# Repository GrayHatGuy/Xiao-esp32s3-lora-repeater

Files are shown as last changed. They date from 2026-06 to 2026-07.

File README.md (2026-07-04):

# Xiao-esp32s3-lora-repeater

Xiao ESP32S3 LoRa cross-band repeater — **two SX1262 radios on one Xiao**, or **four** by linking a second Xiao over a UART crossover.

Two SX1262 radios stacked on a single Xiao ESP32S3 (2-radio bridge)

*2-radio bridge — two SX1262 shields on one Xiao.*

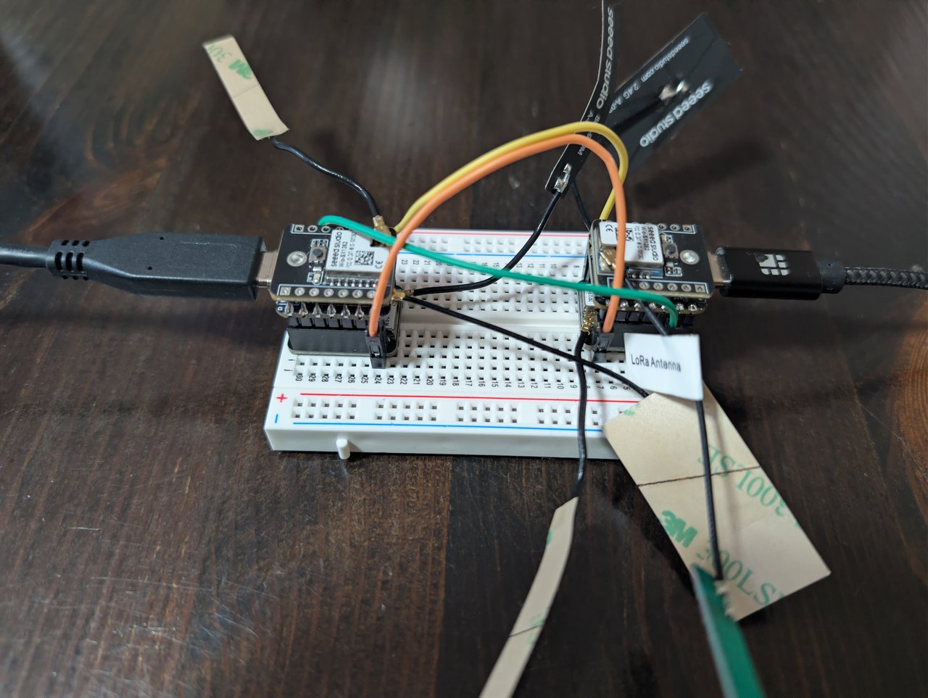
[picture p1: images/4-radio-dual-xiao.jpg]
Four-radio bridge — two Xiao ESP32S3 boards, each with stacked SX1262 shields, joined by a UART crossover on a breadboard


*4-radio bridge — two Xiao linked by a UART crossover (optional).*

## Introduction / Background

A bidirectional LoRa mesh bridge running on a single Seeed Xiao ESP32S3 Sense with two Seeed Wio SX1262 shields stacked back-to-back — one mated to the Xiao's edge pins, the other to the 40-pin B2B header. The two radios share one SPI bus through a FreeRTOS mutex and each run in their own task pinned to a separate ESP32-S3 core, so they can transmit and receive in parallel on completely different RF profiles. **Optionally, two of these boards can be linked over a short UART crossover to expand the bridge to four radios** — one Xiao acts as the *master* (its captive portal owns the config for all four radios) and the second as a *radio co-processor* — for a four-radio omnidirectional repeater. A single Xiao still runs as the original two-radio bridge with no changes; see **Parts**, **Wiring**, and the [config user manual](CONFIG-USER-MANUAL.md) for the four-radio option. The same firmware also builds a **LoRa-commanded camera** — a XIAO ESP32S3 Sense (OV2640 + microSD) plus one edge SX1262, with an always-on WPA2 web portal, signed LoRa command-and-control, and photo/video capture to the SD; see **[LoRaCam](#loracam--lora-commanded-camera)**.

Each radio carries its own protocol **and** its own channel. The bridge relays packets received on one radio out the other — *cross-protocol* (e.g. Meshtastic↔MeshCore) or *same-protocol between two channels* (e.g. a private channel bridged to the public one). Each radio runs one of six protocols: **Meshtastic**, **MeshCore**, **Reticulum**, **LoRaWAN** (keyless tap + keyed ABP uplink encoder), **Custom** (any user-defined RF plan / sync word), or **None** (radio disabled). Everything — region, per-radio protocol, RF plan (frequency, bandwidth, spreading factor, coding rate, sync word, TX power), channels and identity — is configured through the WiFi captive portal; see the **[config user manual](CONFIG-USER-MANUAL.md)** for a field-by-field walkthrough and compile-time preloading. A single `.bin` flashed with no build flags first-boots straight into the portal, so no PlatformIO build is needed to deploy.

Supported today:

- **Meshtastic** (sync `0x2B`) — AES-CTR + a hand-written protobuf walker that lifts `TEXT_MESSAGE_APP` payloads out of the on-air `Data` submessage. `POSITION_APP` and `TELEMETRY_APP` are also decoded and bridged as compact text lines (`pos 40.7234,-74.0123 alt 12m`, `bat 87% 4.05V`, `env 22.5C RH 45% 1013hPa`). Defaults to the public LongFast channel; override `BRIDGE_MT_CHANNEL_NAME` / `BRIDGE_MT_PSK_B64` (or use the captive portal) to bridge a private channel — the PSK can be a short key, a 16-byte AES-128 key, or a 32-byte AES-256 key, and the channel hash is auto-derived. The bridge decodes incoming `NODEINFO_APP` packets into a 64-entry NVS-persistent NodeDB and emits its own periodic NodeInfo so phones surface the bridge as a known sender (`!b16b00b5`, "LoRa Bridge"). It also learns wall-clock time opportunistically from a `POSITION_APP` time field, so bridged MeshCore packets carry a real timestamp.
- **MeshCore channel** (sync `0x12`) — AES-128-ECB decrypt of `GRP_TXT`, with the 2-byte truncated HMAC-SHA256 verified against the channel key. Defaults to the MeshCore public channel (hash `0x11`); override `BRIDGE_MC_KEY_HEX` / `BRIDGE_MC_CHANNEL_NAME` in `platformio.ini` to bridge a private or custom channel instead — the on-air channel-hash byte is auto-derived from `SHA-256(key)[0]` at boot.
- **Reticulum / RNode** (sync `0x42`) — incoming frames are base64-encoded and bridged into the other mesh as text packets of the form `[rns <seq> <x>/<y>] <base64>`. The bridge auto-fragments across multiple MT/MC packets when a single one wouldn't hold the encoded frame, using a CRC-16 low-byte sequence ID so concurrent fragmented frames don't get mixed up on the receiving side. Fragments are paced by the per-radio **airtime throttle** (max 8 fragments per frame, tunable via `BRIDGE_RNS_*`). With both radios set to Reticulum, the bridge **transparently raw-repeats** RNS frames byte-for-byte — a range-extending RNS↔RNS repeater (`BRIDGE_RNS_INPROTO_REPEAT`, on by default). A proper `MT/MC → RNS` packet encoder is still TODO; until then that direction is a log-and-drop path on serial.
- **LoRaWAN** (sync `0x34`, **keyless**) — a localized capture/relay tap, *not* a gateway. The bridge reads only the **cleartext LoRaWAN MAC header** (MType, DevAddr, FCtrl, FCnt, FPort, FRMPayload length; JoinEUI/DevEUI on join-requests) — no keys, no payload decryption, no `FCnt`/MIC synthesis. It can log the header (`evt=RX proto=LW …`), emit a one-line metadata **summary** into your Meshtastic/MeshCore mesh (`BRIDGE_LW_SUMMARY_TO_MESH`), and **transparently raw-repeat** `0x34` frames between two LoRaWAN radios/bridges as a dedup-bounded flood (`BRIDGE_LW_RELAY`) — modeled on the [Tasmota LoRaWAN bridge](https://tasmota.github.io/docs/LoRa-and-LoRaWan-Bridge/). By default `MT/MC → LoRaWAN` is a deliberate log-and-drop (`no-lw-encoder`) — keyless firmware can't inject content. **New in v8.4:** an opt-in **keyed ABP uplink encoder** (`BRIDGE_LW_ENCODE` + ABP session keys) turns that path into a real LoRaWAN encode — it wraps decoded mesh (MT/MC) traffic into a valid LoRaWAN 1.0.x **ABP uplink** (DevAddr + `NwkSKey` + `AppSKey`, AES-CTR FRMPayload, AES-CMAC MIC, monotonic FCnt) and re-emits it over RF for an existing gateway to forward to a ChirpStack LNS. The encoder is **hardware-verified on air** (2026-06-16) — Meshtastic *and* MeshCore frames encode to valid ABP uplinks that decrypt back to the original text with a valid MIC; per-source ABP devices are **captive-portal–configured** with a reboot-safe FCnt, and a raw-LoRa / **Custom** source (the weather-station case) wraps its raw bytes into an uplink too. **The only remaining bench item is ingestion by a live ChirpStack LNS** (Tier C) — see [`BENCH-RESULTS.md`](BENCH-RESULTS.md). Single-channel per radio (no channel hopping, no Class-A RX windows).

### Routing & behavior

Every received packet is decoded once, run through a content-hash loop/dup guard, re-encoded for the *other* radio's protocol, and queued for a non-blocking transmit. The behavior worth calling out:

- **Clean far-side bodies.** The old `[MT !id name]` / `[MC]` / `[rns]` text markers are gone. Loop prevention is now a **TTL content-hash dedup** (FNV-1a over the decoded body + sender id + Meshtastic packet_id, recorded on receive *and* on every emission), which also drops the same packet heard on both radios and never false-drops a user message that happens to start with `[MT`. Folding the packet_id lets a node's genuinely-distinct messages with identical text through each time (new id → new hash) while echoes/replays (same id) still drop.
- **A repeat looks like it came from the original sender, not the bridge.** Cross-protocol **MC→MT** reconstructs the MeshCore sender as a *deterministic virtual Meshtastic node* (id = `FNV-1a("MC|"+name)`) and advertises a synthetic NodeInfo, so a phone shows the message from `Alice @MC`. Cross-protocol **MT→MC** prefixes the body with the Meshtastic sender's name (`Alice@MT: …`, NodeDB short-name or `!hexid`) — the only identity channel MeshCore group text offers. A **same-protocol, same-channel** pair on different frequencies is a *transparent raw repeat*: the original bytes go out unchanged (Meshtastic: hop_limit decremented, `relay_node` set), so the far side sees the original sender natively. The `@MT`/`@MC` origin tags are on by default (`BRIDGE_TAG_ORIGIN_PROTO=0` for bare native-looking names). The whole layer can be disabled with `-DBRIDGE_IDENTITY_PRESERVE=0` (clean-body / bridge-identity behaviour).
- **TX never clobbers RX.** Each radio defaults to receive; an outbound packet goes onto a per-destination, age-bounded, PSRAM-backed queue and is sent by a CAD-gated (listen-before-talk) non-blocking transmit with CSMA backoff and a duty-cycle airtime throttle. So a long SF11 transmit no longer makes the bridge deaf.
- **Structured serial logs.** The runtime log is now one greppable `ts=… evt=… radio=… key=val` line per pipeline event (`RX`/`DEDUP_PASS`/`DROP`/`QUEUE`/`CAD`/`TX_START`/`TX_DONE`/`THROTTLE`/`NODEDB`/`NODEINFO`/`CLOCK`), emitted atomically across both cores.
- **Real timestamps without an RTC (clock-learn).** The bridge has no RTC/NTP, so it *learns* wall-clock time — from inbound MeshCore packet timestamps (**v8.2.1**) and from Meshtastic `POSITION_APP` time (**v8.3**) — and stamps that real Unix time onto bridged MeshCore `GRP_TXT` (surfaced as `mcts=` and a one-time `evt=CLOCK`). Before this, `MT→MC` / `RNS→MC` hardcoded the timestamp to 0 and clients showed *1969*. A cold boot still stamps `0` only until the first timestamped packet calibrates it (inherent without an RTC).
- **Same-protocol transparent repeat spans every protocol.** Two radios on the *same* protocol + channel at *different* frequencies raw-repeat byte-for-byte — a range extender — for Meshtastic, MeshCore, **Reticulum (`RNS↔RNS`, v8.3)** and **LoRaWAN (`LW↔LW`, v8.3)**. The RNS / LoRaWAN repeats are byte-exact (no header mutation — a LoRaWAN MIC would break otherwise), loop-bounded by the shared content-hash dedup + the airtime throttle.
- **LoRaWAN: keyless tap, plus a keyed encoder (v8.4).** A `0x34` radio runs a keyless capture / metadata-summary / `LW↔LW` relay tap (**v8.3**). **v8.4** adds an opt-in **keyed ABP uplink encoder**: with ABP credentials set, `MT/MC → LoRaWAN` becomes a real ABP-uplink encode that RF-re-emits to a gateway → ChirpStack LNS (**hardware-verified on air** — MT *and* MC frames decrypt back, MIC valid; only the live-ChirpStack ingestion bench is open — [`BENCH-RESULTS.md`](BENCH-RESULTS.md)); with no keys it stays the keyless `no-lw-encoder` drop. The two modes are mutually exclusive per radio, selected by ABP config — and as of v8.4 the encoder ships in the standard V1.0/V1.1 build (dormant until configured), so a stock MT/MC bridge is **behaviourally** unaffected.
- **Per-radio routing matrix (4-radio).** With a second Xiao linked over the UART crossover you get four radios, and each one picks which of the others it bridges its received traffic to — a **"bridge received traffic to"** grid in the portal: `R1 → R2/R3/R4`, `R2 → R1/R3/R4`, `R3 → R1/R2/R4`, `R4 → R1/R2/R3`, each destination selectable independently. So you choose the topology — full four-way mesh, two independent pairs, or a one-way feed — rather than a fixed all-to-all. The default two-radio bridge is just `R1 ↔ R2` with R3/R4 disabled; cross-protocol translation and the loop/dup guard apply on every hop exactly as above.

**Everything above is tunable at compile time.** All flags are optional, each documented with its compiled-in default in [`platformio.ini`](platformio.ini); see the **[config user manual](CONFIG-USER-MANUAL.md)** for the full build-flag catalog.

All crypto runs on the ESP-IDF's built-in mbedTLS — no extra library dependencies beyond `jgromes/RadioLib` (pinned `7.7.0`).

**What's new in each release:** see [`CHANGELOG.md`](CHANGELOG.md) for the full per-version changelog. The latest is **v10.0 — LoRaCam**: the same firmware now builds a **LoRa-commanded camera** — a XIAO ESP32S3 Sense (OV2640 + microSD) plus one hand-wired edge SX1262, with encrypted / sender-whitelisted / replay-protected LoRa command-and-control, signed photo & video capture to microSD, and an always-on WPA2 web portal (live MJPEG, snap/record, SD browser, config, pairing) — plus an optional multi-hop C2 relay. All camera code is build-flag-gated (`-DBRIDGE_ROLE_CAMERA`), so the stock bridge binaries stay **byte-identical**; see **[LoRaCam](#loracam--lora-commanded-camera)**, [`LORACAM-SPEC.md`](LORACAM-SPEC.md) and [`BENCH-PHASE3.md`](BENCH-PHASE3.md). Prior release **v9.0 — the optional four-radio bridge**: link a second Xiao over a UART crossover for **four sub-GHz SX1262 radios** driven by a per-radio routing matrix, while a single Xiao stays **fully backwards-compatible** as the original two-radio bridge (R3/R4 default to disabled — see **[Wiring](#wiring)** and the [config user manual](CONFIG-USER-MANUAL.md)). It builds on the **v8.4 LoRaWAN ABP uplink encoder** ([v8.4 release](https://github.com/GrayHatGuy/Xiao-esp32s3-lora-repeater/releases/tag/v8.4-ABP-lorawan)) — **hardware-verified on air** (Meshtastic *and* MeshCore → valid ABP uplinks, decrypt-verified, MIC-valid; only live-ChirpStack ingestion remaining — [`BENCH-RESULTS.md`](BENCH-RESULTS.md)) — and the **[v8.3.1 release](https://github.com/GrayHatGuy/Xiao-esp32s3-lora-repeater/releases/tag/v8.3.1)** (Radio-2 V1.0/V1.1 fix). Design + bench docs: [`CONFIG-USER-MANUAL.md`](CONFIG-USER-MANUAL.md), [`BENCH-v9.0.md`](BENCH-v9.0.md) (four-radio bench), [`ABP-LORAWAN-SPEC.md`](ABP-LORAWAN-SPEC.md).

**Per-protocol summary** — the bridge dispatches by **LoRa sync word**; each radio is assigned a protocol in the portal, and a received packet is decoded once, run through the content-hash loop/dup guard, re-encoded for the *other* radio's protocol, and queued for a CAD-gated non-blocking transmit. Source identity is preserved/reconstructed across the bridge (see [`V8.2-SPEC.md`](V8.2-SPEC.md)).

| Protocol | Sync | RX (decode) | Bridge / TX | Identity across the bridge |
|---|---|---|---|---|
| **Meshtastic (MT)** | `0x2B` | AES-CTR + protobuf walk: `TEXT_MESSAGE_APP`, `POSITION_APP`, `TELEMETRY_APP` → text line; `NODEINFO_APP` → NodeDB (not bridged) | Re-encodes for the destination. **Same channel, different frequency → transparent raw repeat** (original bytes, `hop_limit` decremented) | **MT→MC:** body prefixed `Name@MT:` (NodeDB short-name, else `!hexid`). **MT→MT raw repeat:** original sender preserved natively |
| **MeshCore (MC)** | `0x12` | AES-128-ECB `GRP_TXT` + 2-byte HMAC verify | Re-encodes `GRP_TXT` for the destination channel; same-channel/diff-freq → raw repeat | **MC→MT:** the `"Name: …"` sender becomes a deterministic virtual MT node `FNV-1a("MC|name")` with a synthetic NodeInfo (`Name @MC`); the name is moved into the MT header and stripped from the body |
| **Reticulum (RNS)** | `0x42` | **Not decrypted** — frame treated as opaque bytes (the bridge holds no RNS keys) | **RNS↔RNS:** transparent byte-for-byte raw repeat (range extender, `BRIDGE_RNS_INPROTO_REPEAT`). **RNS→MT/MC:** base64-tunneled as `[rns <seq> <x>/<y>] …` text fragments (CRC-16 seq id, 8-fragment cap, airtime-throttle-paced). **MT/MC→RNS: not implemented** (log-and-drop). See the [Reticulum roadmap](#reticulum--rnode-routing) | n/a — frames opaque; RNS→MT fragments carry the bridge's own MT id |
| **LoRaWAN (LW)** | `0x34` | **Keyless on RX** — cleartext MAC header only (MType / DevAddr / FCtrl / FCnt / FPort / len; JoinEUI/DevEUI on joins); no key, no received-payload decrypt (the **keyed** side is TX-encode only → see Bridge / TX) | **Capture** log + **metadata summary** to MT/MC (`BRIDGE_LW_SUMMARY_TO_MESH`); **LW↔LW transparent raw relay / dedup-bounded flood** (`BRIDGE_LW_RELAY`). **`MT/MC/Custom → LW`: keyed ABP uplink encoder (v8.4, opt-in)** — per-source ABP devices (portal-configured, reboot-safe FCnt) transcode to a valid LoRaWAN ABP uplink (CMAC MIC + AES-CTR FRMPayload + monotonic FCnt); a raw-LoRa **Custom** source sends its raw bytes (weather station). RF-re-emits for a gateway → ChirpStack (**hardware-verified on air**; only live-ChirpStack ingestion pending — [`BENCH-RESULTS.md`](BENCH-RESULTS.md)); default (no keys) stays the keyless `no-lw-encoder` drop | keyless tap: summaries carry the bridge's own MT/MC id. ABP encode: each uplink is sent under a bridge-held ABP device identity (DevAddr) |
| **Custom** | any (portal-entered) | user-chosen sync word; **no built-in decoder** | RF-agnostic dispatch by sync word; a Custom radio with no matching decoder receives + logs but has no protocol-specific re-encode | n/a |
| **None** | — | radio disabled (single-radio / monitor mode) | — | — |

Per-radio fields, the LoRaWAN ABP-device section and every build flag are documented in the **[config user manual](CONFIG-USER-MANUAL.md)**.

## Parts Required

| Part | Notes |
|---|---|
| [Wio SX1262 with Xiao ESP32S3 (B2B 40-pin)](https://www.seeedstudio.com/Wio-SX1262-with-XIAO-ESP32S3-p-5982.html) | Radio 1 (B2B). Kit ships with the Xiao ESP32S3 Sense MCU |
| [Wio SX1262 for Xiao (edge-pin)](https://www.seeedstudio.com/Wio-SX1262-for-XIAO-p-6379.html) | Radio 2, sits on the Xiao's edge-pin header |
| 2 × LoRa antennas tuned for your ISM band | **Don't skip this.** Running an SX1262 at +20 dBm into a missing antenna kills your TX range and risks the PA |
| USB-C cable | Power, programming, serial monitor |

**Optional — four-radio bridge.** Add a **second** of everything above: another *Wio SX1262 with Xiao (B2B)* kit and a *Wio SX1262 for Xiao (edge)* for Radios 3/4, plus **two more antennas**. The two boards are joined with **3 jumper wires** (TX, RX, GND) for the UART crossover; power each board from its own USB-C, or jumper a shared 3V3 rail (see [Wiring](#wiring)). A small breadboard makes the crossover tidy.

*Some assembly required.*

## Wiring

This build uses **stacked shields** — there is no hand-wiring. The B2B SX1262
(Radio 1) mounts on the Xiao's 40-pin board-to-board connector; the edge-pin
SX1262 (Radio 2) mounts on the Xiao's perimeter header. The pin mapping is set in
the firmware (see `src/main.cpp`).

> ⚠️ **The Radio 2 edge module ships in two board revisions (V1.0 / V1.1) with
> different pinouts — you must build the firmware variant that matches yours.**
> Check the silkscreen first: see [Radio 2 module revision](#radio-2-module-revision-v10-vs-v11) below.

The table shows Radio 2 for **both module revisions** — build the env that matches your silkscreen ([how to identify yours](#radio-2-module-revision-v10-vs-v11)). **Bold** marks the four Radio-2 signals that move between V1.0 and V1.1 (NSS, DIO1, BUSY, ANT_SW); the shared SPI bus and RESET are identical on both.

| Signal | Radio 1 (B2B) | Radio 2 — **V1.0** (`xiao_esp32s3`) | Radio 2 — **V1.1** (`xiao_esp32s3_v1_1`) | Notes |
|---|---|---|---|---|
| SCK | GPIO7 (D8)  | GPIO7 (D8) | GPIO7 (D8) | **shared** SPI bus |
| MOSI | GPIO9 (D10) | GPIO9 (D10) | GPIO9 (D10) | **shared** |
| MISO | GPIO8 (D9)  | GPIO8 (D9) | GPIO8 (D9) | **shared** |
| NSS / CS | GPIO41 | **GPIO5 (D4)** | **GPIO4 (D3)** | per-radio chip select |
| DIO1 / IRQ | GPIO39 | **GPIO2 (D1)** | **GPIO1 (D0)** | RX-done interrupt |
| RESET | GPIO42 | GPIO3 (D2) | GPIO3 (D2) | per-radio (same on both revs) |
| BUSY | GPIO40 | **GPIO4 (D3)** | **GPIO2 (D1)** | per-radio |
| ANT_SW | GPIO38 | **GPIO6 (D5)** | **GPIO5 (D4)** | TX/RX RF switch |
| VCC | 3V3 | 3V3 | 3V3 | |
| GND | GND | GND | GND | |

**Optional — four-radio UART crossover.** For the four-radio bridge the two Xiao
boards are joined on their `Serial1` UART (`D6`/`D7`). Both boards run the same
firmware pin defaults, so **the cable does the crossover** — TX on one must reach
RX on the other:

| Master Xiao | → | Co-processor Xiao | Notes |
|---|---|---|---|
| **D6** / GPIO43 (TX) | → | **D7** / GPIO44 (RX) | crossed |
| **D7** / GPIO44 (RX) | ← | **D6** / GPIO43 (TX) | crossed |
| **GND** | — | **GND** | **required** — common ground |
| *3V3 or 5V* | — | *3V3 or 5V* | *only if powering both from one supply (see below)* |

- **Link speed** 460800 baud (override `BRIDGE_LINK_TX_PIN` / `_RX_PIN` / `_BAUD`).
- **Power:** simplest is a **separate USB-C to each board**. To run both from one
  supply, also jumper a **shared 3V3 (or 5V) rail** between them in addition to GND.
- Each board keeps its own two SX1262 shields + antennas — **four antennas total**.

> ⚠️ The data pair must be **crossed**: Master **D6 → co-proc D7** *and* Master
> **D7 → co-proc D6**. An un-crossed pair often looks half-working — one direction
> fine, the return line dead.

**Key points**

- The two radios **share one SPI bus** (SCK/MOSI/MISO); the firmware serializes
  access with a FreeRTOS mutex.
- Each radio has its own **NSS, DIO1, RESET, BUSY, ANT_SW**, so they run
  independently — one task per ESP32-S3 core.
- Radio 1's pins (GPIO38–42) are exposed **only on the 40-pin B2B connector**.
- The TCXO is internal to each Wio SX1262 module (1.8 V) — not wired to a GPIO.
- **Connect both u.FL antennas before power-on** — transmitting into a missing
  antenna risks the PA.
- **Four-radio option:** the second Xiao runs a small co-processor firmware and
  has **no portal of its own** — the master Xiao owns the config for all four
  radios and pushes Radio 3 / Radio 4's RF to the co-processor over the UART link
  at boot (and re-pushes automatically if the co-processor reboots). Leave Radio 3
  / Radio 4 **disabled** (the default) and the master never opens the link — it's a
  plain two-radio bridge.

### Radio 2 module revision (V1.0 vs V1.1)

**Seeed shipped the "Wio-SX1262 for XIAO" edge module with two different
pinouts.** The chip-select (NSS) moved between revisions, so flashing the wrong
variant means **Radio 2 won't be detected** (the bridge keeps running on Radio 1
alone and tells you which env to flash). Identify your module and build the
matching env.

Read the white silkscreen on the **Radio 2** module — both the version string and
the right-hand pin column:

| | **V1.0** | **V1.1** |
|---|---|---|
| Silkscreen | `Wio-SX1262 for XIAO V1.0` | `Wio-SX1262 for XIAO V1.1` |
| Right column (top→bottom) | D0, DIO1, RST, BUSY, **NSS**, RF_SW, D6 | DIO1, BUSY, RST, **NSS**, RF_SW, D5, D6 |
| **NSS** lands on | **D4 / GPIO5** | **D3 / GPIO4** |
| Build env | `xiao_esp32s3` (default) | `xiao_esp32s3_v1_1` |

| V1.0 | V1.1 |
|---|---|
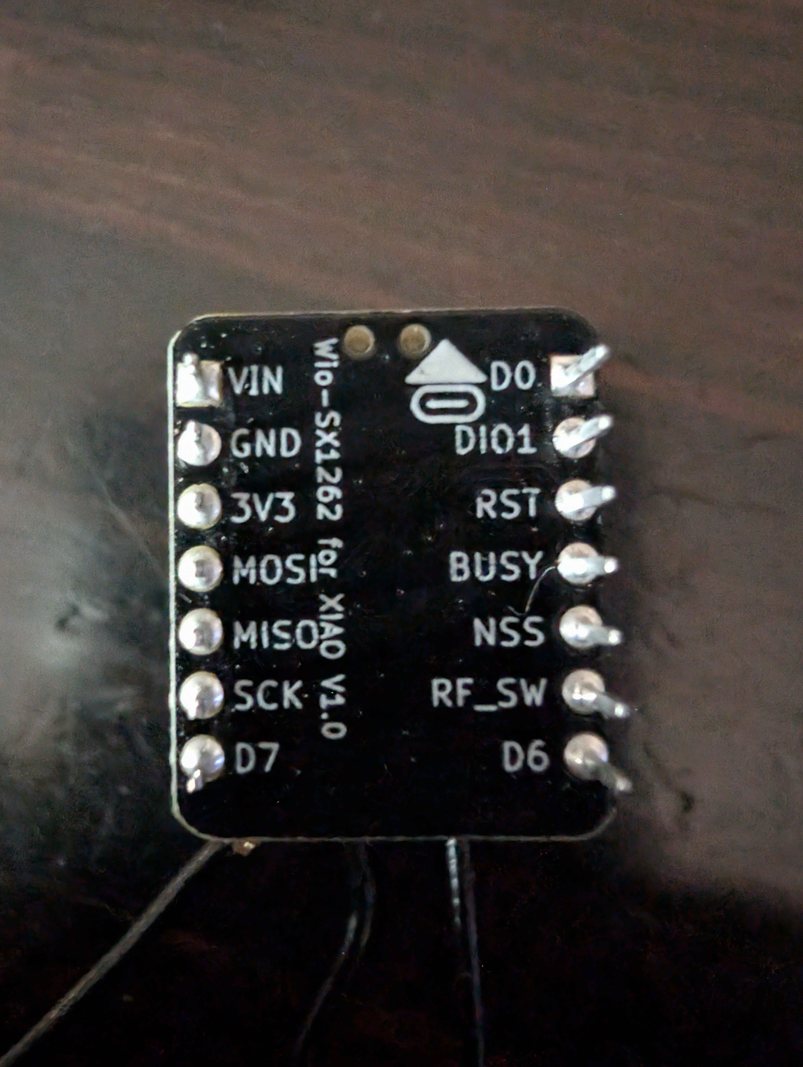
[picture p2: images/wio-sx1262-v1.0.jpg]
Wio-SX1262 for XIAO V1.0 silkscreen
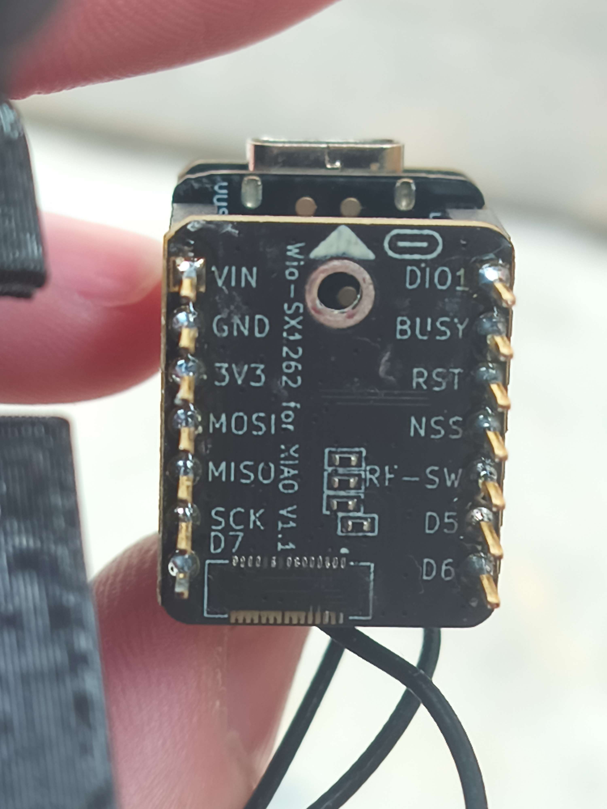
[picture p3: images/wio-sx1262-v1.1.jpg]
Wio-SX1262 for XIAO V1.1 silkscreen
|  |  |

```bash
# V1.0 module (default):
pio run -e xiao_esp32s3      -t upload --upload-port COMx
# V1.1 module:
pio run -e xiao_esp32s3_v1_1 -t upload --upload-port COMx
```

For the **optional four-radio bridge**, the second (co-processor) Xiao is its own
PlatformIO sub-project — build it with `-d coproc-xiao-sx1262`, picking the env that
matches *that board's* Radio-2 silkscreen:

```bash
# Co-processor — V1.0 edge module:
pio run -d coproc-xiao-sx1262 -e xiao_coproc_sx1262      -t upload --upload-port COMx
# Co-processor — V1.1 edge module:
pio run -d coproc-xiao-sx1262 -e xiao_coproc_sx1262_v1_1 -t upload --upload-port COMx
```

The firmware prints the revision it was built for at boot, so you can confirm from
the serial log:

```
[diag] R2 edge module = V1.0  (NSS=5 DIO1=2 RST=3 BUSY=4 RF_SW=6)
```

## LoRaCam — LoRa-commanded camera

**A camera that runs on this same firmware.** LoRaCam is a build variant (`-DBRIDGE_ROLE_CAMERA`) that turns a **XIAO ESP32S3 Sense** — the OV2640 camera, mic and microSD slot already on its rear B2B daughterboard — plus **one Wio SX1262 edge radio** into a LoRa-commanded, WiFi-viewable camera node. It reuses the bridge's radio stack, crypto, captive-config form and do-no-harm gating wholesale; every camera line is compiled only under the camera flag, so the stock bridge binaries stay **byte-identical** (`xiao_esp32s3` = 865781 B). Design of record: [`LORACAM-SPEC.md`](LORACAM-SPEC.md); bench evidence: [`BENCH-PHASE3.md`](BENCH-PHASE3.md), [`BENCH-CAMC2.md`](BENCH-CAMC2.md).

Three ways to use it:

- **Standalone** — the camera's own always-on **WPA2 web portal** does everything: live MJPEG video, snap / record / stop, browse the microSD, and the full radio/identity config form. No second device.
- **Paired** — a LoRa **commander** (any spare XIAO + Wio SX1262 on the same Custom `0x33` channel) sends *signed* commands over LoRa when the camera is out of WiFi range. Encrypted, sender-whitelisted, replay-protected.
- **Multi-hop** — a plain bridge relays those C2 frames commander → repeater → camera, so the camera needn't hear the commander directly (build flag `-DBRIDGE_CUSTOM_REPEAT`, off by default).

**Command-and-control** rides an encrypted binary frame on a **Custom sync-word `0x33`** radio: AES-CTR encrypt-then-MAC with an 8-byte AES-CMAC, a per-peer PSK, and a monotonic replay counter — a valid tag *is* the whitelist. Commands are snap photo, record video, stop, get status, plus operator text messaging. Media itself never travels over LoRa (airtime/duty forbid it) — LoRa carries only the command, the result, and the filename; the portal serves the actual JPEG/AVI. A signed `snap` writes a real 800×600 JPEG to `/loracam/IMG_%05u.jpg` and returns the filename in the ACK; `record` writes an MJPEG-AVI to `/loracam/VID_%05u.avi` (~5 fps, plays in VLC). The microSD shares the radio's SPI bus (CS = GPIO21), serialized by the same mutex.

### Parts — LoRaCam

| Part | Notes |
|---|---|
| [Seeed XIAO ESP32S3 **Sense**](https://www.seeedstudio.com/XIAO-ESP32S3-Sense-p-5639.html) | The Sense daughterboard carries the OV2640 camera, mic **and** microSD — snaps onto the rear 40-pin B2B connector, no wiring |
| [Wio SX1262 for Xiao (edge-pin)](https://www.seeedstudio.com/Wio-SX1262-for-XIAO-p-6379.html) | The single LoRa radio (R2). **Hand-wired with flying leads**, not stacked — see below |
| LoRa antenna (u.FL) tuned for your ISM band | **Fit it before power-on** — the node beacons on boot; TX into a missing antenna risks the PA |
| microSD card | Photo/video storage; formatted FAT32 |
| USB-C cable | Power, programming, serial monitor |

> The B2B (Radio 1) slot is **occupied by the camera/mic bus** (GPIO38–42), so a camera build runs **Radio 1 disabled** and uses only the edge radio. The camera daughterboard and the edge radio's baseboard both want the XIAO's underside, so the edge radio can't stack — it is **hand-wired with 9 flying leads** to the XIAO's edge pins.

### Wiring — LoRaCam (9 flying leads)

Wire the **Wio SX1262 edge module** to the XIAO's edge pins. This is the **same R2 pin map** as the bridge's edge radio ([Wiring](#wiring) above) — flying leads instead of a stacked header. The map below is **V1.0**; for a **V1.1** module use the V1.1 Radio-2 column from the [Wiring table](#wiring) and build with `-DWIO_SX1262_REV=11`. Leave **RF_SW open** (unconnected). The camera, mic and microSD need **no wires** — they're on the rear daughterboard.

| Wio SX1262 edge pad | → | XIAO pin (V1.0) | Notes |
|---|---|---|---|
| 3V3  | → | 3V3 | |
| GND  | → | GND | |
| SCK  | → | D8 (GPIO7)  | shared SPI bus (also the microSD's) |
| MISO | → | D9 (GPIO8)  | shared |
| MOSI | → | D10 (GPIO9) | shared |
| NSS  | → | D4 (GPIO5)  | radio chip select |
| BUSY | → | D3 (GPIO4)  | |
| RST  | → | D2 (GPIO3)  | |
| DIO1 | → | D1 (GPIO2)  | RX-done interrupt |
| RF_SW | | *(leave open)* | not connected |

> ⚠️ **Fit the u.FL antenna before first power-on** — the node TXes a beacon autonomously on boot. A camera-init inrush + TX ramp + SD write can brown-out the 3V3 rail; add bulk capacitance on 3V3 if you see resets.

### Build & flash — LoRaCam

The camera is its own PlatformIO env, `xiao_loracam`. A fresh board **first-boots straight into the WPA2 portal** (no open AP). For a **V1.1** edge module add `-DWIO_SX1262_REV=11`.

```bash
# V1.0 edge module (default):
pio run -e xiao_loracam -t upload --upload-port COMx
# then open the serial monitor to see the AP come up:
pio device monitor --port COMx
```

> ⚠️ `pio run -t erase` wipes the **whole** flash (app included) — always follow it with `-t upload`.

### Using it — the web portal

1. **Join the camera's WiFi.** SSID `LoRaCam-XX` (`XX` = low byte of the MAC-derived node id), WPA2 passphrase `loracam-portal` (change it on the Security tab).
2. **Open** `http://192.168.4.1` and **log in** — default `admin` / `loracam-admin`.
3. **Home** — live MJPEG video, with **snap / record / stop / status** buttons and operator messaging.
4. **Photos** — browse, view, download or delete the photos and videos on the microSD.
5. **Config** — the full radio / identity form (the same one the bridge captive portal serves); **Pairing** — manage the trusted-commander whitelist; **Security** — change the WiFi passphrase and the portal login.

The full field-by-field walkthrough — every portal screen, its build flag, and example setups — is in the [config user manual](CONFIG-USER-MANUAL.md).

### Pairing a LoRa commander

To command the camera over LoRa (out of WiFi range), pair a **commander** — any spare XIAO + Wio SX1262 on the same Custom `0x33` channel. On the camera's **Pairing** page, add the commander's 8-hex C2 id and the shared 32-hex PSK, and mark it **Primary**. On the commander, whitelist the camera with the **same** key. Thereafter the commander mints signed commands and the camera ACKs unicast to whoever sent them; beacons broadcast to any in-range whitelisted commander. For a bench pair, the `bench_camc2` (camera) and `bench_camc2_cmdr` (commander) envs come pre-provisioned — in the commander's serial monitor, type `s` = snap, `r` = record 30 s, `x` = stop, `g` = get-status, `m` = message. Bench record: [`BENCH-CAMC2.md`](BENCH-CAMC2.md).

### Multi-hop

A plain bridge can relay C2 frames **commander → repeater → camera**, so the camera never has to hear the commander directly. Build the relay with `-DBRIDGE_CUSTOM_REPEAT` (a flag-gated Custom same-channel raw-repeat, **off by default** so stock builds stay byte-identical) — set both of its radios to Custom `0x33` on the same channel, on different frequencies, and route `R1 ↔ R2`. Proven on a 3-board frequency-split rig (the camera on `906.875` cannot hear the commander on `905`; with the repeater down, the camera stays silent — a clean negative control). See [`BENCH-PHASE3.md`](BENCH-PHASE3.md) and the [config user manual](CONFIG-USER-MANUAL.md).

## Instructions

> **Fastest path (no toolchain).** **First check your Radio 2 module's silkscreen revision** ([Radio 2 module revision](#radio-2-module-revision-v10-vs-v11) above) and download the **matching** `vanilla-factory` bin from the [latest release](https://github.com/GrayHatGuy/Xiao-esp32s3-lora-repeater/releases/latest): `…-v1.0-vanilla-factory.bin` for a **V1.0** Radio-2 module, `…-v1.1-vanilla-factory.bin` for **V1.1**. Connect both antennas and flash it to offset `0x0` — e.g. `esptool.py --chip esp32s3 write_flash 0x0 <bin>`, or drag it into the [ESP web flasher](https://espressif.github.io/esptool-js/) at address `0x0`. A fresh/erased device first-boots straight into the captive portal, so you can **skip to step 4** (bridge setup). The numbered steps below are for building from source.

1. **Stack the hardware.** Mate the B2B shield (radio 1) on top the Xiao, the edge-pin shield (radio 2) on bottom. Connect antennas to **both** radios before powering on. Correct orientation has all antennas on the same side.
2. **Install [PlatformIO](https://platformio.org/install)** — the VS Code extension is the easiest path.
3. **Build, flash & monitor.** Read the **Radio 2** silkscreen and pick the matching env (see [Radio 2 module revision](#radio-2-module-revision-v10-vs-v11) above): **V1.0** → `xiao_esp32s3` (default), **V1.1** → `xiao_esp32s3_v1_1`. Then erase, clean-build, flash and open the serial monitor (replace `COMx` with your port):
   ```bash
   # --- MASTER Xiao — V1.0 Radio-2 module (default) ---
   pio run -e xiao_esp32s3 -t erase --upload-port COMx     # wipe flash + NVS (boots into the portal)
   pio run -e xiao_esp32s3 -t clean
   pio run -e xiao_esp32s3
   pio run -e xiao_esp32s3 -t upload --upload-port COMx
   pio device monitor --port COMx

   # --- MASTER Xiao — V1.1 Radio-2 module ---
   pio run -e xiao_esp32s3_v1_1 -t erase --upload-port COMx
   pio run -e xiao_esp32s3_v1_1 -t clean
   pio run -e xiao_esp32s3_v1_1
   pio run -e xiao_esp32s3_v1_1 -t upload --upload-port COMx
   pio device monitor --port COMx
   ```
   The clean matters whenever a header changes. Building the wrong variant won't harm anything — Radio 1 still comes up and the boot log names the env to flash — but Radio 2 won't be detected with the default env if your board is **V1.1**, until you flash the matching variant. The boot log echoes the active map:
   ```
   default (V1.0): [diag] R2 edge module = V1.0 (NSS=5 DIO1=2 RST=3 BUSY=4 RF_SW=6)
   V1.1:           [diag] R2 edge module = V1.1 (NSS=4 DIO1=1 RST=3 BUSY=2 RF_SW=5)
   ```
   **Four-radio bridge — also flash the co-processor.** The second Xiao is a
   separate sub-project; build it with `-d coproc-xiao-sx1262` and the env matching
   *its own* Radio-2 silkscreen, on its own COM port:
   ```bash
   # Co-processor — V1.0 edge module (use xiao_coproc_sx1262_v1_1 for a V1.1 module)
   pio run -d coproc-xiao-sx1262 -e xiao_coproc_sx1262 -t erase  --upload-port COM_COPROC
   pio run -d coproc-xiao-sx1262 -e xiao_coproc_sx1262 -t upload --upload-port COM_COPROC
   ```
   The co-processor has no portal and is **silent on its own USB** — it relays its
   status to the master's serial log. With the UART crossover wired, the master
   prints `[coproc] R3 cfg ok …` / `R4 cfg ok …` once the link comes up.
4. **Bridge setup.** A fresh or erased board first-boots into an open WiFi access point named `LoRa-Bridge-XX`; join it from a phone or laptop and any web request redirects to the config form at `192.168.4.1`. There you set device region, per-radio protocol / RF / channel, identity, and the LoRaWAN ABP devices. To re-enter the portal on a configured board, reset it and press **BOOT** or send any serial character within ~5 s (or erase it). **For the full field-by-field walkthrough — every field, its build flag, the LoRaWAN ABP details, and ready-made example setups — see the [config user manual](CONFIG-USER-MANUAL.md).**
5. **Serial Debug Monitor.** Watch the bridge over USB serial. On a four-radio
   bridge, **monitor the master Xiao** — the co-processor relays its logs to the
   master (as `[coproc] …`), so its own USB port stays quiet:
   ```bash
   pio device monitor --port COMx
   ```
   Expect RX summary lines (size / RSSI / SNR), protocol-decoded summaries, bridge re-encode lines, NodeInfo broadcasts, and `loop-drop` messages when relay echoes come back to the bridge.

## Roadmap

### Other future work

- [x] ~~**v10.0: LoRaCam — a LoRa-commanded camera.**~~ — **done**; specced in [`LORACAM-SPEC.md`](LORACAM-SPEC.md). A XIAO ESP32S3 Sense (OV2640 + microSD) + one hand-wired edge SX1262 becomes a camera node: encrypted / sender-whitelisted / replay-protected C2 over Custom `0x33` (AES-CTR encrypt-then-MAC, 8-byte CMAC, per-peer PSK, monotonic replay counter), signed photo (`/loracam/IMG_*.jpg`) & video (`/loracam/VID_*.avi`) capture to microSD, an always-on **WPA2 web portal** (live MJPEG + snap/record/stop + SD browser + the config form + pairing + messaging), secure first-flash, and optional multi-hop C2 relay (`-DBRIDGE_CUSTOM_REPEAT`). All build-flag-gated (`-DBRIDGE_ROLE_CAMERA`) → stock bridge binaries **byte-identical**. Bench-proven on silicon ([`BENCH-PHASE3.md`](BENCH-PHASE3.md), [`BENCH-CAMC2.md`](BENCH-CAMC2.md)). See **[LoRaCam](#loracam--lora-commanded-camera)**.

- [x] ~~More Meshtastic portnums bridged: `POSITION_APP` and `TELEMETRY_APP`~~ — **done**; both decoded and re-emitted as text under the existing bridge marker. Individually gated by `BRIDGE_MT_POSITION` / `BRIDGE_MT_TELEMETRY` build flags. `NODEINFO_APP` is decoded into the NodeDB and intentionally not bridged as text.
- [x] ~~MeshCore private-channel support~~ — **done** via `MeshCoreConfig.{h,cpp}`; override `BRIDGE_MC_KEY_HEX` and `BRIDGE_MC_CHANNEL_NAME` in `platformio.ini` to point the bridge at any MC channel. The hash byte is computed automatically from `SHA-256(key)[0]`.
- [x] ~~Persistent NodeDB so `[MT] …` prefixes can be replaced with the actual sender's short name~~ — **done** in `NodeDB.{h,cpp}`; MT→MC bridged messages now carry `[MT !<hexid> <SHORT>] …` attribution learned from `NODEINFO_APP` packets and persisted to NVS.
- [x] ~~**WiFi captive-portal first-boot config.**~~ — **done** via `BridgeConfig.{h,cpp}` + `CaptivePortal.{h,cpp}`. On a fresh flash (or whenever the BOOT button is pressed within ~3 s of reset) the bridge brings up an open AP named `LoRa-Bridge-<XX>` and DNS-redirects all HTTP traffic to a config form for MT identity, MC key + channel name, and the POSITION/TELEMETRY toggles. Saving the form writes the schema-v1 blob to NVS and reboots into bridge mode. Per-radio LoRa params (frequency, BW, SF, CR, TX power, sync word) remain build-flag-only — a misstep there can put the radio out of band.
- [x] ~~**F5: Meshtastic private-channel support.**~~ — **done** via `MeshtasticConfig.{h,cpp}` (the symmetric counterpart to F3). A base64 PSK + channel name from `BridgeConfig` are expanded — empty→LongFast, 1-byte short key, 16-byte AES-128, 32-byte AES-256 — and the on-air channel hash is derived as `XOR-fold(name) ^ XOR-fold(key)`. The five MT decoders + two MT encoders take key length from `MeshtasticConfig::keyLen` so AES-256 channels work. `BridgeConfig` schema bumped to v2 (auto-migrates a v1 blob); captive portal gained a Meshtastic-channel section.

- [x] ~~**v2: per-radio channels — same-protocol relay.**~~ — **done** (v7.0). Each radio slot carries its own channel via the new `RadioChannel` struct (`MeshCoreConfig` / `MeshtasticConfig` are now stateless `resolve()` helpers, not singletons). The bridge relays cross-protocol MT↔MC *and* same-protocol MC↔MC / MT↔MT. Each radio's protocol/RF stays a `platformio.ini` build-flag decision; each radio's channel name + key is portal-editable. `BridgeConfig` schema bumped v2→v3 (auto-migrates). The portal's two channel sections reject identical channels when both radios share a protocol.
- [x] ~~**v8: vanilla firmware — full portal config.**~~ — **done** (v8.0); specced in [`V8-SPEC.md`](V8-SPEC.md). A single distributable `.bin` configured *entirely* through the captive portal — no build flags required. Per-radio protocol picker (Meshtastic / MeshCore / Reticulum / Custom / None), global region selector (US, EU_868, EU_433, ANZ, CN, JP, IN, KR, RU + Custom/Other), Tier 2 Meshtastic channel-slot frequency computation (`RegionPreset.h`) with an editable override, null defaults (a no-flag image first-boots straight into the portal), and MAC-derived identity/SSID. `BridgeConfig` schema v3→v4. `platformio.ini` `LORA_RADIO*` flags are now optional first-boot pre-seeding only.
- [x] ~~**Compile-time validation of build-flag config.**~~ — **done** (v8.1) in [`src/LoraConfigCheck.h`](src/LoraConfigCheck.h). `#error` / `static_assert` guards reject an invalid `LORA_RADIO*` set at build time (sync words, SF/CR/BW/region sanity, TX power range). Complements the v8 portal-side runtime validation — build-time checks defaults, portal checks portal-entered values.

- [x] ~~**v8.2: RX-priority routing redesign + source-identity preservation.**~~ — **done** (v8.2), bench-verified 2026-06-13; specced in [`V8.2-SPEC.md`](V8.2-SPEC.md). Non-blocking CAD-gated TX + per-destination PSRAM route queues + airtime throttle (a transmit no longer blocks the other radio's RX); content-hash dedup keyed on body + sender id + Meshtastic packet_id (replaces the `[MT]/[MC]/[rns]` text markers → clean far-side bodies); source-identity preservation (MC→MT virtual nodes + synthetic NodeInfo, MT→MC name prefixes, same-channel transparent raw repeat); structured `evt=` serial logging; RadioLib pinned 7.7.0.

- [x] ~~**v8.3: keyless LoRaWAN + carry-overs.**~~ — **done & shipped** (v8.3), bench-validated on hardware 2026-06-14; specced in [`V8.3-SPEC.md`](V8.3-SPEC.md). Keyless LoRaWAN (`0x34`) capture tap + metadata summary to MT/MC + transparent LW↔LW raw relay / dedup-bounded flood (`MT/MC → LoRaWAN` is a `no-lw-encoder` drop); transparent **RNS↔RNS** raw repeat; and Meshtastic `POSITION_APP` clock-learn. `BridgeConfig` schema v4 unchanged.

- [x] ~~**v8.4: LoRaWAN ABP uplink encoder (keyed).**~~ — **shipped** in v8.4 (build-green, crypto-verified, **hardware-verified on air**); specced in [`ABP-LORAWAN-SPEC.md`](ABP-LORAWAN-SPEC.md). A self-contained **RFC 4493 AES-CMAC** (the prebuilt esp32s3 mbedTLS ships CMAC disabled) + `encodeLoRaWANUplink()` mint valid LoRaWAN 1.0.x **ABP uplinks** (AES-CTR FRMPayload, CMAC MIC, monotonic FCnt, ADR off, Unconfirmed). The keyless `no-lw-encoder` drop becomes a keyed transcode → `g_routeQ` **RF re-emit** (delivery model B1) when ABP credentials are configured — opt-in via `BRIDGE_LW_ENCODE` + keys, so a stock build keeps v8.3's keyless behavior. Crypto cross-checked against an independent CMAC (RFC 4493 vectors + a MIC-valid, round-tripping frame). **P2–P4 also done:** per-source ABP devices + a captive-portal section + reboot-safe NVS FCnt (P2), the Custom raw-LoRa **weather-station** path + a sample ChirpStack codec (P3), and a US915 per-TX dwell cap (P4). The **hardware bench is complete** (12/16 — A1–B7 + A3, MT *and* MC verified — [`BENCH-RESULTS.md`](BENCH-RESULTS.md)); **live-ChirpStack (Tier C) ingestion is the one remaining gate** ([`BENCH-v8.4.md`](BENCH-v8.4.md)). v8.4 also added captive-portal **auto-fill of RF defaults on protocol switch** (a protocol change no longer leaves stale freq/BW/SF — the slip that cost a bench session).

**Next, in priority order — protocol routing comes _ahead of_ the Sub-GHz↔2.4 GHz cross-band phase below:**

- [ ] **Reticulum `MT/MC → RNS` encoder + reassembly.** RNS↔RNS repeat and RNS→MT/MC tunneling shipped in v8.3; the remaining half is a real RNS packet encoder (build a valid frame) plus `reassembleReticulumFragment()` so `MT/MC → RNS` works. Current state + work list in [Reticulum / RNode routing](#reticulum--rnode-routing) below.
- [ ] **LoRaWAN ABP *decode* + OTAA + dual-LNS (post-v8.4).** The keyless tap (v8.3) and the full **ABP uplink *encode*** (`MT/MC/Custom → LoRaWAN` — per-source portal devices P2, the Custom weather-station path + codec P3, and a US915 dwell cap P4) landed in **v8.4** (above), pending on-air bench. Remaining: the optional ABP/OTAA **decode** of your own fleet (→ MT/MC) and the dual-LNS crosslink — see [`ABP-LORAWAN-SPEC.md`](ABP-LORAWAN-SPEC.md). Content bridging without keys stays architecturally precluded (analysis in [`V8.2-SPEC.md`](V8.2-SPEC.md) §14).

- [ ] **Sub-GHz ↔ 2.4 GHz LoRa cross-band bridging — Phase 1 ON HOLD pending Seeed clarification.** The current build talks the SX1262's native sub-GHz ranges (902-928 MHz US ISM, 868 MHz EU, etc.). A long-horizon goal is to bridge those to 2.4 GHz LoRa networks (e.g. Meshtastic's 2.4 GHz preset) on the worldwide-licence-free **2.4 GHz ISM band** — the headline feature that makes this milestone worth doing.

  > **⚠️ Phase 1 status (2026-05-27): bench DOE complete — all firmware remedies refuted; Seeed engineering inquiry sent with full evidence package.** A first attempt at this milestone using the **Seeed Wio-LR1121 module (SKU 113991415)** as Radio 2 reached a hard block: TX works end-to-end (other LoRa receivers see the bridge's transmissions), but RX produces zero `RX_DONE` events for any over-the-air traffic — even with a transmitting MT phone's antenna physically pressed against the LR1121's antenna port. We then executed two full Design-of-Experiments (DOE) investigation phases per the **Semtech LR1121 User Manual v2.2** ([direct PDF](https://semtech.my.salesforce.com/sfc/p/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) · [product page](https://www.semtech.com/products/wireless-rf/lora-connect/lr1121)):
  >
  > - **Phase A — RFSWx switch-table sweep (12 iterations).** All 5 chip-level RFSWx-capable DIOs (DIO5/6/7/8/10 per UM §4.2.1) swept in every meaningful combination. Self-echo RSSI invariant within ~7 dB across all iterations. Zero OTA `RX_DONE`. Seeed's published KiCad library separately confirms DIO5/6/7 are routed as `MCU_DIO5/6/7` host-expansion test pads, **not** used as switch outputs on this module.
  > - **Phase B — Chip-init DOE (4 effective runs).** Tested every UM v2.2-prescribed firmware remedy individually and combined: `SetRssiCalibration` with UM Table 7-21 "600 MHz – 2 GHz" tunes (Run 2), `CalibImage(902, 928)` after `SetTcxoMode` (Run 3), and the kitchen-sink stack with pre-`Standby(STBY_RC)` + RSSI cal + image cal + `SetRxBoostedGainMode(true)` (Run 5). Every command returned `state=0`. **None resolved the RX failure.** Two new pieces of hard evidence emerged: (a) the chip's `GetErrors()` register reads `0x0020 = HF_XOSC_START_ERR` persistent at every POR on every unit, and (b) one `RADIOLIB_ERR_CRC_MISMATCH` event in Run 5 — meaning the RX chain is partially functional but with sensitivity degraded by an estimated 40–50 dB versus LR1121 datasheet spec. Two independently-sourced units behave identically.
  >
  > **All UM v2.2-prescribed firmware remedies have been tested. None resolves the failure.** Remaining hypothesis space: hardware-design issue (matching network, switch insertion loss, LNA isolation) or LR1121 chip firmware errata at base FW 1.3. The full bug report ([`SEEED_SUPPORT_INQUIRY.md`](https://github.com/GrayHatGuy/Xiao-esp32s3-lora-repeater/blob/lr1121-phase1/SEEED_SUPPORT_INQUIRY.md)) with the DOE evidence appended, the design-feedback companion ([`SEEED_RECOMMENDATIONS.md`](https://github.com/GrayHatGuy/Xiao-esp32s3-lora-repeater/blob/lr1121-phase1/SEEED_RECOMMENDATIONS.md)), the full DOE bench plan + results ([`LR1121-RX-INIT-AUDIT.md`](https://github.com/GrayHatGuy/Xiao-esp32s3-lora-repeater/blob/lr1121-phase1/LR1121-RX-INIT-AUDIT.md)), and the locked-in email body ([`SEEED_EMAIL_DRAFT.md`](https://github.com/GrayHatGuy/Xiao-esp32s3-lora-repeater/blob/lr1121-phase1/SEEED_EMAIL_DRAFT.md)) all live on the [`lr1121-phase1`](https://github.com/GrayHatGuy/Xiao-esp32s3-lora-repeater/tree/lr1121-phase1) branch and at the snapshot tag [`lr1121-bringup-2026-05-26`](https://github.com/GrayHatGuy/Xiao-esp32s3-lora-repeater/tree/lr1121-bringup-2026-05-26) for Seeed-correspondence stability. **`main` continues to ship the Phase 0 dual-SX1262 release (now v8.3.1, with v8.4 in progress on `dev-ABP-lorawan`).** Phase 1 will resume on Seeed engineering's reply, or via pivot to an alternate LR1121 carrier (Semtech LR1121DVK1, Ebyte E80-900M22S, or custom).

  **Minimum viable hardware change:** keep the existing Xiao Wio-SX1262 on one of the two slots, and swap *only the other slot* for a radio that can reach 2.4 GHz. The bridge needs exactly one 2.4-GHz-capable side; the SX1262 stays as the sub-GHz endpoint.

  **Prototype target:** the **Seeed Wio LR1121 breadboard** — already on hand, RadioLib-supported, multi-band on one die (sub-GHz **+ 2.4 GHz + S-band 1.9-2.1 GHz**), plus LR-FHSS. For this bridge it sits on the 2.4 GHz slot opposite the existing Xiao Wio SX1262; longer-term a single LR1121 could replace *both* SX1262s if collapsing to one radio family becomes interesting.

  Other Semtech parts to track for later, in roughly increasing capability:
  - **SX1280** — 2.4 GHz only (~2400-2500 MHz). Cheapest and narrowest; useful if a smaller, lower-cost run is ever in scope.
  - **LR22xx series** (e.g. LR2021) — newer multi-band parts: SX1280-class 2.4 GHz, improved sensitivity, BLE-coexistence awareness, expanded LR-FHSS modes. Worth watching as RadioLib support matures.

  **MCU upgrade is conditional, not required.** If a Xiao-compatible 2.4 GHz module turns up (or can be hand-wired onto the edge pins next to the existing B2B Wio shield) the Xiao ESP32S3 Sense stays in service and the form factor barely changes. If the only available SX1280 / LR1121 carriers want full 0.1"-header access, the natural upgrade target is the **ESP32-S3 DevKitC-1 N-R** (e.g. N8R8 — standard ESP32-S3-WROOM-1 dev board with N flash + R PSRAM): ~40 broken-out GPIOs, more flash + PSRAM, and the ability to wire arbitrary off-the-shelf breakouts. `WioSX1262.{h,cpp}` already abstracts pin assignments, SPI bus sharing, and the mutex — switching MCU boards would mean a new `pinout.h` (or per-board `#ifdef` block) and not much else.

  Good news on the firmware side: the protocol decoders and `bridgePacket()` dispatcher in this repo are RF-agnostic — they branch on the LoRa sync word, not the carrier frequency. Once a `WioSX1280` / `WioLR1121` / `WioLR2021` wrapper lands alongside `WioSX1262` (same `LoraConfig` struct, same `available()` / `read()` / `transmit()` surface), the existing bridge pipeline drops straight in with RF parameter changes in `platformio.ini`.

### Reticulum / RNode routing

Prioritized **ahead of** the Sub-GHz↔2.4 GHz cross-band phase above, but it stays
a firmware concern — **no RNS controls will be added to the captive portal.** The
`0x42` sync word is wired into the dispatcher as a third protocol; as of v8.3 the
receive half **and** transparent RNS↔RNS raw repeat are implemented (current state in the
[Routing & behavior](#routing--behavior) per-protocol table):

| Direction | Status |
|---|---|
| `RX:RNS → TX:RNS` (both radios Reticulum) | ✅ **v8.3** — transparent byte-for-byte raw repeat (`BRIDGE_RNS_INPROTO_REPEAT`, on by default). |
| `RX:RNS → TX:MT or MC` | ✅ base64 text tunnel — raw bytes re-transmitted as `[rns <seq> <x>/<y>] <base64>` fragments (CRC-16 seq id, 8-fragment cap, airtime-throttle-paced). |
| `RX:MT or MC → TX:RNS` | ❌ log-and-drop — no RNS encoder yet (`encodeReticulum()` returns false). |
| `RX:RNS → human-readable decode` | ❌ opaque base64 only — RNS frame framing isn't parsed. |
| `MT/MC fragment reassembly → RNS TX` | ❌ `reassembleReticulumFragment()` stub present, no logic. |

**To make it bidirectional** (the work behind the three ❌ rows): an **RNS packet
decoder** (parse header byte / IFAC flag / hops / address hashes / context /
ciphertext → structured line in `MeshDecoderDebug.h`), an **RNS packet encoder**
(build a valid frame in `MeshEncoderDebug.h` — a one-line dispatcher wire-in
once it exists), and **fragment reassembly** (fill in `reassembleReticulumFragment()`:
accumulate `[rns <seq> <x>/<y>]` slots keyed on `<seq>`, base64-decode, ~30 s
timeout, emit when complete). Optional **IFAC** HMAC-SHA256 trailer/salt handling
comes along only if talking to an authentication-enabled network.

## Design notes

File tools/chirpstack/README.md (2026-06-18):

# ChirpStack integration — device-profile templates + payload codec

Everything needed to ingest the bridge's **LoRaWAN ABP uplinks** into a
[ChirpStack](https://www.chirpstack.io/) v4 server: importable **device-profile
templates** (one per region) and the JavaScript **payload codec**.

The bridge's keyed ABP encoder (v8.4) re-emits mesh / Custom traffic as a valid
LoRaWAN **Class-A, ABP** uplink; a separate gateway forwards it to ChirpStack.
These templates describe that device so the codec decodes the payload server-side.

## Layout

```
tools/chirpstack/
└── vendors/grayhatguy/
    ├── vendor.toml                         # vendor identity + device list
    ├── devices/xiao-lora-bridge.toml       # firmware 8.4 -> profiles + codec
    ├── profiles/
    │   ├── xiao-bridge-abp-US915.toml      # one ABP profile per region
    │   ├── xiao-bridge-abp-AU915.toml
    │   ├── xiao-bridge-abp-AS923.toml
    │   └── xiao-bridge-abp-EU868.toml
    └── codecs/
        ├── xiao-bridge.js                  # = tools/chirpstack-codec.js (kept in sync)
        ├── test_decode_xiao-bridge.json
        └── test_encode_xiao-bridge.json
```

> **Region status:** **US915** is hardware-bench-verified. **AU915 / AS923 / EU868**
> are authored from RP002-1.0.3 but **not yet bench-verified**. **OTAA** is not
> included — these profiles are **ABP only** (`supports_otaa = false`); an OTAA
> profile will be added when the OTAA firmware ships in a later release.

## Importing the templates

**Bulk (template repo):** point ChirpStack's importer at this folder:

```
chirpstack -c /etc/chirpstack import-device-profiles -d /path/to/tools/chirpstack
```

Then in the web UI: **Device profiles → Add → "Select device-profile template" →
GrayHatGuy → Xiao ESP32-S3 Dual-SX1262 LoRa Bridge → FW 8.4 → (your region)**.

**Manual (no import, fastest for 1–2 devices):** create a Device Profile by hand
using the values from the matching `profiles/*.toml`
(MAC version **1.0.3**, region e.g. **US915**, **Class A**, **ADR off**), then open
its **Codec** tab, set **"JavaScript functions"**, and paste the whole
[`codecs/xiao-bridge.js`](vendors/grayhatguy/codecs/xiao-bridge.js)
(identical to [`tools/chirpstack-codec.js`](../chirpstack-codec.js)).

## Creating the device (per-device keys go HERE, never in the template)

Create the device under the profile and enter the **ABP session** matching the
bridge's portal (or build-flag) credentials:

| ChirpStack field | Value | Where it comes from |
|---|---|---|
| Device address (DevAddr) | e.g. `01000001` | portal "LoRaWAN ABP devices" slot, or `BRIDGE_LW_ENC_DEVADDR` |
| Network session key (NwkSKey) | 32 hex | portal slot, or `BRIDGE_LW_ENC_NWKSKEY` |
| Application session key (AppSKey) | 32 hex | portal slot, or `BRIDGE_LW_ENC_APPSKEY` |
| Frame-counter validation | **disabled** (or persist) | the bridge reserves FCnt in blocks |

## Per-device codec options (ChirpStack Device → Variables)

The codec reads two optional device **variables** so one pasted codec serves
mixed devices without edits:

| Variable | Set to | Effect |
|---|---|---|
| `source_tag` | `true` | this device has the portal "Prepend source tag" enabled — the codec splits the leading `[proto][srcId]` tag into `data.source` |
| `station_fport` | e.g. `13` | the FPort whose payload is a raw weather-station frame (routed to `decodeStation()`) |

If a variable is absent, the codec's `DEFAULT_SOURCE_TAG` / `DEFAULT_STATION_FPORT`
constants apply.

## Weather-station payload

`decodeStation()` in the codec is a **placeholder** layout — the bridge forwards a
Custom raw-LoRa station's bytes verbatim, so only the station's own datasheet
defines the format. Edit `decodeStation()` to your station's real byte layout
(field order / width / endianness / scaling), then update
`test_decode_xiao-bridge.json` to match.

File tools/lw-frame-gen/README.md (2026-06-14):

# lw-frame-gen — LoRaWAN (sync 0x34) test-frame generator

Standalone firmware that transmits the canonical hand-built LoRaWAN frames from
[`../../BENCH-v8.3.md`](../../BENCH-v8.3.md), so you can bench the v8.3 LoRaWAN
**capture / summary / relay / flood** features **without a real LoRaWAN gateway
or end-device**. The bridge only reads the cleartext MAC header, so an
unencrypted hand-built frame is all it needs.

## Hardware
A Xiao ESP32-S3 + Wio-SX1262 — i.e. **one of your bridges, temporarily reflashed**
(e.g. the COM6 unit). It transmits on **Radio 1** (the B2B-header radio), using
the same pins / SPI / TCXO (1.8 V) / DIO2 RF-switch as the bridge. Reflash the
bridge firmware (`pio run -e xiao_esp32s3 -t upload` from the repo root) when done.

## Flash + run
From **this** folder:

    pio run -t upload
    pio device monitor          # 115200 baud

## RF profile — match the DUT
The generator's RF **must equal the DUT's LoRaWAN radio exactly** (freq / BW / SF
/ CR / sync 0x34) or the DUT will not demodulate — the #1 cause of a silent
`LW-RX`. Defaults are bench profile **P-LW+MT, Radio 1**: `904.6 MHz / BW125 /
SF7 / CR5 / 20 dBm`. Change them in [`platformio.ini`](platformio.ini) (`GEN_*`)
and re-upload. For the **relay/flood** pass, keep the generator on **freqA**
(DUT-A R1); the DUT relays out on freqB to DUT-B.

## Use
In the generator's serial monitor:

| Key | Frame | DUT should log |
|---|---|---|
| `1` | FRAME-U  (UnconfDataUp) | `proto=LW mtype=UnconfDataUp devaddr=0x26011f8a fcnt=1 fport=2` |
| `2` | FRAME-U2 (FCnt 2) | distinct frame — passes dedup |
| `3` | FRAME-D  (ConfDataUp, no FPort) | `fport=-1` |
| `4` | FRAME-J  (JoinRequest) | `mtype=JoinRequest`; summary `DevEUI 0004a30b001a2b3c` |
| `5` | FRAME-C  (11 B) | `parse=fail` |
| `n` | next in cycle | (the **BOOT button** also sends next) |

- **LW-LOOP / dedup:** press `1` twice within 60 s → the DUT logs a capture then
  `drop=lw-dup`.
- **LW-RELAY / LW-FLOOD:** point the generator at DUT-A's R1 freq and watch DUT-A
  relay (`mode=raw`) to DUT-B.
- **Hands-off:** set `GEN_AUTO_MS` > 0 to auto-cycle through all five frames.

The RF profile, the frame name/length, the TX return code, and the expected DUT
decode are printed at boot and on every send, so you can cross-check the DUT log.

Frame bytes are decode-verified against `extractLoRaWANMeta()` in
`src/MeshDecoderDebug.h`.

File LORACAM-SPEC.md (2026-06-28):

# LoRaCam — Spec (DRAFT, for agreement)

**Status:** DRAFT — core decisions **Q1–Q4 LOCKED 2026-06-28** (see §9). Nothing built. No code on shared paths yet.
**Branch:** `lora_cam_xiao` (off `main` @ `24528ad` = v9.0). Remote unchanged (`GrayHatGuy/Xiao-esp32s3-lora-repeater`).
**Date:** 2026-06-28.
**Foundation:** the v9.0 four-radio repeater firmware in this clone. HW feasibility:
`C:\Users\6r4yh\XIAO-Sense-Wio-SX1262-Compatibility-Handoff.md`. Camera reference:
`…\Projects\CameraWebServer_for_esp-arduino_3.0.x-seeed_xiao_esp32s3` (read-only).

> This doc is the working agreement. Sections marked **[DECISION]** need owner sign-off; **[PROPOSED]**
> are my recommendations to confirm or veto. Grounded in a 6-agent read of the repeater + camera codebases.

---

## 1. Goal

A XIAO ESP32-S3 **Sense** (OV2640 camera + mic + microSD on the rear B2B 40-pin) + a **perimeter-pin
Wio-SX1262** edge radio, making a **LoRa-commanded camera**:

- **Downlink C2** over LoRa, **encrypted + sender-whitelisted + replay-protected**: `start-capture`,
  `record N-seconds`, `stop`, `set-quality`, `set-framerate`, `get-status`.
- **Uplink** over LoRa: ACK with the media **filename** / command result, asynchronous **events**, and a
  periodic **beacon/heartbeat** (battery %, SD free, uptime, last-cmd).
- **WiFi web portal** combining **live MJPEG video + config + a LoRa-messaging utility** (the messaging
  utility can inject Custom / Meshtastic / MeshCore / Reticulum frames out the radio).
- **Backwards-compatible** with the shipped repeater: the stock dual-radio and quad host+co-proc builds stay
  **byte-identical**.
- A dormant **plug for future BLE**.

**Scope guard (correction to the brief):** media files travel over **WiFi only**, never LoRa. LoRa carries
C2 + filename/ACK/telemetry only — full-frame imagery over LoRa is infeasible (airtime/duty/dwell). The
"reply with media filename" model already implies this; the portal serves the actual media.

---

## 1A. Roles & topology — master ↔ edge, with standalone

LoRaCam is an **edge/perimeter node of the repeater mesh**, not an island. Three roles, one codebase:

- **Edge (the cam):** speaks the Custom `0x33` C2 channel. Because a repeater **raw-repeats** Custom frames
  (`rawRepeatForDest`), a commander → repeater(s) → cam path works out of the box — the cam is reachable
  *through* the existing bridge mesh, extending C2 range with **no new code**.
- **Master (a repeater):** gains a **C2 commander** capability — mint signed commands, receive the cam's
  ACK/telemetry, surfaced in the repeater's web portal as a "LoRaCam control / messaging" panel. This is the
  "repeaters have CnC access for the cam" requirement. Intended to ship **dormant in the standard repeater
  build** (like the ABP encoder — proven in a flag/variant during dev, folded in at release), activated by
  adding a cam + its key in the portal. *(see Decision A)*
- **Standalone (the cam, always):** the cam always has its own SoftAP portal (config + live video + local
  messaging) and runs autonomously (beacon, local capture) **with or without a master present**. The master
  is additive, never required — "slave of the master, but standalone-capable."

**Master ↔ slave trust:** the cam's `c2auth` whitelist holds its commanders; a master repeater is one entry
(a shared per-sender PSK, provisioned out-of-band on both ends). The cam obeys *any* whitelisted commander,
ACKs **unicast to whoever sent the command**, and **broadcasts beacons** that any in-range whitelisted master
hears (so a mesh of repeaters all see it). Optionally one entry is flagged "primary master" for unsolicited
telemetry. *(see Decision B)*

**Shared codec:** `CamC2.{h,cpp}` implements **both halves** — the *responder* (cam: RX → auth → execute →
ACK + beacon) and the *commander* (repeater: TX signed command → RX ACK/telemetry → display). One module, two
roles, flag-gated. So Phase 1 now delivers both sides; the bench "commander" is simply a repeater build, not a
throwaway tool.

**Two deployment modes, one firmware (chosen at provisioning — runtime, NOT a build fork):**
- **Standalone / self-mastered:** the cam's own SoftAP portal is the master — full local CnC (snap, record,
  stop, quality, framerate, live view) + config, **no repeater required**. Works out of the box; the `c2auth`
  whitelist may stay empty.
- **Paired with a repeater (the primary intent):** "pair" the cam = provision the repeater as a whitelisted
  LoRa commander on the cam (and add the cam on the repeater) with a shared key. The repeater becomes the LoRa
  master; the cam's local portal stays available.

Both surfaces **coexist**: the cam ALWAYS has local portal CnC; pairing only ADDS repeater control over LoRa.
A fresh cam boots standalone-capable with a prominent "Pair with a repeater" action. **Implementation
invariant:** camera actuation is a shared `executeCommand()` — the local portal calls it **directly** (local
trust), the LoRa C2 handler calls it **only after** auth → whitelist → replay. Both command surfaces converge
on one actuation path.

---

## 2. Why this fits the repeater cleanly (≈70% reuse)

The repeater's architecture happens to provide almost every seam this needs:

| Need | Existing mechanism (file:line) |
|---|---|
| Receive + decode a command frame | `ingestAndFanout()` single RX chokepoint; **`PROTO_CUSTOM` branch** `main.cpp:1133` |
| Send a reply / ACK / beacon | build bytes → `g_routeQ[R2].push()` (model: `enqueueAbpUplink` `main.cpp:809`) |
| Encrypt + authenticate | `LoRaWANCrypto.h` — AES-128 ECB/CTR + KAT-verified RFC-4493 **AES-CMAC** (`aesEcb` L43, `aesCmac` L52) |
| Per-sender key table + reboot-safe counter | clone `LoRaWANConfig` (`Device` table + `resolve()` + block-reserve FCnt) into a new NVS namespace |
| Loop/echo guard | `DedupCache` (FNV-1a, 60 s TTL) |
| Radio + SD on one SPI bus | `spiMutex` already brackets every radio SPI op (`WioSX1262.cpp`); SD just joins the same mutex |
| Do-no-harm feature gating | proven 3× (`BRIDGE_LW_ENCODE`, R3/R4 `PROTO_NONE`, ABP) — a build flag + `#if` |

What does **not** exist yet and is genuinely new: (a) an **RX-side authenticate→whitelist→replay-check seam**
(the bridge today only decode-to-log/re-encode — it never gates on *who* sent a packet), and (b) an
**always-on, non-blocking web portal** (today's portal is blocking, AP-only, boot-window-only, and
`ESP.restart()`s on Save).

---

## 3. Hardware (from the feasibility handoff, confirmed against the firmware)

- **Radio = edge/perimeter Wio-SX1262 V1.0** on the R2 pin map: NSS=GPIO5(D4), DIO1=GPIO2(D1), RST=GPIO3(D2),
  BUSY=GPIO4(D3), RF_SW=GPIO6(D5); SPI SCK=GPIO7/D8, MISO=GPIO8/D9, MOSI=GPIO9/D10. TCXO 1.8 V (DIO3),
  DIO2-as-RF-switch (already firmware default). **TX capped at +20 dBm** (3V3 rail can't sustain +22).
- **Camera/mic/SD = Sense daughterboard on the B2B 40-pin** (internal GPIO10–48). **microSD CS = GPIO21**,
  bus shared with the radio (SCK/MISO/MOSI on D8/D9/D10).
- **⚠️ R1 (the firmware's B2B radio, GPIO38–42) collides head-on with the camera/mic.** A LoRaCam build
  **must run R1 = `PROTO_NONE`** and use only the edge R2 radio.
- **⚠️ Mechanical (the real blocker):** the Wio edge board and the Sense daughterboard both want the XIAO's
  underside. **Prototype with flying leads** (handoff §7) — "works on the bench" ≠ "assembles flush."
- **⚠️ Brown-out:** camera-init inrush + TX ramp + SD write on the 700 mA rail can reset the S3. Needs **bulk
  caps on 3V3** + software staggering. **Antenna (u.FL) must be fitted before first boot** — the beacon TXes
  autonomously.
- **⚠️ Camera LED-flash must be disabled** — the example mis-defines it on GPIO21/22, and **GPIO21 is the SD
  chip-select**; left on, LEDC fights the SD-CS.

---

## 4. Design decisions

### 4.1 Backwards-compat mechanism — **[PROPOSED: new build env + flag]**
New `[env:xiao_loracam]` extends `xiao_esp32s3` with `-DBRIDGE_ROLE_CAMERA=1`. All camera/C2/web code lives in
**new files** (`CamC2.{h,cpp}`, `CameraNode.{h,cpp}`, `CameraWeb.{h,cpp}`) compiled only under that flag;
heavier `lib_deps` (esp32-camera, web stack) and any custom partition table exist only in that env. The **only**
touch to shared code is one guarded hook — `#if BRIDGE_ROLE_CAMERA … consumeCameraCommand(...) … #endif` —
in the `PROTO_CUSTOM` branch of `ingestAndFanout()`. New config goes in **new NVS namespaces** (`c2auth` /
`loracam`), never a `BridgeConfig` v5→v6 bump. **Verification gate each commit:** `pio run -e xiao_esp32s3`
(+ `_v1_1` + both coproc envs) must build byte-identical. (Matches the repo's proven do-no-harm pattern.)

### 4.2 C2 transport — **[PROPOSED: binary on PROTO_CUSTOM]**
Commands ride a binary frame on a **`PROTO_CUSTOM` radio (sync word 0x33)** — already a first-class dispatcher
branch with dedup; portal/BridgeConfig already expose Custom + sync word + RF plan. A binary frame is the
natural carrier for a CMAC tag + counter, and an unmodified repeater can **raw-repeat** the frames to extend
C2 range. A Meshtastic/MeshCore *text* command path is rejected as the primary channel because those can only
ever be authenticated by the shared *group* channel key (no per-sender identity) — unacceptable for a physical
actuator. **[DECISION — see Q]** optionally add a text path **later, restricted to non-actuating status reads**.

### 4.3 Crypto / auth — **[PROPOSED: reuse LoRaWANCrypto, encrypt-then-MAC]**
AES-128-CTR **encrypt-then-CMAC** over `[ver‖senderId‖seq‖cmd‖ciphertext]`, all in-tree, zero new deps:
- **Confidentiality:** AES-CTR, nonce = `senderId‖seq`.
- **Auth + whitelist:** **8-byte truncated AES-CMAC** under the sender's key — a valid tag *is* the whitelist
  (only key-holders forge it). 8 bytes (not LoRaWAN's 4) for a physical actuator's offline-forgery margin.
- **Replay:** monotonic `seq` inside the MAC'd region; RX rejects `seq ≤ highest-seen` per sender, persisted
  with the `LoRaWANConfig` block-reserve pattern **inverted** (store highest-seen, reject ≤). `DedupCache` stays
  as a cheap secondary echo guard, *not* the anti-replay primitive.
- **Fail-closed:** whole handler gated by a `g_c2CryptoOk` boot self-test (model: `g_lwCryptoOk`). Constant-time
  tag compare (none exists today — add one). ACK/beacon signed the same way with the device's own TX counter.

**[LOCKED Q2]** key model = **per-sender PSK + allowlist**: each commander has its own 16-byte key in a
bounded table (clone of `LoRaWANConfig::Device` in the `c2auth` NVS namespace), with its own RX replay
high-water. A frame's `senderId` selects the key; unknown sender or bad MIC ⇒ silent drop. Revocable per
commander; the ACK is signed under that commander's key so only it can verify the reply.

### 4.4 Web stack — **[PROPOSED: two servers, reuse the config form]** · WiFi = **[LOCKED Q1: SoftAP]**
WiFi is **SoftAP-only** (field-portable, no infrastructure) — so no STA credential store / connect-retry logic
is needed; the portal is reached at the camera's own AP (reuse the repeater's `LoRa-Bridge-XX`-style SSID).
Keep the repeater's Arduino-`WebServer` config form (`renderForm`/`handleSave` — ~12 KB of proven HTML/JS +
every `BridgeConfig` setter) but **lift it out of the blocking boot-only `CaptivePortal::begin()` into a
persistent non-blocking task on :80**. Add **`esp_http_server`** (the camera example's stack, purpose-built for
MJPEG) for `/capture` + `/stream` on **:8080/:8081**. Two stacks coexist fine in RAM; the combined page links
across the two origins. Consolidating onto ESPAsyncWebServer is deferred (avoids a pinned-dep gamble) unless
two-stack RAM proves tight. The **non-blocking rewrite is unavoidable in every option** — it's the cost of an
always-on portal, not extra.

### 4.5 Concurrency — **[PROPOSED: keep v9.0 model + high-current interlock]**
Keep the v9.0 RX-priority core-pinned `radioTask` (RX is ISR-flagged and re-armed *before* decode → never
starved). Run camera + web tasks on the **other core**. **Modify the stock MJPEG `stream_handler`** (a tight
non-yielding `while(true)`) to `vTaskDelay`/throttle at **lower priority** than radio RX. Add a lightweight
**interlock**: never start a TX during `esp_camera_init`; defer SD writes out of the TX window; throttle the
stream during capture/record and TX. (Software staggering + bulk caps together cover the brown-out case.)

### 4.6 Storage / SD — **[PROPOSED: microSD on shared bus + mutex, MVP may run SD-less]**
Keep **J3 intact**; pass the existing `spiMutex` into the SD subsystem and wrap every `SD.*` call exactly as
`WioSX1262` does (it deliberately releases the bus during on-air time, so SD writes slot into the gaps).
Reconcile SD-lib vs radio SCK/MOSI to one consistent mapping. Disable the GPIO21/22 LED-flash. **[LOCKED Q3:
microSD]** — persistent media on the Sense microSD is the end state (filename/ACK/"SD full" semantics need it).
The Phase-1 C2 MVP runs SD-less (filename = stub) only because no camera is attached yet; SD lands in Phase 2.

### 4.7 BLE future plug — **[PROPOSED: no-op stub, dormant]**
A `-DLORACAM_BLE` flag + an empty `Bluetooth.{h,cpp}` no-op interface, dormant by default (mirrors
`BRIDGE_LW_ENCODE`). **Do not link NimBLE or build a GATT yet** — WiFi+BLE coexistence is the RAM-heavy case
most likely to blow the partition budget, for a non-requirement. Reserve the seam at zero cost.

---

## 5. C2 wire frame (proposed)

```
[ magic/ver : 1 ]      0x?? (version + a LoRaCam magic nibble)
[ type      : 1 ]      CMD | ACK | EVT | BEACON
[ senderId  : N ]      commander identity (selects the auth key + replay counter)
[ seq       : 2 ]      LE monotonic, inside the MAC'd region (anti-replay)
[ payload   : var]     AES-CTR ciphertext of the command/status fields
[ cmac tag  : 8 ]      truncated AES-CMAC over [ver‖type‖senderId‖seq‖ciphertext]
```
Whole frame fits in one small LoRa packet (< ~60 B), far under `LORA_MAX_PACKET=256`. Commands: `START_CAPTURE`,
`RECORD(dur)`, `STOP`, `SET_QUALITY(q)`, `SET_FRAMERATE/SIZE(x)`, `GET_STATUS`. ACK carries `{result, filename}`.
BEACON carries `{battery%, sd_free, uptime, last_cmd_result}`.

---

## 6. Phasing (proposed)

- **Phase 0 — HW proof + skeleton (gates all).** Flying-leads prototype; confirm Wio V1.0; fit antenna; bulk
  caps; stand up `[env:xiao_loracam]` (R1=NONE, R2=CUSTOM 0x33, TX=20). **Gate:** stock envs still byte-identical.
- **Phase 1 — C2 over LoRa MVP, no camera.** `CamC2.{h,cpp}`; the auth→whitelist→replay seam; ACK + beacon.
  Bench-test on the existing 3-board rig (a 2nd XIAO mints commands) **without a camera** — proves the security
  core in isolation.
- **Phase 2 — Camera + SD, command-driven (no web).** `esp_camera_init` (PSRAM, bounded fb); JPEG snap + N-sec
  clip → microSD (shared mutex); wire C2 commands to real capture; ACK carries the real filename; interlock +
  heartbeat with battery/SD-free.
- **Phase 3 — Always-on WiFi portal.** Lift the config form into a persistent task; `esp_http_server`
  /capture+/stream on 8080/8081; throttle/yield the stream; WiFi creds + camera defaults in `loracam` NVS;
  LoRa-messaging utility page (inject via `g_routeQ`).
- **Phase 4 — Hardening + optional.** Brown-out soak; custom partition table if needed (verify OTA); BLE no-op
  stub; optional read-only text status bridge; user-manual; update `CLAUDE.md`.

---

## 7. Top risks
1. **Mechanical stack-up** (Wio edge board vs Sense daughterboard) — prototype flying-leads first.
2. **Brown-out** under camera-init + TX + SD on 700 mA — caps + staggering.
3. **R1/B2B vs camera pin collision** — force R1=`PROTO_NONE`; guard the portal from re-enabling it.
4. **Portal is a rewrite, not a route** — blocking/boot-only → always-on non-blocking; stream loop must yield.
5. **RX auth seam is net-new** — get encrypt-then-MAC ordering right; invert the counter; constant-time compare; fail closed.
6. **Memory/flash/partition squeeze** — camera + WiFi + RadioLib + mbedtls; bound framesize/fb; no NimBLE now.
7. **Arduino-ESP32 core mismatch** — camera example assumes 3.0.x; repeater pinned 2.0.17; port camera code to the repeater's core.

---

## 8. Backwards-compat guarantee
With `BRIDGE_ROLE_CAMERA` undefined: new files/libs/partition don't exist in the image; the single shared-code
hook compiles out; new NVS namespaces are never touched; C2 rides a `PROTO_CUSTOM` slot leaving MT/MC/RNS/LoRaWAN
untouched; R1=NONE is a per-env default invisible to non-camera builds. ⇒ v9.0 master (V1.0/V1.1) + co-proc
(V1.0/V1.1) binaries are **byte-identical**. An unmodified repeater can even raw-repeat the camera's C2/telemetry.

---

## 9. Decisions — LOCKED 2026-06-28
- **Q1 WiFi mode → SoftAP** (field-portable; no STA credential store / connect logic needed).
- **Q2 C2 key model → per-sender PSK + allowlist** (true whitelist, revocable; `c2auth` NVS table).
- **Q3 Media storage → microSD** (shared SPI bus + `spiMutex`; J3 intact).
- **Q4 First milestone → C2-over-LoRa MVP, no camera** (prove the auth core on the bench first).

**[PROPOSED — accepted unless owner vetoes]** the §4 engineering choices: build-env/flag gating (§4.1),
binary C2 on PROTO_CUSTOM 0x33 (§4.2), reuse-LoRaWANCrypto encrypt-then-MAC (§4.3), two-server web with the
config form lifted non-blocking (§4.4), v9.0 + high-current-interlock concurrency (§4.5), BLE no-op stub (§4.7).
Optional **later**: a read-only Meshtastic/MeshCore text status path (non-actuating; channel-key auth only).

**Q5–Q6 LOCKED 2026-06-28 (master ↔ edge, see §1A):**
- **Q5 Commander deployment → dormant in the standard repeater build** (ABP-encoder precedent; configured via
  portal). Proven via a build flag/variant during dev, folded into the standard repeater at release.
- **Q6 Master/slave telemetry → broadcast beacons + unicast ACK to the commander + optional "primary master"
  for unsolicited telemetry** (supports a mesh of repeaters + full standalone).
```

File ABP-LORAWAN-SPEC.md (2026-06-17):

# ABP-LORAWAN-SPEC — LoRaWAN ABP encoder · universal ChirpStack ingestion  *(branch `dev-ABP-lorawan`; MT/MC→RNS deferred)*

> **Status: DRAFT (scoping).** Branch `dev-ABP-lorawan` off `main` (pushed). Supersedes nothing yet — additive on top of shipped v8.3.
> **Release version: targeted for v8.4** (decided 2026-06-15; earlier de-versioned while TBD). This feature was tentatively labelled "v8.3.1" while in scoping; that slot was **reassigned to a v8.3 patch (Radio2 pin-defines fix, separate session)**. The `dev-ABP-lorawan` branch now targets the **v8.4** release (the spec *filename* stays de-versioned). Do NOT tag this branch v8.3.1.
> **Scope steer (owner):** LoRaWAN **ABP is REQUIRED**; **OTAA is OPTIONAL and may be dropped** if hard/complicated (see §10). The encoder is **opt-in and keyed** — v8.3's *keyless* LoRaWAN capture/relay stays intact as a separate mode (see §8).
> Some §§ (exact code-seam file:line, final phase effort) will be tightened from the in-flight scope-research synthesis.

## 0.0 Status & owner decisions — LOCKED 2026-06-15

**Owner decisions (the three §1.1/§3/§9 forks):**
1. **Weather station = raw-LoRa (Fork B)** → build the transcoder. The encoder is the work.
2. **Delivery = B1 (RF re-emit)** → mint the ABP frame and push it to `g_routeQ` for re-transmit on a LoRaWAN channel; an external gateway hears it. **No WiFi/packet-forwarder in P1** (B2 stays a P5 option).
3. **Device model = M1 (per-source)** → one ABP identity per source (DevAddr + keys + its own 32-bit FCnt). Heavier NVS/portal surface than M2, accepted. (Note: spec §3 *recommends* M2; owner overrode for per-node device semantics in ChirpStack.)

**P1 — IMPLEMENTED (code-complete, build-green, crypto-verified) 2026-06-15:**
- `src/LoRaWANCrypto.h` — self-contained **RFC 4493 AES-CMAC** over `mbedtls_aes_*` (CMAC is compiled OUT of the prebuilt lib, finding A4) + `encodeUplink()` (AES-CTR FRMPayload + CMAC MIC, ADR=0, Unconfirmed) + `selfTest()` (RFC4493 + A_1 keystream + frame round-trip KATs).
- `src/main.cpp` — replaced the `no-lw-encoder` drop (the seam) with a keyed transcode → `g_routeQ` RF re-emit (B1), gated by `BRIDGE_LW_ENCODE` + parsed creds so a stock build keeps v8.3's do-no-harm drop; `BRIDGE_LW_ENC_*` flags; build-flag credential resolver (P2 replaces with schema-v5 per-source store + NVS FCnt); boot self-test under `BRIDGE_LW_ENC_SELFTEST`.
- `platformio.ini` — `[env:bench_lw_enc]` (R2=LoRaWAN 903.9, encoder+self-test on, throwaway ABP creds).
- **Verified:** stock build green (24.6%, do-no-harm), `bench_lw_enc` green (24.7%) and *links* (no `mbedtls_cipher_cmac`); crypto cross-checked against an independent `cryptography`-lib CMAC — RFC4493 vectors match + a minted frame is MIC-valid and round-trips.
- **P1 acceptance still open (owner bench):** on-air `raw/MT source → ABP uplink → real gateway → ChirpStack decoded payload`. Provision DevAddr `0x01000001` + the bench keys (MAC 1.0.x, ABP, Class A, ADR off, disable-FCnt-validation or persist). *(The old `0x26011B22` was NwkID 19 → silently dropped by a default LNS; the live bench DevAddr `0x01000001` is NwkID 0, matching ChirpStack's default NetID `0x000000`. `selfTest()` retains `0x26011B22` as an internal crypto KAT only — never on air.)*

## 0. Goals

1. **LoRaWAN ABP *uplink* encoder** (`encodeLoRaWANUplink`) — the bridge mints valid LoRaWAN uplinks a LoRaWAN LNS (ChirpStack) accepts. §2.
2. **Universal source → ABP** — Meshtastic / MeshCore / Reticulum / **Custom (raw-LoRa)** traffic becomes LoRaWAN uplinks ingestible by ChirpStack. §3, scenarios §1.
3. ~~MT/MC → RNS encoder~~ — **DEFERRED this cycle (owner): no RNS coding in the ABP cycle.** Design retained in §6 for later.

**Non-goals / deferred:** **the entire MT/MC → RNS encoder (§6) — RNS coding deferred per owner;** OTAA join (impractical for an uplink-only emitter — §10); the bidirectional dual-LNS *downlink* crosslink (§5 documents the constraints; implementation is a later stretch).

---

## 1. Scenarios

### 1.1 LoRa weather-station → LNS uplink  *(CANONICAL driving scenario)*

**Goal:** a weather station that transmits over LoRa has its readings ingested into a ChirpStack LNS as a normal device.

**Decisive fork — is the station LoRaWAN or raw-LoRa?** (LoRa = the PHY modulation; LoRaWAN = the MAC: sync `0x34`, DevAddr, FCnt, MIC, encryption.)

- **(Fork A) Station already speaks LoRaWAN** (has DevEUI/keys, sends MIC'd uplinks): **out of scope for the encoder** — this is a *gateway* problem. Use a real LoRaWAN gateway + provision the device in ChirpStack with the **manufacturer's** keys. The bridge adds no value (it can't decrypt without the device's keys; a normal gateway won't even demodulate a non-`0x34` device).
- **(Fork B) Station speaks raw LoRa** (proprietary framing, no LoRaWAN MAC): **the encoder's sweet spot.** The bridge *transcodes* raw-LoRa → LoRaWAN-ABP:
  1. A bridge radio runs **Custom** protocol matched to the station's RF (freq / BW / SF / CR / sync) and receives the raw packet.
  2. The bridge wraps the payload into a LoRaWAN **ABP uplink** under a bridge-held identity that *represents the station* — `DevAddr` + `NwkSKey` + `AppSKey` (also provisioned in ChirpStack), with valid MIC, AES-CTR-encrypted FRMPayload, monotonic FCnt, on an FPort (§2, §3).
  3. **Delivery to ChirpStack — two architectures:**
     - **(B1) RF re-emit** — transmit the ABP frame over the air on a LoRaWAN channel; an existing LoRaWAN **gateway** hears it → ChirpStack. Fits the current dual-radio design; needs a gateway in range; costs extra airtime/duty-cycle (re-transmission).
     - **(B2) Bridge-as-gateway (WiFi)** — the ESP32-S3 forwards the frame straight to ChirpStack via the **Semtech UDP packet-forwarder / ChirpStack Gateway Bridge (MQTT)**; **no second gateway**. Cleaner end-to-end; larger build (a packet-forwarder/MQTT path + gateway provisioning in ChirpStack).
  4. ChirpStack validates the MIC + decrypts with the provisioned keys → the station appears as a normal device uplink, decoded by a ChirpStack payload codec.

**Outcome:** the bridge "LoRaWAN-izes" a non-LoRaWAN sensor. This is the same machinery as §3, with a Custom-protocol source.

**Open design Qs (owner) — RESOLVED 2026-06-15 (§0.0):** (i) raw-LoRa (**Fork B**); (ii) delivery **B1 (RF re-emit + gateway)**; (iii) device model **M1 (per-source)**.

### 1.2 Mesh → LNS  (MT / MC / RNS / Custom → ABP)
General case of §1.1: any decoded bridge source is mapped to a LoRaWAN ABP uplink (one virtual device per source identity, or one multiplexed device with a source tag — §3). Delivery B1 or B2 as above.

### 1.3 Dual-repeating-LNS crosslink relay  *(radio1 = ABP1/LNS1 ↑, radio2 = ABP2/LNS2 ↓)*
The bridge carries payloads between **two** LoRaWAN networks by being a **separate ABP endpoint on each** (radio1 holds ABP1 creds for LNS1; radio2 holds ABP2 creds for LNS2). The "crosslink" is the bridge's **app-layer routing** between the two endpoints (re-encode/re-MIC per side). Constraints in §5. **Implementation = later stretch** (documented here so the ABP cycle is built without foreclosing it).

---

## 2. LoRaWAN ABP uplink encoder (`encodeLoRaWANUplink`)

Mints a class-A **uplink** PHYPayload (LoRaWAN 1.0.x):

```
PHYPayload = MHDR(1) | MACPayload | MIC(4)
MACPayload = FHDR | FPort(1) | FRMPayload
FHDR       = DevAddr(4, LE) | FCtrl(1) | FCnt(2, LE = low 16 of the 32-bit counter) | FOpts(0)
MHDR       = 0x40  (Unconfirmed Data Up, Major=0)   ; 0x80 = Confirmed (avoid — needs ACK)
FCtrl(up)  = ADR(0) ADRACKReq(0) ACK(0) ClassB(0) FOptsLen(0)  => 0x00   (see §4: ADR=0)
```

- **FRMPayload encryption** (LoRaWAN counter mode): for each 16-byte block `i`, `A_i = 0x01 | 0x00000000 | Dir(0) | DevAddr(4 LE) | FCnt(4 LE) | 0x00 | i`; keystream = `AES-128-ECB(K, A_i)`; ciphertext = plaintext XOR keystream. **K = AppSKey** for `FPort>0` (application data), **NwkSKey** for `FPort=0` (MAC-only).
- **MIC** = first 4 bytes of `AES-128-CMAC(NwkSKey, B0 || MHDR|FHDR|FPort|FRMPayload)`, where `B0 = 0x49 | 0x00000000 | Dir(0) | DevAddr(4 LE) | FCntUp(4 LE) | 0x00 | len(msg)`.
- **Keys held by the bridge** per virtual device: `NwkSKey` (MIC) + `AppSKey` (payload). **Emitting LoRaWAN is fundamentally keyed** — not keyless (§7).
- **FCnt** must be **monotonic** and **persisted** across reboots (§4, §8).

**Crypto:** MeshCore already uses mbedTLS AES-128-ECB (so ECB + the CTR-mode keystream is in hand). **AES-CMAC for the MIC:** verify `MBEDTLS_CMAC_C` / `mbedtls_cipher_cmac` is enabled in the ESP-IDF build; if not, add a small CMAC-over-AES-ECB helper (~30 lines). *(Confirmed by scope-research A4: it is OFF; helper added in `src/LoRaWANCrypto.h`.)*

**Hook point:** the dispatcher's `enqueueTextForDest` currently log-and-drops when the dest protocol is LoRaWAN (`no-lw-encoder`, `main.cpp` ~557/565). The encoder replaces that drop, building a PHYPayload and pushing it to the dest radio's RouteQueue (RF re-emit, B1) or to the WiFi forwarder (B2). Mirrors the `encodeMeshtasticText` / `encodeMeshCoreGrpTxt` pattern in `MeshEncoderDebug.h`.

---

## 3. Universal encoder → ChirpStack

Map every source (MT / MC / RNS / Custom) to an ABP uplink. Two device models:

- **(M1) Per-source virtual ABP device** — one `DevAddr`+keys per mesh sender / per source. ChirpStack shows each as a distinct device. Cleanest semantics; heaviest provisioning (one ABP device per source in ChirpStack) and key/FCnt state per device in NVS.
- **(M2) Single multiplexed bridge ABP device** — one `DevAddr`+keys; the **source identity is carried in the FRMPayload** (a header byte / tag) and split out by a ChirpStack payload codec. Minimal provisioning; the LNS sees "one device" carrying many sources.

**Recommendation:** support **M2 first** (one device, low friction — ideal for the weather-station scenario where it *is* one source anyway), with **M1 as an option** for deployments that want per-node devices. **(Owner chose M1 — see §0.0.)**

**FPort allocation** (so a ChirpStack codec can demux the source protocol): e.g. `FPort 10 = MT`, `11 = MC`, `12 = RNS`, `13 = Custom/weather` *(final numbers TBD)*. **FRMPayload schema:** `[srcTag][srcId?][len][payload…]` — documented so a JS/codec on ChirpStack decodes back to the original message. (For the weather station: payload = the raw sensor bytes, decoded by a station-specific codec.)

---

## 4. MIC / NONCE / ADR / timing — how each is satisfied

- **MIC** — computed with `NwkSKey` (§2). Wrong MIC ⇒ ChirpStack **silently drops**. Non-negotiable: the bridge must hold `NwkSKey`.
- **NONCE** — **ABP has no nonce.** Anti-replay/freshness is the **monotonic FCnt**. (OTAA's `DevNonce`/`JoinNonce` apply only to the join handshake we are *not* doing — §10.) Therefore **FCntUp must never go backwards**: persist it in NVS (write-throttled to spare flash), or enable ChirpStack **"disable frame-counter validation" / relaxed counters** (weaker; accepts resets). Default plan: **NVS-persisted FCnt** + relax-counters as the fallback knob.
- **ADR** — set **ADR = 0** and use **Unconfirmed** uplinks. The bridge is effectively uplink-only; it can't service ADR downlinks/MAC commands or ACK confirmed downlinks, so ADR=1 would risk `ADRACKReq` stalls and unfulfillable downlink expectations.
- **Timing / duty-cycle** — respect the regional limit (EU868 ~1%/sub-band; US915 400 ms dwell) on the LoRaWAN side. Reuse the existing v8.2 **airtime throttle** but bound it to LoRaWAN duty/dwell, not just the bridge's self-TX cap. Class-A RX1/RX2 windows are **ignored** for an uplink-only emitter (no downlinks consumed) — acceptable for ingestion; revisit only for §5.

---

## 5. Dual-repeating-LNS constraints  *(uplink LNS1 / downlink LNS2)*

**Verdict (from cross-LNS research):** "uplink to LNS1, downlink from LNS2" is **not** a single-identity LoRaWAN capability — a device session (keys, FCntUp/FCntDown, downlink timing) is owned by exactly one Network Server. The only spec path for one session across networks is operator **Roaming (LoRaWAN Backend Interfaces / TS002)**, which is **LNS↔LNS, device-transparent** — not a device-side trick. **Achieve it instead as TWO independent ABP sessions** the bridge owns: `radio1=ABP1` in LNS1, `radio2=ABP2` in LNS2; the bridge routes payloads between them at the **application layer** (re-encode/re-MIC per side).

**Hard constraints:**
1. **Two independent sessions** — each radio: own `DevAddr` + `NwkSKey` + `AppSKey`, own `FCntUp`/`FCntDown`, provisioned in *its* LNS. No key sharing across LNS; no MIC forging.
2. **Async downlink from LNS2 ⇒ radio2 must be Class C** — continuous RX2 on **LNS2's RX2 freq + DR**, so LNS2 can push downlinks (unicast or **multicast** — shared addr/keys/FCnt) anytime, untied to an uplink. *Class-A alternative:* radio2 **polls** by sending periodic uplinks to LNS2 and reading queued downlinks in RX1/RX2 — simpler, but downlink latency is bounded by the poll interval and duty-cycle.
3. **A reachable LNS2 gateway** + the downlink **enqueued** (ChirpStack device or multicast queue via API/UI). ChirpStack v4 supports Class C (reuses the device downlink queue) and multicast, but has **no built-in roaming and no TS011-relay** — the crosslink is *your* app-layer routing.
4. **It works only for identities the bridge OWNS** (ABP1/ABP2 it provisions). It **cannot transparently relay a third-party device** across networks — LoRaWAN security blocks forging the MIC or reading the encrypted payload without that LNS's keys.
5. **TS011 "Relay" does NOT apply** — that spec is a same-network, battery-powered coverage extender (Wake-on-Radio), not a cross-LNS bridge.
6. **Per-radio regulatory budgets** — duty-cycle/dwell/EIRP on each RF domain independently; RX2 DR/freq matched per LNS; continuous RX (Class C) power is fine on USB.

**Status:** documented; **implementation deferred (later).** The ABP cycle builds the one-way ABP uplink encoder without foreclosing this (keep keys/FCnt state per-radio-capable in the config schema, §8).

---

## 6. MT/MC → RNS encoder (carry-over) — ⏸️ DEFERRED (not in the ABP cycle)

> **RNS coding is deferred this cycle (owner decision).** Retained below as the design of record for whenever it's picked up (later); there is **no implementation in the ABP cycle**.

- **(Phase 1 — tractable) Round-trip passthrough.** Reassemble RNS bytes previously tunnelled as `[rns <seq> <x>/<y>] <base64>` (fill in `reassembleReticulumFragment()`), then **raw re-emit** the reconstructed frame on an RNS radio. **No addressing/crypto** needed — the bytes are already a valid RNS frame. Closes the `RNS → MT/MC → RNS` round trip across two bridges.
- **(Phase 2 — optional, harder) Arbitrary MT/MC → new RNS packet.** Requires a **configured destination Identity/hash + encryption** to that destination (Reticulum addresses are destination-hash + Identity-keyed). Needs a new addressing-model config; assess feasibility before committing. Today `encodeReticulum()` (`MeshEncoderDebug.h` ~325) returns `false` and the dest-RNS path is a `no-rns-encoder` drop (`main.cpp` ~557).

---

## 7. Keyed vs keyless (architectural note)

v8.3 LoRaWAN is **keyless** (cleartext-header capture/relay only). The ABP encoder is **keyed** (needs `NwkSKey`+`AppSKey` to mint valid uplinks). **Keep both:** keyless capture/relay remains the default for a radio set to "LoRaWAN" with no keys; the encoder activates only when a radio/dest is configured with ABP credentials. The two modes are mutually exclusive per radio and selected by presence of keys.

---

## 8. Config / NVS schema needs

- Per virtual device (M1) or per bridge device (M2): `DevAddr` (4 B), `NwkSKey` (16 B), `AppSKey` (16 B), **persisted `FCntUp`** (32-bit, write-throttled), FPort map, source→device mapping. For §5: a second set keyed per-radio + `FCntDown`.
- `BridgeConfig` schema **version bump** (current v4) with forward migration; new captive-portal section ("LoRaWAN device / ABP credentials"); a build-flag fallback for source builds.
- Delivery selector: **B1 RF re-emit** vs **B2 WiFi forwarder** (the latter adds gateway/MQTT config — host, credentials, gateway EUI).

---

## 9. Prioritized phases  *(effort S/M/L — refine from scope synthesis)*

1. **(M) AES-CMAC helper + `encodeLoRaWANUplink`** — ✅ **IMPLEMENTED 2026-06-15** (§0.0). RFC-4493 AES-CMAC + build/encrypt/MIC of a valid ABP uplink at the `no-lw-encoder` seam → push to `g_routeQ` (B1). Crypto unit-verified vs RFC4493 + an independent CMAC; both builds green. **Remaining = the on-air bench** (Custom/MT source → ABP uplink → real gateway → ChirpStack shows the decoded payload).
2. ✅ **IMPLEMENTED (P2) 2026-06-15** — Config/NVS + portal. Per-source ABP creds + persisted FCnt + portal section, in a **dedicated `LoRaWANConfig` module + its own NVS namespace (`lwabp`)** — NOT a BridgeConfig schema v4→v5 bump (cleaner / isolated / no migration). Reboot-safe FCnt via block reservation. Build-flag creds stay as a fallback.
3. ✅ **IMPLEMENTED (P3) 2026-06-15** — Universal mapping. M1 per-source devices (owner's choice) + an **optional** per-device source tag for a multiplexed device; **Custom raw-LoRa → ABP** (the weather-station path: raw RX bytes → FRMPayload); `tools/chirpstack-codec.js` sample codec. On-air weather-station run = the acceptance test (`BENCH-v8.4.md`).
   - ✅ **Regional timing (P4) 2026-06-15** — US915 per-TX dwell cap (400 ms ToA) in the TX scheduler; EU868 duty via `BRIDGE_TX_DUTY_PERCENT`.
4. **(L, optional) B2 bridge-as-gateway** — Semtech UDP / ChirpStack Gateway Bridge MQTT forwarder over WiFi (removes the separate-gateway requirement).
5. ~~MT/MC→RNS passthrough~~ — **DEFERRED → later** (RNS coding deferred this cycle, owner). §6 holds the design.
6. **(L, stretch → later) Dual-LNS crosslink** (§5) — second ABP identity per radio + Class-C (or Class-A poll) downlink path + cross-routing.
7. **(optional) M1 per-source devices; arbitrary MT/MC→RNS (§6 Phase 2); OTAA** — only if specifically wanted. *(Owner chose M1 for the device model — §0.0.)*

---

## 10. Risks & open questions

- **OTAA dropped (owner-approved):** OTAA-*encode* needs the JoinAccept **downlink** in a Class-A RX window + `DevNonce` uniqueness/state — impractical for an uplink-only emitter; OTAA-*decode* needs join-derived keys. **ABP only.** (Revisit only if a join-capable bidirectional mode is ever built.)
- **FCnt persistence vs flash wear** — write-throttle / store coarsely; relax-counters in ChirpStack as fallback.
- **Duty-cycle** — B1 (RF re-emit) doubles airtime; ensure the throttle enforces LoRaWAN regional limits.
- **CMAC availability** — confirmed OFF in the prebuilt lib; bundled the RFC-4493 helper (`src/LoRaWANCrypto.h`).
- **Per-source provisioning blow-up** (M1) — many devices to register; M2 avoids it. **(Owner accepted M1.)**
- **Weather-station fork** — confirmed raw-LoRa (Fork B); if LoRaWAN (Fork A), it's a gateway task, not this.
- **Delivery model** — B1 vs B2 is the biggest scope lever; **owner chose B1.**

---

## 11. References
- Repo: [`CLAUDE.md`](CLAUDE.md), [`V8.3-SPEC.md`](V8.3-SPEC.md), [`BENCH-v8.3.md`](BENCH-v8.3.md); seams `src/main.cpp` (`no-rns-encoder`/`no-lw-encoder` ~557/565), `src/MeshEncoderDebug.h` (`encodeReticulum` ~325, encode patterns), `src/MeshDecoderDebug.h` (`extractLoRaWANMeta` ~978-1012), `src/BridgeConfig.*`.
- External (cross-LNS research): LoRaWAN 1.0.4 MAC + Backend-Interfaces/Roaming (TS002), TS011 Relay, ChirpStack v4 docs (device classes / multicast / configuration / API). Cited in the ABP scope research + memory.

---

## 12. Scope-research findings (recovered 2026-06-15) — code-grounded

The ABP scope research (workflow `wf_815177cd-9aa`; LoRaWAN 1.0.4 spec + ChirpStack v4 docs + repo) is complete. Refinements to the sections above:

**Crypto — the one real gotcha (A4):**
- mbedTLS **AES-128 ECB + CTR are present & proven in-tree** (`MeshEncoderDebug.h` — MeshCore ECB ~73-81, Meshtastic CTR ~192-202/309-319); HMAC-SHA256, SHA-256, base64 too.
- ⚠️ **AES-CMAC is NOT linkable** — the prebuilt esp32s3 mbedTLS (arduino-esp32 2.0.17) was built with `CONFIG_MBEDTLS_CMAC_C` **OFF** (`tools/sdk/esp32s3/sdkconfig:1644`); `mbedtls_cipher_cmac` link-errors. **Added a self-contained RFC-4493 AES-CMAC helper** (`src/LoRaWANCrypto.h`) on `mbedtls_aes_setkey_enc` + `mbedtls_aes_crypt_ecb` (both in the prebuilt lib). Only new crypto primitive required.

**Exact code seams (A2/A4):**
- **Encoder hook:** `main.cpp:565-569` — the `MT/MC → LoRaWAN` `drop=no-lw-encoder` site inside `enqueueTextForDest()` (`main.cpp:551-669`), with `dstChan`/`srcId`/`srcTag`/`body` in hand. Replace the drop → `encodeLoRaWANUplink()` → `outPkt[256]` → `g_routeQ[destIdx].push()` → `evt=QUEUE`; add `DedupCache::record(...)` for loop-safety (mirror MT ~610 / MC ~636 / dedup ~654-656). **(Done in P1.)**
- **Encoder template:** `encodeMeshtasticText` (`MeshEncoderDebug.h:121-206`). Deferral pattern: `encodeReticulum` stub (`:340`).
- **Decoder (inverse ref):** `extractLoRaWANMeta` (`MeshDecoderDebug.h:978-1012`) — cleartext header only; its `FCnt` is `uint16` (low 16) — the encoder needs the **full 32-bit** FCnt in B0/A_i.

**Config / NVS (A4):**
- `SCHEMA_VERSION=4` (`BridgeConfig.cpp:89`); `RadioChannel.key[32]` (`RadioChannel.h:19`) holds ONE AES key → **too small for NwkSKey+AppSKey** ⇒ **schema v4→v5** with a per-radio LoRaWAN credential struct (DevAddr/NwkSKey/AppSKey/FPort) + migration arm + a new `LoRaWANConfig::resolve()` (mirror `MeshCoreConfig::resolve` `:36-60`). **(P2.)**
- **FCnt:** a **separate small NVS key** (`prefs.putUInt`), updated per-uplink — NOT the main blob `save()` (`BridgeConfig.cpp:337-348`) → avoids flash wear. **(P2.)**
- **Portal:** `CaptivePortal.cpp:519-523` currently forces sync `0x34` and **clears** the key (keyless); add DevAddr/NwkSKey/AppSKey/FPort inputs gated to the `lw` class + save-handler validation. **(P2.)**

**ChirpStack v4 (A3):**
- Provision: device-profile (region; **pin MAC 1.0.x**; ABP; Class A) → device with **DevAddr (private prefix, NetID 0x000000/0x000001)** + NwkSKey + AppSKey + FPort/codec.
- FCnt: persist 32-bit in bridge **or** tick **"Disable frame-counter validation"** (drops replay protection; a v4 quirk where `skipFCntCheck` didn't persist was reported — verify it sticks).
- **Wrong MIC ⇒ silent drop** (no app event). **ADR off + Unconfirmed** (uplink-only).
- **Timing:** EU868 ~1%/sub-band (single rolling `BRIDGE_TX_DUTY_PERCENT` only approximates, not per-sub-band ETSI); **US915 400 ms per-packet dwell — the rolling throttle does NOT enforce a per-TX ToA cap; add one** (`estimateAirtimeMs` at `main.cpp:971`). **(P4.)**

**RNS (A1 — deferred §6):** keyless origination confirmed impossible (single-dest addr = SHA-256 over name + **destination public key**; payload = per-packet ephemeral-X25519 + Fernet AES-CBC/HMAC). Only keyless path = passthrough egress (reassemble `[rns ..]` fragments → `rawRepeatForDest`); stubs `MeshDecoderDebug.h:930` / `MeshEncoderDebug.h:340`; hook the marker on the MT/MC RX path (~`main.cpp:957-964`) **before** text decode. Deferred per owner.

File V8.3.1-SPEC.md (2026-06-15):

# V8.3.1-SPEC — LoRaWAN ABP encoder · universal ChirpStack ingestion  *(MT/MC→RNS deferred)*

> **Status: DRAFT (scoping).** Branch `v8.3.1-dev` off `main` @ `a06a398`. Supersedes nothing yet — additive on top of shipped v8.3.
> **Scope steer (owner):** LoRaWAN **ABP is REQUIRED**; **OTAA is OPTIONAL and may be dropped** if hard/complicated (see §10). The encoder is **opt-in and keyed** — v8.3's *keyless* LoRaWAN capture/relay stays intact as a separate mode (see §8).
> Some §§ (exact code-seam file:line, final phase effort) will be tightened from the in-flight scope-research synthesis.

## 0.0 Status & owner decisions — LOCKED 2026-06-15

**Owner decisions (the three §1.1/§3/§9 forks):**
1. **Weather station = raw-LoRa (Fork B)** → build the transcoder. The encoder is the work.
2. **Delivery = B1 (RF re-emit)** → mint the ABP frame and push it to `g_routeQ` for re-transmit on a LoRaWAN channel; an external gateway hears it. **No WiFi/packet-forwarder in P1** (B2 stays a P5 option).
3. **Device model = M1 (per-source)** → one ABP identity per source (DevAddr + keys + its own 32-bit FCnt). Heavier NVS/portal surface than M2, accepted. (Note: spec §3 *recommends* M2; owner overrode for per-node device semantics in ChirpStack.)

**P1 — IMPLEMENTED (code-complete, build-green, crypto-verified) 2026-06-15:**
- `src/LoRaWANCrypto.h` — self-contained **RFC 4493 AES-CMAC** over `mbedtls_aes_*` (CMAC is compiled OUT of the prebuilt lib, finding A4) + `encodeUplink()` (AES-CTR FRMPayload + CMAC MIC, ADR=0, Unconfirmed) + `selfTest()` (RFC4493 + A_1 keystream + frame round-trip KATs).
- `src/main.cpp` — replaced the `no-lw-encoder` drop (the seam) with a keyed transcode → `g_routeQ` RF re-emit (B1), gated by `BRIDGE_LW_ENCODE` + parsed creds so a stock build keeps v8.3's do-no-harm drop; `BRIDGE_LW_ENC_*` flags; build-flag credential resolver (P2 replaces with schema-v5 per-source store + NVS FCnt); boot self-test under `BRIDGE_LW_ENC_SELFTEST`.
- `platformio.ini` — `[env:bench_lw_enc]` (R2=LoRaWAN 903.9, encoder+self-test on, throwaway ABP creds).
- **Verified:** stock build green (24.6%, do-no-harm), `bench_lw_enc` green (24.7%) and *links* (no `mbedtls_cipher_cmac`); crypto cross-checked against an independent `cryptography`-lib CMAC — RFC4493 vectors match + a minted frame is MIC-valid and round-trips.
- **P1 acceptance still open (owner bench):** on-air `raw/MT source → ABP uplink → real gateway → ChirpStack decoded payload`. Provision DevAddr `0x26011B22` + the bench keys (MAC 1.0.x, ABP, Class A, ADR off, disable-FCnt-validation or persist).

## 0. Goals

1. **LoRaWAN ABP *uplink* encoder** (`encodeLoRaWANUplink`) — the bridge mints valid LoRaWAN uplinks a LoRaWAN LNS (ChirpStack) accepts. §2.
2. **Universal source → ABP** — Meshtastic / MeshCore / Reticulum / **Custom (raw-LoRa)** traffic becomes LoRaWAN uplinks ingestible by ChirpStack. §3, scenarios §1.
3. ~~MT/MC → RNS encoder~~ — **DEFERRED this cycle (owner): no RNS coding in v8.3.1.** Design retained in §6 for 8.3.2+.

**Non-goals / deferred:** **the entire MT/MC → RNS encoder (§6) — RNS coding deferred per owner;** OTAA join (impractical for an uplink-only emitter — §10); the bidirectional dual-LNS *downlink* crosslink (§5 documents the constraints; implementation is a v8.3.2/v8.4 stretch).

---

## 1. Scenarios

### 1.1 LoRa weather-station → LNS uplink  *(CANONICAL driving scenario)*

**Goal:** a weather station that transmits over LoRa has its readings ingested into a ChirpStack LNS as a normal device.

**Decisive fork — is the station LoRaWAN or raw-LoRa?** (LoRa = the PHY modulation; LoRaWAN = the MAC: sync `0x34`, DevAddr, FCnt, MIC, encryption.)

- **(Fork A) Station already speaks LoRaWAN** (has DevEUI/keys, sends MIC'd uplinks): **out of scope for the encoder** — this is a *gateway* problem. Use a real LoRaWAN gateway + provision the device in ChirpStack with the **manufacturer's** keys. The bridge adds no value (it can't decrypt without the device's keys; a normal gateway won't even demodulate a non-`0x34` device).
- **(Fork B) Station speaks raw LoRa** (proprietary framing, no LoRaWAN MAC): **the encoder's sweet spot.** The bridge *transcodes* raw-LoRa → LoRaWAN-ABP:
  1. A bridge radio runs **Custom** protocol matched to the station's RF (freq / BW / SF / CR / sync) and receives the raw packet.
  2. The bridge wraps the payload into a LoRaWAN **ABP uplink** under a bridge-held identity that *represents the station* — `DevAddr` + `NwkSKey` + `AppSKey` (also provisioned in ChirpStack), with valid MIC, AES-CTR-encrypted FRMPayload, monotonic FCnt, on an FPort (§2, §3).
  3. **Delivery to ChirpStack — two architectures:**
     - **(B1) RF re-emit** — transmit the ABP frame over the air on a LoRaWAN channel; an existing LoRaWAN **gateway** hears it → ChirpStack. Fits the current dual-radio design; needs a gateway in range; costs extra airtime/duty-cycle (re-transmission).
     - **(B2) Bridge-as-gateway (WiFi)** — the ESP32-S3 forwards the frame straight to ChirpStack via the **Semtech UDP packet-forwarder / ChirpStack Gateway Bridge (MQTT)**; **no second gateway**. Cleaner end-to-end; larger build (a packet-forwarder/MQTT path + gateway provisioning in ChirpStack).
  4. ChirpStack validates the MIC + decrypts with the provisioned keys → the station appears as a normal device uplink, decoded by a ChirpStack payload codec.

**Outcome:** the bridge "LoRaWAN-izes" a non-LoRaWAN sensor. This is the same machinery as §3, with a Custom-protocol source.

**Open design Qs (owner) — RESOLVED 2026-06-15 (§0.0):** (i) raw-LoRa (**Fork B**); (ii) delivery **B1 (RF re-emit + gateway)**; (iii) device model **M1 (per-source)**.

### 1.2 Mesh → LNS  (MT / MC / RNS / Custom → ABP)
General case of §1.1: any decoded bridge source is mapped to a LoRaWAN ABP uplink (one virtual device per source identity, or one multiplexed device with a source tag — §3). Delivery B1 or B2 as above.

### 1.3 Dual-repeating-LNS crosslink relay  *(radio1 = ABP1/LNS1 ↑, radio2 = ABP2/LNS2 ↓)*
The bridge carries payloads between **two** LoRaWAN networks by being a **separate ABP endpoint on each** (radio1 holds ABP1 creds for LNS1; radio2 holds ABP2 creds for LNS2). The "crosslink" is the bridge's **app-layer routing** between the two endpoints (re-encode/re-MIC per side). Constraints in §5. **Implementation = v8.3.2/v8.4 stretch** (documented here so v8.3.1 is built without foreclosing it).

---

## 2. LoRaWAN ABP uplink encoder (`encodeLoRaWANUplink`)

Mints a class-A **uplink** PHYPayload (LoRaWAN 1.0.x):

```
PHYPayload = MHDR(1) | MACPayload | MIC(4)
MACPayload = FHDR | FPort(1) | FRMPayload
FHDR       = DevAddr(4, LE) | FCtrl(1) | FCnt(2, LE = low 16 of the 32-bit counter) | FOpts(0)
MHDR       = 0x40  (Unconfirmed Data Up, Major=0)   ; 0x80 = Confirmed (avoid — needs ACK)
FCtrl(up)  = ADR(0) ADRACKReq(0) ACK(0) ClassB(0) FOptsLen(0)  => 0x00   (see §4: ADR=0)
```

- **FRMPayload encryption** (LoRaWAN counter mode): for each 16-byte block `i`, `A_i = 0x01 | 0x00000000 | Dir(0) | DevAddr(4 LE) | FCnt(4 LE) | 0x00 | i`; keystream = `AES-128-ECB(K, A_i)`; ciphertext = plaintext XOR keystream. **K = AppSKey** for `FPort>0` (application data), **NwkSKey** for `FPort=0` (MAC-only).
- **MIC** = first 4 bytes of `AES-128-CMAC(NwkSKey, B0 || MHDR|FHDR|FPort|FRMPayload)`, where `B0 = 0x49 | 0x00000000 | Dir(0) | DevAddr(4 LE) | FCntUp(4 LE) | 0x00 | len(msg)`.
- **Keys held by the bridge** per virtual device: `NwkSKey` (MIC) + `AppSKey` (payload). **Emitting LoRaWAN is fundamentally keyed** — not keyless (§7).
- **FCnt** must be **monotonic** and **persisted** across reboots (§4, §8).

**Crypto:** MeshCore already uses mbedTLS AES-128-ECB (so ECB + the CTR-mode keystream is in hand). **AES-CMAC for the MIC:** verify `MBEDTLS_CMAC_C` / `mbedtls_cipher_cmac` is enabled in the ESP-IDF build; if not, add a small CMAC-over-AES-ECB helper (~30 lines). *(Confirm exact availability from the scope-research A4 finding.)*

**Hook point:** the dispatcher's `enqueueTextForDest` currently log-and-drops when the dest protocol is LoRaWAN (`no-lw-encoder`, `main.cpp` ~557/565). The encoder replaces that drop, building a PHYPayload and pushing it to the dest radio's RouteQueue (RF re-emit, B1) or to the WiFi forwarder (B2). Mirrors the `encodeMeshtasticText` / `encodeMeshCoreGrpTxt` pattern in `MeshEncoderDebug.h`.

---

## 3. Universal encoder → ChirpStack

Map every source (MT / MC / RNS / Custom) to an ABP uplink. Two device models:

- **(M1) Per-source virtual ABP device** — one `DevAddr`+keys per mesh sender / per source. ChirpStack shows each as a distinct device. Cleanest semantics; heaviest provisioning (one ABP device per source in ChirpStack) and key/FCnt state per device in NVS.
- **(M2) Single multiplexed bridge ABP device** — one `DevAddr`+keys; the **source identity is carried in the FRMPayload** (a header byte / tag) and split out by a ChirpStack payload codec. Minimal provisioning; the LNS sees "one device" carrying many sources.

**Recommendation:** support **M2 first** (one device, low friction — ideal for the weather-station scenario where it *is* one source anyway), with **M1 as an option** for deployments that want per-node devices.

**FPort allocation** (so a ChirpStack codec can demux the source protocol): e.g. `FPort 10 = MT`, `11 = MC`, `12 = RNS`, `13 = Custom/weather` *(final numbers TBD)*. **FRMPayload schema:** `[srcTag][srcId?][len][payload…]` — documented so a JS/codec on ChirpStack decodes back to the original message. (For the weather station: payload = the raw sensor bytes, decoded by a station-specific codec.)

---

## 4. MIC / NONCE / ADR / timing — how each is satisfied

- **MIC** — computed with `NwkSKey` (§2). Wrong MIC ⇒ ChirpStack **silently drops**. Non-negotiable: the bridge must hold `NwkSKey`.
- **NONCE** — **ABP has no nonce.** Anti-replay/freshness is the **monotonic FCnt**. (OTAA's `DevNonce`/`JoinNonce` apply only to the join handshake we are *not* doing — §10.) Therefore **FCntUp must never go backwards**: persist it in NVS (write-throttled to spare flash), or enable ChirpStack **"disable frame-counter validation" / relaxed counters** (weaker; accepts resets). Default plan: **NVS-persisted FCnt** + relax-counters as the fallback knob.
- **ADR** — set **ADR = 0** and use **Unconfirmed** uplinks. The bridge is effectively uplink-only; it can't service ADR downlinks/MAC commands or ACK confirmed downlinks, so ADR=1 would risk `ADRACKReq` stalls and unfulfillable downlink expectations.
- **Timing / duty-cycle** — respect the regional limit (EU868 ~1%/sub-band; US915 400 ms dwell) on the LoRaWAN side. Reuse the existing v8.2 **airtime throttle** but bound it to LoRaWAN duty/dwell, not just the bridge's self-TX cap. Class-A RX1/RX2 windows are **ignored** for an uplink-only emitter (no downlinks consumed) — acceptable for ingestion; revisit only for §5.

---

## 5. Dual-repeating-LNS constraints  *(uplink LNS1 / downlink LNS2)*

**Verdict (from cross-LNS research):** "uplink to LNS1, downlink from LNS2" is **not** a single-identity LoRaWAN capability — a device session (keys, FCntUp/FCntDown, downlink timing) is owned by exactly one Network Server. The only spec path for one session across networks is operator **Roaming (LoRaWAN Backend Interfaces / TS002)**, which is **LNS↔LNS, device-transparent** — not a device-side trick. **Achieve it instead as TWO independent ABP sessions** the bridge owns: `radio1=ABP1` in LNS1, `radio2=ABP2` in LNS2; the bridge routes payloads between them at the **application layer** (re-encode/re-MIC per side).

**Hard constraints:**
1. **Two independent sessions** — each radio: own `DevAddr` + `NwkSKey` + `AppSKey`, own `FCntUp`/`FCntDown`, provisioned in *its* LNS. No key sharing across LNS; no MIC forging.
2. **Async downlink from LNS2 ⇒ radio2 must be Class C** — continuous RX2 on **LNS2's RX2 freq + DR**, so LNS2 can push downlinks (unicast or **multicast** — shared addr/keys/FCnt) anytime, untied to an uplink. *Class-A alternative:* radio2 **polls** by sending periodic uplinks to LNS2 and reading queued downlinks in RX1/RX2 — simpler, but downlink latency is bounded by the poll interval and duty-cycle.
3. **A reachable LNS2 gateway** + the downlink **enqueued** (ChirpStack device or multicast queue via API/UI). ChirpStack v4 supports Class C (reuses the device downlink queue) and multicast, but has **no built-in roaming and no TS011-relay** — the crosslink is *your* app-layer routing.
4. **It works only for identities the bridge OWNS** (ABP1/ABP2 it provisions). It **cannot transparently relay a third-party device** across networks — LoRaWAN security blocks forging the MIC or reading the encrypted payload without that LNS's keys.
5. **TS011 "Relay" does NOT apply** — that spec is a same-network, battery-powered coverage extender (Wake-on-Radio), not a cross-LNS bridge.
6. **Per-radio regulatory budgets** — duty-cycle/dwell/EIRP on each RF domain independently; RX2 DR/freq matched per LNS; continuous RX (Class C) power is fine on USB.

**Status:** documented; **implementation deferred to v8.3.2/v8.4.** v8.3.1 builds the one-way ABP uplink encoder without foreclosing this (keep keys/FCnt state per-radio-capable in the config schema, §8).

---

## 6. MT/MC → RNS encoder (carry-over) — ⏸️ DEFERRED (not in v8.3.1)

> **RNS coding is deferred this cycle (owner decision).** Retained below as the design of record for whenever it's picked up (8.3.2+); there is **no v8.3.1 implementation**.

- **(Phase 1 — tractable) Round-trip passthrough.** Reassemble RNS bytes previously tunnelled as `[rns <seq> <x>/<y>] <base64>` (fill in `reassembleReticulumFragment()`), then **raw re-emit** the reconstructed frame on an RNS radio. **No addressing/crypto** needed — the bytes are already a valid RNS frame. Closes the `RNS → MT/MC → RNS` round trip across two bridges.
- **(Phase 2 — optional, harder) Arbitrary MT/MC → new RNS packet.** Requires a **configured destination Identity/hash + encryption** to that destination (Reticulum addresses are destination-hash + Identity-keyed). Needs a new addressing-model config; assess feasibility before committing. Today `encodeReticulum()` (`MeshEncoderDebug.h` ~325) returns `false` and the dest-RNS path is a `no-rns-encoder` drop (`main.cpp` ~557).

---

## 7. Keyed vs keyless (architectural note)

v8.3 LoRaWAN is **keyless** (cleartext-header capture/relay only). v8.3.1's encoder is **keyed** (needs `NwkSKey`+`AppSKey` to mint valid uplinks). **Keep both:** keyless capture/relay remains the default for a radio set to "LoRaWAN" with no keys; the encoder activates only when a radio/dest is configured with ABP credentials. The two modes are mutually exclusive per radio and selected by presence of keys.

---

## 8. Config / NVS schema needs

- Per virtual device (M1) or per bridge device (M2): `DevAddr` (4 B), `NwkSKey` (16 B), `AppSKey` (16 B), **persisted `FCntUp`** (32-bit, write-throttled), FPort map, source→device mapping. For §5: a second set keyed per-radio + `FCntDown`.
- `BridgeConfig` schema **version bump** (current v4) with forward migration; new captive-portal section ("LoRaWAN device / ABP credentials"); a build-flag fallback for source builds.
- Delivery selector: **B1 RF re-emit** vs **B2 WiFi forwarder** (the latter adds gateway/MQTT config — host, credentials, gateway EUI).

---

## 9. Prioritized phases  *(effort S/M/L — refine from scope synthesis)*

1. **(M) AES-CMAC helper + `encodeLoRaWANUplink`** — ✅ **IMPLEMENTED 2026-06-15** (§0.0). RFC-4493 AES-CMAC + build/encrypt/MIC of a valid ABP uplink at the `no-lw-encoder` seam → push to `g_routeQ` (B1). Crypto unit-verified vs RFC4493 + an independent CMAC; both builds green. **Remaining = the on-air bench** (Custom/MT source → ABP uplink → real gateway → ChirpStack shows the decoded payload).
2. **(M) Config/NVS + portal** — ABP credentials + persisted FCnt + FPort map; schema bump + migration.
3. **(M) Universal mapping (M2 multiplexed)** — source tag + FPort/payload schema + a sample ChirpStack codec; **the weather-station (Custom-source) scenario as the acceptance test.**
4. **(L, optional) B2 bridge-as-gateway** — Semtech UDP / ChirpStack Gateway Bridge MQTT forwarder over WiFi (removes the separate-gateway requirement).
5. ~~MT/MC→RNS passthrough~~ — **DEFERRED → 8.3.2+** (RNS coding deferred this cycle, owner). §6 holds the design.
6. **(L, stretch → v8.3.2/v8.4) Dual-LNS crosslink** (§5) — second ABP identity per radio + Class-C (or Class-A poll) downlink path + cross-routing.
7. **(optional) M1 per-source devices; arbitrary MT/MC→RNS (§6 Phase 2); OTAA** — only if specifically wanted.

---

## 10. Risks & open questions

- **OTAA dropped (owner-approved):** OTAA-*encode* needs the JoinAccept **downlink** in a Class-A RX window + `DevNonce` uniqueness/state — impractical for an uplink-only emitter; OTAA-*decode* needs join-derived keys. **ABP only.** (Revisit only if a join-capable bidirectional mode is ever built.)
- **FCnt persistence vs flash wear** — write-throttle / store coarsely; relax-counters in ChirpStack as fallback.
- **Duty-cycle** — B1 (RF re-emit) doubles airtime; ensure the throttle enforces LoRaWAN regional limits.
- **CMAC availability** — confirm `MBEDTLS_CMAC_C`; else bundle a helper.
- **Per-source provisioning blow-up** (M1) — many devices to register; M2 avoids it.
- **Weather-station fork** — must confirm raw-LoRa (Fork B); if LoRaWAN (Fork A), it's a gateway task, not this.
- **Delivery model** — B1 vs B2 is the biggest scope lever; owner to choose.

---

## 11. References
- Repo: [`CLAUDE.md`](CLAUDE.md), [`V8.3-SPEC.md`](V8.3-SPEC.md), [`BENCH-v8.3.md`](BENCH-v8.3.md); seams `src/main.cpp` (`no-rns-encoder`/`no-lw-encoder` ~557/565), `src/MeshEncoderDebug.h` (`encodeReticulum` ~325, encode patterns), `src/MeshDecoderDebug.h` (`extractLoRaWANMeta` ~978-1012), `src/BridgeConfig.*`.
- External (cross-LNS research): LoRaWAN 1.0.4 MAC + Backend-Interfaces/Roaming (TS002), TS011 Relay, ChirpStack v4 docs (device classes / multicast / configuration / API). Cited in the v8.3.1 scope research + memory.

---

## 12. Scope-research findings (recovered 2026-06-15) — code-grounded

The v8.3.1 scope research (workflow `wf_815177cd-9aa`; LoRaWAN 1.0.4 spec + ChirpStack v4 docs + repo) is complete. Refinements to the sections above:

**Crypto — the one real gotcha (A4):**
- mbedTLS **AES-128 ECB + CTR are present & proven in-tree** (`MeshEncoderDebug.h` — MeshCore ECB ~73-81, Meshtastic CTR ~192-202/309-319); HMAC-SHA256, SHA-256, base64 too.
- ⚠️ **AES-CMAC is NOT linkable** — the prebuilt esp32s3 mbedTLS (arduino-esp32 2.0.17) was built with `CONFIG_MBEDTLS_CMAC_C` **OFF** (`tools/sdk/esp32s3/sdkconfig:1644`); `mbedtls_cipher_cmac` link-errors. **Add a self-contained RFC-4493 AES-CMAC helper (~40 lines)** on `mbedtls_aes_setkey_enc` + `mbedtls_aes_crypt_ecb` (both in the prebuilt lib). Only new crypto primitive required.

**Exact code seams (A2/A4):**
- **Encoder hook:** `main.cpp:565-569` — the `MT/MC → LoRaWAN` `drop=no-lw-encoder` site inside `enqueueTextForDest()` (`main.cpp:551-669`), with `dstChan`/`srcId`/`srcTag`/`body` in hand. Replace the drop → `encodeLoRaWANUplink()` → `outPkt[256]` → `g_routeQ[destIdx].push()` → `evt=QUEUE`; add `DedupCache::record(...)` for loop-safety (mirror MT ~610 / MC ~636 / dedup ~654-656).
- **Encoder template:** `encodeMeshtasticText` (`MeshEncoderDebug.h:121-206`). Deferral pattern: `encodeReticulum` stub (`:340`).
- **Decoder (inverse ref):** `extractLoRaWANMeta` (`MeshDecoderDebug.h:978-1012`) — cleartext header only; its `FCnt` is `uint16` (low 16) — the encoder needs the **full 32-bit** FCnt in B0/A_i.

**Config / NVS (A4):**
- `SCHEMA_VERSION=4` (`BridgeConfig.cpp:89`); `RadioChannel.key[32]` (`RadioChannel.h:19`) holds ONE AES key → **too small for NwkSKey+AppSKey** ⇒ **schema v4→v5** with a per-radio LoRaWAN credential struct (DevAddr/NwkSKey/AppSKey/FPort) + migration arm + a new `LoRaWANConfig::resolve()` (mirror `MeshCoreConfig::resolve` `:36-60`).
- **FCnt:** a **separate small NVS key** (`prefs.putUInt`), updated per-uplink — NOT the main blob `save()` (`BridgeConfig.cpp:337-348`) → avoids flash wear.
- **Portal:** `CaptivePortal.cpp:519-523` currently forces sync `0x34` and **clears** the key (keyless); add DevAddr/NwkSKey/AppSKey/FPort inputs gated to the `lw` class + save-handler validation.

**ChirpStack v4 (A3):**
- Provision: device-profile (region; **pin MAC 1.0.x**; ABP; Class A) → device with **DevAddr (private prefix, NetID 0x000000/0x000001)** + NwkSKey + AppSKey + FPort/codec.
- FCnt: persist 32-bit in bridge **or** tick **"Disable frame-counter validation"** (drops replay protection; a v4 quirk where `skipFCntCheck` didn't persist was reported — verify it sticks).
- **Wrong MIC ⇒ silent drop** (no app event). **ADR off + Unconfirmed** (uplink-only).
- **Timing:** EU868 ~1%/sub-band (single rolling `BRIDGE_TX_DUTY_PERCENT` only approximates, not per-sub-band ETSI); **US915 400 ms per-packet dwell — the rolling throttle does NOT enforce a per-TX ToA cap; add one** (`estimateAirtimeMs` at `main.cpp:971`).

**RNS (A1 — deferred §6):** keyless origination confirmed impossible (single-dest addr = SHA-256 over name + **destination public key**; payload = per-packet ephemeral-X25519 + Fernet AES-CBC/HMAC). Only keyless path = passthrough egress (reassemble `[rns ..]` fragments → `rawRepeatForDest`); stubs `MeshDecoderDebug.h:930` / `MeshEncoderDebug.h:340`; hook the marker on the MT/MC RX path (~`main.cpp:957-964`) **before** text decode. Deferred per owner.

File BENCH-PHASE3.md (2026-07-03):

# BENCH-PHASE3.md — LoRaCam Phase 3 (always-on web portal) bench verification

## ⭐ RESULTS 2026-07-03 — ALL GATING TESTS PASS on silicon (cam COM14 + quad-rig-host commander COM19 + Pixel)

**Gating set: 100% PASS.** Boot/AP/camera (P3-10/11/12) · WPA2-not-open + captive auto-pop (P3-20/21) ·
login + wrong-user/pass rejected + route gating + logout (P3-22/23/29) · live MJPEG + :81 sid-gate 401
(P3-24/25) · snap `result=0` + real file + status fields via fetch, video uninterrupted (P3-26/27) · snap
during live stream (P3-28) · **R1 sabotage neutralized** — saved R1=Meshtastic, blob persisted `proto=0`,
boot `Radio1 = None` (P3-30) · config edit persisted (`…-p3`, P3-40) · login change + old-pass reject
(P3-41 login half) · **do-no-harm with portal live**: `g`+`s` round-trips (rssi −66) incl. after the
config-save reboot (P3-50/51/55) · **5/5 C2 commands decoded while the phone streamed video** (P3-52) ·
**messaging both directions** — portal→master `evt=C2TX type=msg` + CAD + TX_DONE (27 B frame), and
commander `m` → cam `evt=C2MSG` → the message auto-appeared on the phone's Messages list (P3-33/P3-60) ·
**pairing lifecycle functional**: unpair → `drop reason=not-whitelisted` (RX'd at −66 but refused, no ACK)
→ re-pair via the portal → `res=0` again (P3-54). Config/pairing pages rendered repeatedly, no stack reset
(P3-35). **Two fixes came OUT of the bench** (both flashed + re-verified): ① the :81 stream ended on one
null frame → frozen `<img>` until refresh — now retries ~3 s before giving up; ② Android kills the MJPEG
connection on screen sleep with no error event — the page now reloads the stream on `visibilitychange`.
**Skipped (owner call):** AP-passphrase change (shares the proven `camportal` save path with the login
change) · soaks/multi-viewer/specials (Wave 5). **Open follow-ups:** first-flash product provisioning =
OPEN AP (gap #2 below) · Wave-5 specials. Pairing UX note: re-creating a deleted slot requires re-typing
the 32-hex PSK ("A new slot needs a 32-hex PSK" — correct fail-closed behavior, briefly confused the
operator). Final sizes: stock **865781 B byte-identical**, cam 978929 B, commander 872193 B.

---

Ordered by **impact toward completion**: each *wave* is batched by setup cost, so one flash / one WiFi
connect / one commander power-on unlocks the most tests before the next, more expensive, setup. Run the waves
top-to-bottom. **Gating** tests (marked ⛔) must pass before Phase 3 is shippable; the rest are recommended.

## Rig

- **CAM** — XIAO ESP32-S3 Sense (OV2640 socketed, no microSD) + hand-wired Wio-SX1262 V1.0 edge radio (R2),
  on **COM14**. Env `bench_camc2`. Flash: `…\platformio.exe run -e bench_camc2 -t upload --upload-port COM14`.
  Serial capture: `python C:\Users\6r4yh\cap.py COM14 <secs> --reset`.
- **COMMANDER** (waves 4–5 only) — a dual-SX1262 bridge on **~COM19** (drifts). Env `bench_camc2_cmdr`. Serial
  keys: `s`=snap `r`=record `x`=stop `g`=get-status `m`=send a T_MSG message to the cam.
- **Client** — a phone + a laptop on the cam's WiFi. Default AP `LoRaCam-XX` / passphrase `loracam-portal`;
  login `admin` / `loracam-admin`.

> **Pre-bench gap status:**
> 1. ✅ **R1 re-activation on save — FIXED 2026-07-03.** `BridgeConfig` now re-applies `LORA_RADIO{1,2}_DISABLE`
>    after every NVS blob load/migration AND before every save (`applyBuildDisables()`), so no stored config can
>    ever boot R1 onto the camera's B2B pins. Stock build verified still byte-identical (865781 B). **P3-30 is
>    now expected to PASS** — bench it to confirm.
> 2. ⚠️ **First-flash provisioning is an OPEN AP — still open (accepted for bench).** A fresh *product* build
>    (`xiao_loracam`, no autosave) hits the old blocking `CaptivePortal::begin()` = `WiFi.softAP(ssid)` with no
>    passphrase and an unauthenticated `/save`, BEFORE the always-on WPA2 portal exists. `bench_camc2` autosave
>    hides this. Affects **P3-43**; fix rides a follow-up.
> 3. ✅ **Commander `T_MSG` hook — ADDED 2026-07-03.** The bench commander now has an `m` serial key (sends a
>    signed "bench msg from commander" T_MSG to the cam) and prints any received T_MSG as
>    `evt=C2MSG … text="…"`. **P3-60 (messaging RX, ring tests) is now benchable.**

---

## WAVE 0 — zero hardware (build + code-review)

- ⛔ **P3-01 stock byte-identical** — `pio run -e xiao_esp32s3` → Flash **865781 B**. *(Already passing.)*
- **P3-02 captive-not-exposed** — code-review: on the cam, only the login-gated `CamPortal` serves :80 once
  configured; the unauthenticated `CaptivePortal::begin()` loop is NOT entered. *(See gap #2 for first-flash.)*
- **P3-03 R1-reactivation review** — confirm gap #1 above. PASS = a saved active R1 cannot reach the radio init
  on a camera build (after the fix).

## WAVE 1 — one fresh/erased cam flash, boot serial only

Erase + upload `bench_camc2` to COM14, then `cap.py COM14 20 --reset` ONCE. From that one capture:

- ⛔ **P3-10 boot lines** — see `[CamPortal] SoftAP "LoRaCam-XX" WPA2 up @ 192.168.4.1` **and**
  `[CamStream] MJPEG server up on :81 (/stream, /jpg)`.
- ⛔ **P3-11 camera still inits** — `[CameraNode] OV2640 ready (sensor PID=0x26) default SVGA` (Phase-3 didn't
  break camera-init ordering).
- **P3-12 default-creds warning** — `[CamPortal] WARNING: portal/WiFi using DEFAULT credentials (user=admin)`.

## WAVE 2 — one WiFi connect + one login (the big unlock; no reboot)

Scan → connect → log in ONCE, then sweep everything below on that session. Do the non-rebooting tests here.

- ⛔ **P3-20 SSID + WPA2** — `LoRaCam-XX` advertised (XX = node-id low byte); joins ONLY with `loracam-portal`
  (lock icon), never open.
- **P3-21 captive redirect** — a bogus host 302s to the portal / login.
- ⛔ **P3-22 login** — right creds → `sid` cookie + Home; **wrong password** and **wrong username** both
  rejected, no cookie.
- ⛔ **P3-23 route gating** — logged out, each of `/ /config /save /cmd /msg /peers /sec` 302s to `/login`.
- ⛔ **P3-24 live video** — Home shows live MJPEG; `/jpg?sid=…` returns one frame.
- ⛔ **P3-25 stream sid-gate** — `:81/stream` and `/jpg` with **missing** or **bad** sid → **401**.
- ⛔ **P3-26 snap + status** — Snap → `result=0` + a real `file=snap_800x600_…`; Status → parsed
  battery/uptime/lastCmd; uptime tracks `millis`.
- ⛔ **P3-27 fetch, no reload** — camera buttons update the result line via fetch without tearing down the live
  `<img>`.
- ⛔ **P3-28 mutex (cam-only)** — a portal Snap during a live stream: both succeed, no "camera busy" storm, no
  freeze.
- **P3-29 logout** — `/logout` invalidates the session; the old sid then 401s on the stream.
- **P3-31 config render + gate** — `/config` renders the full 4-radio captive form with live values; R1 shows
  **None**; `/config`+`/save` are login-gated; no-reboot validations fire (all-radios-None guard, bad freq).
- **P3-32 pairing UI** — `/peers` login-gated; **add** a new peer (id+PSK) → saved; field rejections (bad
  8-hex id, blank key on a new slot, wrong-length PSK); toggle **Primary**; **delete** a slot.
- **P3-33 messaging UI (send half)** — empty whitelist hides the send form; after a peer is added, sending via
  `/msg` logs `evt=C2TX … type=msg`; sending to a non-whitelisted id → `evt=C2DROP reason=no-such-peer`.
- **P3-34 XSS-inert** — a message body `<script>alert(1)</script>` renders as literal escaped text (no alert).
- **P3-35 big-page stack** — loading `/config` and `/peers` repeatedly does not trip a CamPortal-task stack
  overflow / reset.
- **P3-36 two-session cap** — a 3rd login (spaced >1 s) evicts one slot; the evicted client is cleanly 302'd
  to `/login` on its next request; the two live ones keep working.

## WAVE 3 — reboot-cost cam-only (batch the reboots)

- ⛔ **P3-30 R1 stays disabled after save** — benign field edit → Save → reboot → R1 still `PROTO_NONE`
  (never fights the camera). Fixed 2026-07-03 (`applyBuildDisables()`) — bench to confirm. For the adversarial
  arm, set R1 to a protocol in the form, Save, and verify the boot log still shows `Radio1 protocol = None`.
- **P3-40 config persists** — the edited field survives the reboot (BridgeConfig v5 round-trip).
- **P3-41 security chain** — change login (no reboot) → re-login with the new pass (old fails); change AP
  passphrase → reboot → reconnect on the NEW pass (old fails); the default-creds banner clears and stays clear.
  Reject a <8-char AP passphrase (no reboot, AP stays up).
- **P3-42 pairing persists** — a saved peer survives a power-cycle (`debugDump` shows the id).

## WAVE 4 — power on the commander once (~COM19), all two-board tests

- ⛔ **P3-50 do-no-harm round-trip** — with WiFi + both servers live, `g` from the commander still →
  `evt=C2CMD … res=0` (authenticated + executed) + ACK.
- ⛔ **P3-51 capture with portal up** — `s` still captures a real JPEG with the portal running.
- ⛔ **P3-52 RX not corrupted by WiFi** — fire `g` **5×** while a live MJPEG stream runs → **5/5** decode,
  rssi in the ~-58…-61 baseline.
- **P3-53 C2-snap vs stream (starvation)** — with 1–2 stream viewers up, fire `s` 10× → ≥9/10 give `res=0`
  (an occasional "capture skipped" is tolerable; repeated `res=4` = stream starves the snap mutex).
- ⛔ **P3-54 pairing functional** — delete the commander via `/peers` → its `g` is dropped
  `reason=not-whitelisted`; re-pair the id+key via `/peers` → `g` commands again (`res=0`); a wrong PSK →
  `reason=bad-mic`; a blank-key edit of the same id keeps the stored PSK (still commands).
- **P3-55 edge radio survives save** — after a config save+reboot, `g` still round-trips (persistence didn't
  break the control channel).

## WAVE 5 — special builds / extra clients / soaks (last)

- **P3-43 first-flash AP** ⚠️ — on a clean-NVS `xiao_loracam` (NOT bench), is provisioning open + unauthenticated?
  (Gap #2 — fix or consciously accept.)
- **P3-60 messaging RX (master→cam)** — commander `m` key → cam `evt=C2MSG` → the message appears in the portal
  Messages list (newest first; 13 sends wrap the 12-slot ring). **UNBLOCKED 2026-07-03** (commander hook added);
  runnable in Wave 4 while the commander is up.
- **P3-61 forged sender dropped** — a wrong-key `T_MSG` is dropped before `storeMessage` (needs a hostile TX).
- **P3-62 stream soak** — 15–30 min continuous stream + periodic snaps + `g`: no reset / watchdog / AP-drop /
  RX decay.
- **P3-63 session cross-task race** — hammer `/login`+`/logout` on :80 while a client loops `:81/jpg`: no
  crash, no frame served to a dead sid. (Code-review: `s_sess` has no lock across the two tasks.)
- **P3-64 NVS edge cases** (code-review / probe builds) — short-AP-pass forces-open at `begin()`; a
  `camportal` persist failure must not silently revert to default creds; per-frame `rx_<id>` NVS write
  amplification under chatty valid traffic.

---

## Gating set (must pass to ship Phase 3)

P3-01 · P3-10/11 · P3-20 · P3-22/23 · P3-24/25 · P3-26/27/28 · **P3-30 (R1 safety)** · P3-50/51/52 · P3-54.

## Definition of done

1. **Do-no-harm holds** — stock 865781 B; Phase-1 C2 round-trip + Phase-2a capture still work with WiFi + both
   servers up; 5/5 commands decode under a live stream; a save can't reactivate R1.
2. **The portal works** (the headline) — WPA2 AP + captive DNS; login + route-gating; live video + /jpg +
   sid-gate; snap + status via fetch without tearing the stream; the camera mutex serializes snap-vs-stream.
3. **Features pass** — config render/edit/persist/validate + gate; pairing add/delete/primary/persist +
   field-validation + the functional pair/unpair proof; security login + AP-pass change persist; messaging
   send (TX) + forged-drop.
4. **Stability holds** — a 15–30 min stream + snaps + commands with no reset / AP-drop / RX decay; the two
   biggest pages render without a stack overflow.

## Open decisions for the owner

- ~~Fix R1-reactivation before benching?~~ **DONE 2026-07-03** (`applyBuildDisables()` in BridgeConfig).
- ~~Add the commander `T_MSG` hook?~~ **DONE 2026-07-03** (`m` key + inbound T_MSG print).
- **Secure first-flash provisioning (gap #2)?** A fresh product cam is provisioned over an open AP today.
  Rides a follow-up cycle unless the owner wants it before the Phase-3 commit.

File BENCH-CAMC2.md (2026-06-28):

# BENCH-CAMC2 — end-to-end LoRaCam C2 round-trip (two boards)

Goal: prove a real **encrypted, signed, whitelisted** command goes from a commander board
to the cam board over LoRa, the cam acts on it, and ACKs back — on your bench.

## What you need
- **Board A = the cam** — the XIAO ESP32-S3 Sense + the Wio you already wired. On **COM14**.
- **Board B = the commander** — a SECOND XIAO + a Wio, wired the SAME way (SPI on D8/D9/D10,
  NSS→D4 / BUSY→D3 / RST→D2 / DIO1→D1, 3V3, GND). **A repeater board works as-is** (its R2 is
  that exact radio). No camera needed on board B.

Both boards already share a throwaway bench key and fixed IDs (cam = `0xCA00`, commander = `0xC0DE`),
baked into the build flags — so they whitelist each other with no manual key entry.

## Steps (one at a time)

**1. Flash the cam** (board A, COM14) — already done for you:
```
pio run -e bench_camc2 -t erase  --upload-port COM14
pio run -e bench_camc2 -t upload --upload-port COM14
```
Boot log should show: `[CamC2Config] bench-seeded peer 0x0000c0de` and `[Radio2-Edge] ready ... sync 0x33`.

**2. Flash the commander** (board B). Find its port (e.g. COM13), then:
```
pio run -e bench_camc2_cmdr -t erase  --upload-port COM13
pio run -e bench_camc2_cmdr -t upload --upload-port COM13
```

**3. Open BOTH serial monitors** (two terminals):
```
pio device monitor --port COM14      ← the cam
pio device monitor --port COM13      ← the commander
```

**4. Wait ~6 seconds** after the commander boots (it has a 5 s "press BOOT for portal" window first).

**5. In the COMMANDER monitor, type one key** (just press the letter — no Enter needed):
- `g` = get status   ·   `s` = snap photo   ·   `r` = record 30 s   ·   `x` = stop

**6. What you should see — the round-trip:**

Commander:
```
evt=C2TX radio=1 to=0x0000ca00 cmd=6 seq=1
evt=C2RX radio=1 from=0x0000ca00 type=2 seq=1 len=9      ← the cam's signed ACK
```
Cam (COM14):
```
evt=C2CMD radio=1 from=0x0000c0de cmd=6 seq=1 res=0      ← authenticated + executed (res=0 = OK)
[CamC2] (stub) ...                                       ← Phase-1 stub; real camera lands in Phase 2
```

`res=0` = the command was accepted (valid signature, in-whitelist, fresh seq) and run. The camera
actions are stubs for now (`stub.jpg`) — Phase 2 wires the real OV2640/SD.

## Quick checks it's really secure (optional)
- **Wrong key rejected:** flash board B with a different `BRIDGE_C2_PEER_KEY` (edit the env) → the cam
  logs `[CamC2] drop ... reason=bad-mic` and does NOT execute.
- **Replay rejected:** every command uses a new `seq`, so re-sends are new. To force a replay, capture a
  frame and resend it (see the offline tool) → cam logs `evt=C2DROP ... reason=replay`.

## Offline frame tool (no hardware)
`tools/cam-c2.py` builds/verifies frames with the same crypto as the firmware:
```
python tools/cam-c2.py selftest                                  # crypto KAT
python tools/cam-c2.py gen 000102030405060708090a0b0c0d0e0f 1 0000C0DE 0000CA00 1 06   # a GET_STATUS cmd
python tools/cam-c2.py verify <frame-hex> 000102030405060708090a0b0c0d0e0f             # decode/verify
```
Use `verify` on a frame captured by a sniffer to confirm what's on air, byte-for-byte.

## Notes
- Both boards are on the same C2 channel: **Custom sync 0x33, 906.875 MHz, BW250, SF9** (build defaults).
- The bench key/IDs are throwaway — never a real deployment key.
- These are **bench** envs (`BRIDGE_BENCH_AUTOSAVE`, fixed IDs, build-flag key); the shipping `xiao_loracam`
  build uses MAC-derived IDs and portal/serial provisioning (Phase 3), and stays do-no-harm.

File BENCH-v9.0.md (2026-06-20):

# BENCH-v9.0.md — "2xiao_4sx1262" bench verification

双小型处理器全向四路射频亚千兆赫兹全向桥接中继器

Bench plan for **v8.5**: two Xiao dual-SX1262 boards joined by a UART crossover into one
**4-radio sub-GHz bridge** (host + radio co-processor), with a per-radio routing matrix. All four
radios are SX1262 (sub-GHz only).

> Status: **proposed plan** — review/finalize the test list + the gating set, then we run it and tag
> v8.5. Tag is owner-gated; nothing is pushed until the gating set passes and you OK it.

---

## 1. Rig & conventions

**Hardware**
- **DUT** = the 2-board bridge: **Host (Board A)** + **Co-processor (Board B)**, joined by the UART
  crossover. Host runs `xiao_esp32s3`; co-proc runs `xiao_coproc_sx1262`.
- **Nodes**: 2+ Meshtastic, 2+ MeshCore (real radios).
- **Sniffer** = your spare Xiao dual-SX1262 bridge. Flash `bench_lw_sniffer` to capture LoRaWAN
  (`evt=RX proto=LW` + `evt=LWRAW raw=…`), or a stock bridge build to RX-log / generate stimulus.

**UART crossover wiring** (same pins both boards; the cable does the crossover):
```
Board A (host)  D6 (GPIO43, TX) ──────► D7 (GPIO44, RX)  Board B (co-proc)
Board A (host)  D7 (GPIO44, RX) ◄────── D6 (GPIO43, TX)  Board B (co-proc)
Board A (host)  GND ──────────────────── GND             Board B (co-proc)
```
Power each board over its own USB (or share 5V). The link is `Serial1`; the USB-CDC `Serial` stays
the debug console on both boards.

**RF discipline** (the four radios are co-located → they desense each other):
- Region **US915**. **TX ≤ 10 dBm**. Antennas separated; all antennas connected before power.
- Give **each radio a distinct frequency** (real deployments separate the two boards physically).

**Suggested sub-GHz frequency plan** (adjust to your nodes):

| Role | Freq (MHz) | BW (kHz) | SF | Sync |
|---|---|---|---|---|
| Meshtastic LongFast (public) | 906.875 | 250 | 11 | 0x2B |
| Meshtastic private | 905.0 | 250 | 11 | 0x2B (distinct PSK) |
| MeshCore public | 910.525 | 62.5 | 7 | 0x12 |
| MeshCore private | 909.0 | 62.5 | 7 | 0x12 (distinct key) |
| LoRaWAN uplink (Device 1) | 903.9 | 125 | 7 | 0x34 |
| LoRaWAN uplink (Device 2) | 904.1 | 125 | 7 | 0x34 |
| LoRaWAN **US915 RX2** (downlink listen) | 923.3 | 500 | 12 | 0x34 |

**Decode**: `tools/lw-verify.py` (offline MIC-verify + decrypt — no ChirpStack needed). Full
ChirpStack ingestion is the colleague's separate v8.4 Tier-C item (give them DevAddr `0x01000001` +
the bench keys).

---

## 2. Build & flash

```
# Host (Board A) — use _v1_1 if this board's Radio-2 edge module silkscreen reads V1.1
pio run -e xiao_esp32s3 -t upload --upload-port COM_A

# Co-processor (Board B) — note -d points at the subproject; _v1_1 for a V1.1 edge module
pio run -d coproc-xiao-sx1262 -e xiao_coproc_sx1262 -t upload --upload-port COM_B
```
Then monitor the host: `pio device monitor --port COM_A`. Configure the 4 radios + routing matrix in
the captive portal (SoftAP `LoRa-Bridge-XX` @ 192.168.4.1), Save, reboot.

---

## 3. Tests

Each test lists **Setup → Do → PASS**. Gating tests must pass to tag v8.5 (see §4).

### Group 0 — Bring-up & regression  *(all GATING)*

**0.1 Link up**
- Setup: both boards flashed + crossover wired; R3/R4 enabled in the portal.
- Do: power both, watch the host monitor.
- PASS: host prints `[UartLink] co-processor READY` and `[coproc] R3 cfg ok: …` / `[coproc] R4 cfg
  ok: …` echoing the freq/SF you set; host prints `[R3] remote begin -> sent …` / `[R4] …`.

**0.2 Config echo**
- Do: after Save+reboot, read the boot `[BridgeConfig]` dump.
- PASS: all four radios listed with the protocol / frequency / `route=0x..` you configured.

**0.3 Do-no-harm (single board = v8.4.1)**
- Setup: **one board only**, R3/R4 = None (R1 = MT, R2 = MC), no co-proc attached.
- Do: normal MT↔MC bench.
- PASS: behaves exactly like v8.4.1; boot shows **no** `[UartLink]` line and Serial1 is never opened.

### Group A — 4-radio mesh routing  *(your Test A — A1/A2 GATING; A3/A4 recommended)*

Setup: **R1 = MT public** (906.875), **R2 = MT private** (905.0, distinct PSK), **R3 = MC public**
(910.525), **R4 = MC private** (909.0, distinct key). R3/R4 are on the co-proc.

**A1 — full mesh** (every radio routes to all three others)
- Do: TX from a node on the MT-public channel.
- PASS: the message appears on the MT-private, MC-public and MC-private networks (cross-protocol
  translated MT↔MC); an echoed copy is loop-dropped (`evt=DROP … drop=…dup`). Repeat sourcing from
  each of the four channels.

**A2 — restricted matrix** (R1↔R2 and R3↔R4 only)
- Do: re-save the matrix so R1 routes only to R2 and R3 only to R4 (and vice-versa); TX from MT-public,
  then from MC-public.
- PASS: MT-public reaches **only** MT-private; MC-public reaches **only** MC-private. Nothing crosses
  between the MT pair and the MC pair → proves `routeMask` isolation.

**A3 — cross-board hop** *(recommended)*
- Do: with R1→R3 routed, TX on R1 (MT).
- PASS: it **egresses on R3** (the co-proc transmits; an MC-public node or the sniffer hears it) —
  proves the UART link carries a TX to a remote radio.

**A4 — loop / dedup at scale** *(recommended)*
- Do: under the full mesh (A1), flood the same packet repeatedly.
- PASS: dedup holds across the 4-way mesh — no runaway re-bridging; duplicates dropped.

### Group B — LoRaWAN + downlink-readiness  *(your Test B + the OTAA-enabler tests)*

Setup: **R1 = MT public**, **R2 = MC public**, **R3 = LoRaWAN Device 1** (DevAddr `0x01000001`,
903.9/SF7), **R4 = LoRaWAN Device 2** (distinct DevAddr/keys, 904.1/SF7).

**B1 — uplink encode + decode** *(GATING)*
- Do: route an MT or MC message to R3 (LoRaWAN); run the sniffer (`bench_lw_sniffer`) on 903.9/SF7.
- PASS: sniffer logs `evt=RX proto=LW devaddr=01000001 …` + `evt=LWRAW raw=…`; feed the raw frame +
  keys to `tools/lw-verify.py` → **MIC PASS** and the decrypted FRMPayload equals the message.

**B2 — two distinct devices** *(recommended)*
- Do: route a message to R3, then one to R4.
- PASS: R3 mints a **DevAddr-1** uplink and R4 a **DevAddr-2** uplink; each decodes with its own keys
  (the per-source ABP device table works across the link, on a remote radio).

**B3 — downlink-listener (the OTAA enabler)** *(recommended — strongly suggested before tag)*
- Setup: R3 = LoRaWAN uplink 903.9/SF7; **R4 = LoRaWAN US915 RX2 = 923.3 / BW500 / SF12**.
- Do: with the sniffer (or a node) transmitting a LoRaWAN frame on 923.3/SF12, also exercise R3 on its
  own channel.
- PASS: **R4 receives the 923.3 frame** (`evt=RX radio=R4 proto=LW`) **while R3 stays on its own
  channel** and remains functional. This proves the bridge can hold a **dedicated always-on downlink
  listener** concurrently with the uplink radio — the exact capability the 4-radio architecture adds for
  v8.5+ OTAA (see §5).

**B4 — intended production topology** *(recommended)*
- Setup: **Board A = mesh** (R1 MT public / R2 MC public); **Board B = LoRaWAN** (R3 uplink 903.9/SF7,
  **R4 = RX2 listener 923.3/SF12**).
- Do: a mesh message → routed to R3 (uplink); independently, a 923.3 frame arrives.
- PASS: the mesh message mints an uplink on R3 (sniffer decodes) **and** R4 hears the 923.3 frame —
  the "mesh board + LoRaWAN board" split runs end-to-end.

### Group C — Robustness  *(recommended / optional)*

**C1 — link resilience** *(recommended)*
- Do: power-cycle the co-processor while the host runs.
- PASS: the host does not crash or wedge; R3/R4 go silent, then recover (`[UartLink] co-processor
  READY` again + `R3/R4 cfg ok`) when the co-proc reboots.

**C2 — sustained load / airtime** *(optional)*
- Do: steady MT/MC traffic under the A1 full mesh.
- PASS: no UART overflow or route-queue starvation; the airtime throttle paces the bridge's TX.

---

## 4. Gating set for the v8.5 tag

**Must pass:** 0.1, 0.2, 0.3, A1, A2, B1.
**Strongly recommended before tag:** A3, B3 (downlink-listener), C1.
**Optional / can defer:** A4, B2, B4, C2.

---

## 5. What this de-risks for v8.5+ OTAA (and what stays future work)

The motivation for going 2→4 radios is **LoRaWAN OTAA**: the device must receive a **JoinAccept
downlink** in an RX window ~1–2 s after its uplink. A 2-radio bridge can't transmit the uplink *and*
retune to listen for the downlink. **Four radios let you dedicate one radio as an always-on downlink
listener** on the fixed US915 RX2 channel (923.3 / SF12) while another radio does the uplink — no
retune.

- ✅ **B3 / B4 prove the radio capability** OTAA needs: a downlink-channel listener running
  *concurrently* with the uplink radio on the co-processor.
- ⏳ **Still future (v8.5+):** the *protocol* layer — opening the RX1/RX2 window timed to an uplink,
  decoding a real JoinAccept, FCnt/DevAddr correlation, and a real LNS-originated downlink (needs a
  downlink-capable gateway behind ChirpStack). This bench confirms the hardware/firmware substrate is
  ready; it does not test the OTAA protocol itself.

---

## 6. Quick reference — serial lines to look for

| Event | Line (host monitor) |
|---|---|
| Co-proc link up | `[UartLink] co-processor READY (… B info)` |
| Co-proc radio configured | `[coproc] R3 cfg ok: 906.875 MHz BW250.0 SF11 CR4/5 20dBm sync0x2B` |
| Host pushed R3/R4 config | `[R3] remote begin -> sent  906.875 MHz BW250.0 SF11 …` |
| A radio received a packet | `… evt=RX radio=R3 …` |
| LoRaWAN capture (sniffer) | `evt=RX proto=LW devaddr=01000001 fcnt=… fport=…` + `evt=LWRAW raw=…` |
| Loop/dup dropped | `… evt=DROP … drop=…dup` |
| Single-board (do-no-harm) | **no** `[UartLink]` line at boot |

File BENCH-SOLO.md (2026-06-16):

# Solo bench tests — the ones you run by hand

These need the board's WiFi config page (or special gear), so you drive them. The rest
(A1, A2, A5, B1, B2, B5) I run from here. Each test below is self-contained.

## Stuff you repeat for every test (do once per flash)

**1. Flash the config-page build to the sender (COM13):**
```
pio run -e xiao_esp32s3_lwabp -t erase  --upload-port COM13
pio run -e xiao_esp32s3_lwabp -t upload --upload-port COM13
```

**2. Get on the config page:**
- After flashing, the board makes an **open WiFi network named `LoRa-Bridge-XX`** (the exact
  name prints on the serial monitor at boot). Connect your phone/laptop to it.
- A settings page should open by itself. If not, open a browser to **http://192.168.4.1**.

**3. Set Radio 2 to LoRaWAN** (so the packet goes where the listener can hear it):
- Radio 2 → **Protocol: LoRaWAN**, **Frequency: 903.9**, **Bandwidth: 125**, **Spreading factor: 7**.

**4. The keys** (paste where a test asks for them):
- NwkSKey: `2B7E151628AED2A6ABF7158809CF4F3C`
- AppSKey: `D41420B7F5A3C96E1D8204F7B3A65C90`

**5. Watch the result:** keep the listener's monitor open while you send —
`pio device monitor --port COM6 --baud 115200`. (A4 and A3 watch the sender COM13 instead.)

The device table is the section titled **"LoRaWAN ABP devices (v8.4 encoder)"**. Each device row
has: **Enabled** checkbox · **Applies to source** (Any source / Meshtastic node id / Source
protocol) · **Match value** · **DevAddr (8 hex)** · **NwkSKey** · **AppSKey** · **FPort** ·
**Prepend source tag** checkbox. After filling, scroll down and click **Save** — the board reboots.

---

## A4 — does the config page save?
1. Flash `xiao_esp32s3_lwabp`, get on the page, set Radio 2 = LoRaWAN.
2. Device 0: **Enabled** ✓ · Applies to source = **Any source** · DevAddr = `01000001` ·
   NwkSKey/AppSKey = the keys · FPort = `13`. **Save.**
3. Watch the sender: `pio device monitor --port COM13 --baud 115200`, press the board's **RST**.
4. **PASS:** you see `[LoRaWANConfig] loaded … anyConfigured=1` and
   `dev0 … devaddr=0x01000001 fport=13`.

## B3 — moving an address keeps its counter
1. Do A4 (Device 0 = `01000001`, Any). Send **3 texts** from your Meshtastic device; on the
   **listener (COM6)** note the `fcnt=` numbers.
2. Back on the page: **uncheck** Device 0's Enabled. In **Device 1**, enter the **same**
   address `01000001` + the same keys + FPort 13 + Any source. **Save.**
3. Send one text. On COM6 note the new `fcnt=`.
4. **PASS:** the new `fcnt=` is **higher** than the last one from step 1 (it did not reset).

## B4 — the right address is picked per sender
1. Flash `xiao_esp32s3_lwabp`, page, Radio 2 = LoRaWAN.
2. Two devices, same keys, different addresses:
   - **Device 0:** Applies to source = **Meshtastic node id** · Match value = **your node's
     8-hex id** (the one shown in the Meshtastic app, e.g. `0AC9F340`) · DevAddr `01000001` · FPort 13.
   - **Device 1:** Applies to source = **Source protocol** · Match value = **1** · DevAddr
     `01000002` · FPort 13.
   **Save.**
3. Send a text from the node whose id you put in Device 0. Then send from a **different**
   Meshtastic node.
4. **PASS (on COM6):** the first node's packet shows `devaddr=0x01000001` (its specific match
   won); the other node shows `devaddr=0x01000002` (matched by protocol).

## B6 — source tag decodes to the right protocol
1. Flash `xiao_esp32s3_lwabp`, page, Radio 2 = LoRaWAN.
2. Device 0: Enabled · Any source · DevAddr `01000001` · keys · FPort 13 · **check "Prepend
   source tag"**. **Save.**
3. Send a text from your Meshtastic device. On COM6, copy the `raw=` hex from the `evt=LWRAW` line.
4. Run:
   `python tools/lw-verify.py <paste-hex> 2B7E151628AED2A6ABF7158809CF4F3C D41420B7F5A3C96E1D8204F7B3A65C90 --tagged`
5. **PASS:** output shows `src tag : proto=1(meshtastic) …`. (Repeat from a MeshCore device → `proto=2(meshcore)`.)

## B7 — a MeshCore message also works
1. Flash `xiao_esp32s3_lwabp`, page. Set **Radio 1 → Protocol: MeshCore**, and Radio 2 → LoRaWAN
   903.9 / 125 / SF7.
2. Device 0: Enabled · Any source · DevAddr `01000001` · keys · FPort 13. **Save.**
3. Send a text from a **MeshCore** device.
4. **PASS (on COM6):** an `evt=RX proto=LW devaddr=0x01000001` line; run the captured `raw=` hex
   through `lw-verify.py` (no `--tagged`) → it decrypts to your MeshCore text.

## A3 — oversize packet is dropped (needs gear I have to prep)
This needs a transmitter that sends a **raw LoRa packet over 242 bytes** on a Custom channel —
nothing on your bench does that yet. Say the word and I'll flash a spare board (COM14) to be that
transmitter. Then:
1. Flash `xiao_esp32s3_lwabp`, page, set **Radio 1 → Protocol: Custom** (matching the
   transmitter's freq/BW/SF/sync), Radio 2 → LoRaWAN.
2. Device 0: Enabled · Any source · DevAddr `01000001` · keys · FPort 13. **Save.**
3. Trigger the transmitter.
4. **PASS (on COM13):** `evt=DROP … drop=lw-payload-overflow`.

---
When you finish one, paste me the serial line and I'll confirm — or just read the PASS line yourself.

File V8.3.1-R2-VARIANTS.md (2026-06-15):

# v8.3.1 — Radio 2 module-revision (V1.0 / V1.1) variants + bring-up hardening

Porting / change record for the v8.3.1 patch. Purpose: document exactly what
changed and how to fold it into the other dual-SX1262 branches (primarily
`dev-ABP-lorawan`, also `T_LORA_QUAD*`, `lr1121-phase1`).

Authored on branch `v8.3.1-r2-pin-variants` off `main` (= v8.3 + post-ship docs).

---

## 1. Root cause (one paragraph)

Seeed ships the **"Wio-SX1262 for XIAO" edge module (Radio 2) with two different
pinouts**. The chip-select (NSS) is on **D4 / GPIO5** on **V1.0** but **D3 / GPIO4**
on **V1.1**. The v8.x firmware only ever shipped the V1.0 map. On a **V1.1** module
that map drives the wrong GPIO as NSS, so the module's *real* chip-select (GPIO4)
is never parked — and `busyWait(R2)` actively reconfigures it to a floating
`INPUT`. The un-deselected V1.1 chip then drives the **shared MISO** during Radio
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

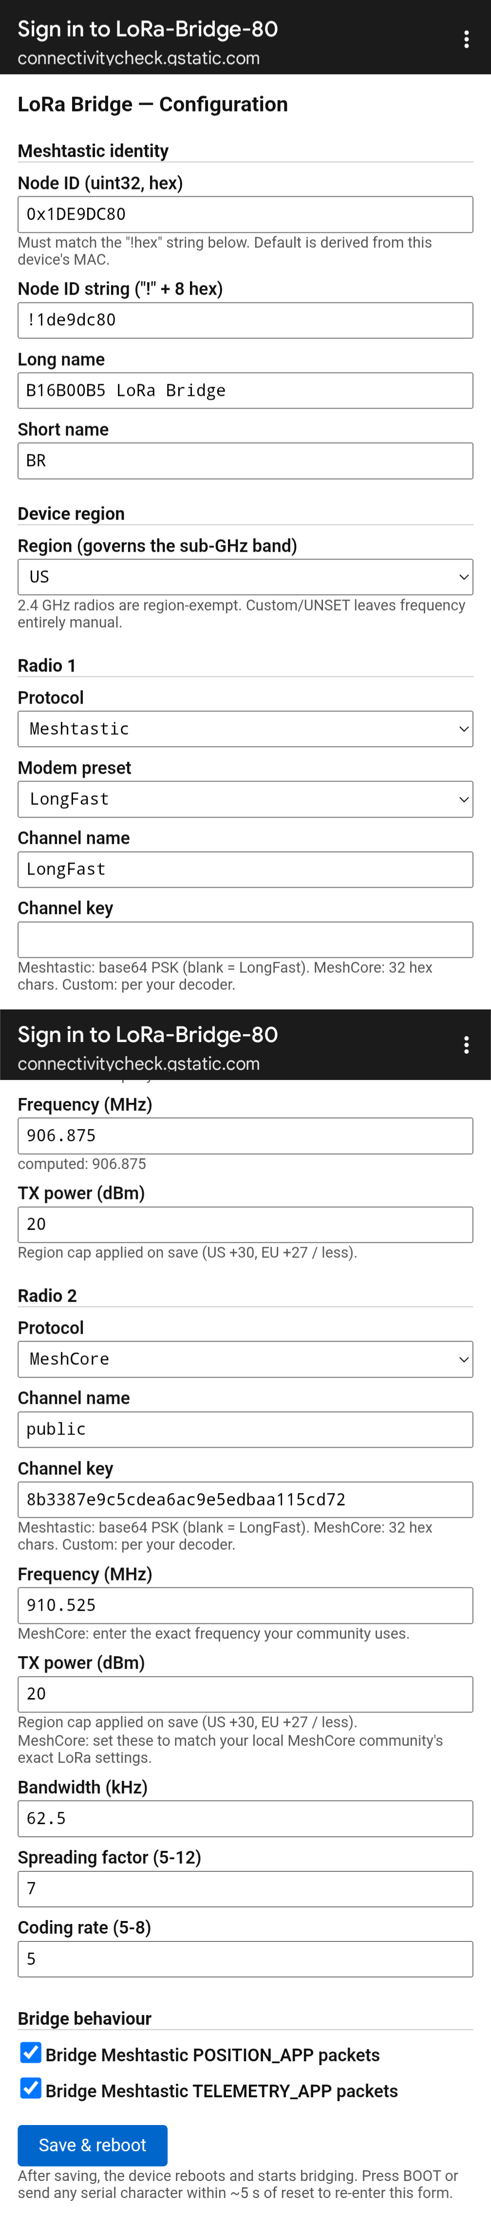
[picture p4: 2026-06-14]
images/captive-portal.png

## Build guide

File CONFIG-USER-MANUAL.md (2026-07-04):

# LoRa Bridge — WiFi Config Portal & Compile-Time Settings

A field-by-field guide to the captive **WiFi configuration portal** and the
matching **`platformio.ini` build flags**. For flashing and hardware setup see the
[README](README.md#instructions); this manual covers *configuration only*.

Everything in the portal can also be **preloaded at compile time** so a fresh board
boots already configured — each field below names its build flag where one exists,
and [§8](#8-preloading-with-compile-time-build-flags) shows ready-made example builds.

---

## Contents
1. [Reaching the config portal](#1-reaching-the-config-portal)
2. [How to read this manual](#2-how-to-read-this-manual)
3. [Top frame — identity, region & bridge behaviour](#3-top-frame--identity-region--bridge-behaviour)
4. [Per-radio configuration](#4-per-radio-configuration)
   - [4.8 Radio 3 & Radio 4 (the second XIAO)](#48-radio-3--radio-4-the-second-xiao)
   - [4.9 Routing matrix — "Bridge received traffic to"](#49-routing-matrix--bridge-received-traffic-to)
5. [LoRaWAN ABP devices](#5-lorawan-abp-devices)
6. [Saving](#6-saving)
7. [Example setups](#7-example-setups)
8. [Preloading with compile-time build flags](#8-preloading-with-compile-time-build-flags)
9. [Other build flags (reference)](#9-other-build-flags-reference)
10. [LoRaCam — camera setup, pairing & the web portal](#10-loracam--camera-setup-pairing--the-web-portal)

---

## 1. Reaching the config portal

- A **fresh or erased** board boots straight into the portal.
- On an **already-configured** board, reset it and — within the ~5 s window the
  serial log announces — press the **BOOT** button *or* send any character in the
  serial monitor. (The serial route matters when BOOT is hidden under a shield.)
  If neither works, erase the device (`pio run -t erase`) and it reboots into the portal.
- The bridge raises an open WiFi access point named **`LoRa-Bridge-XX`** (`XX` = the
  last byte of the node ID, unique per board). Join it from a phone or laptop; any
  web request is redirected to the single-page form at **`192.168.4.1`**.

The form is one long page: **identity → device region → bridge behaviour → Radio 1
→ Radio 2 → Radio 3 → Radio 4 → LoRaWAN ABP devices → Save**. Each radio also has a
**routing matrix** row. Hit **Save & reboot** to apply. (On a single Xiao, leave Radio 3
and Radio 4 set to `None`.)

> **Four-radio (two-Xiao) setups:** only the **master** Xiao runs this portal. It holds
> the WiFi config and the settings for *all four* radios, and programs **Radio 3 / Radio 4**
> on the co-processor Xiao over the UART link — the co-processor has no portal of its own.

---

## 2. How to read this manual

- **Fields are described once.** The per-radio fields (Protocol, Channel name,
  Channel key, Frequency, TX power, Bandwidth/SF/CR, Sync word) are the same for
  every radio, so they are defined once in [§4.1](#41-fields-common-to-every-radio);
  each protocol section only covers what is *special* about it.
- **Build flag:** where a field has a compile-time default, it is shown as
  `Build flag: FLAG_NAME`. All flags live in [`platformio.ini`](platformio.ini) and
  are optional — the portal overrides them at runtime. Fields with no flag are
  *portal-only* (stored in NVS, not settable at compile time).

---

## 3. Top frame — identity, region & bridge behaviour

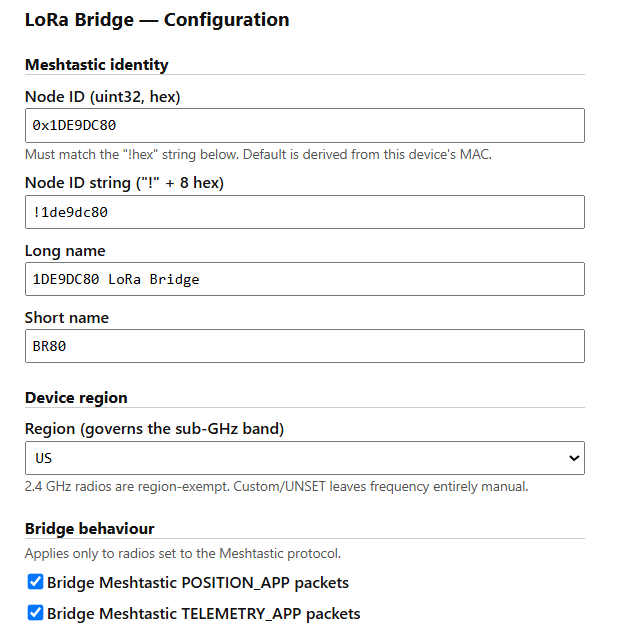
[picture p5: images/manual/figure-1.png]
Figure 1 — identity, region and bridge behaviour


### Meshtastic identity

| Field | What it is | Build flag |
|---|---|---|
| **Node ID (uint32, hex)** | The bridge's own Meshtastic node number. Must encode the same value as the string below. On a fresh board it is **derived from the device MAC** (unique per board). | *MAC-derived; portal-editable* |
| **Node ID string ("!" + 8 hex)** | The same number in Meshtastic's `!`-hex form. Validated to match the Node ID. | *MAC-derived; portal-editable* |
| **Long name** | The bridge's Meshtastic long name shown in clients. On a fresh board it defaults to **`<NodeID> LoRa Bridge`** (e.g. `1DE9DC80 LoRa Bridge`). | *auto from node ID; portal-editable* |
| **Short name** | The bridge's Meshtastic short name (max 8 chars). Defaults to **`BR` + the node ID's low byte** (e.g. `BR80`). | *auto from node ID; portal-editable* |

### Device region

| Field | What it is | Build flag |
|---|---|---|
| **Region (governs the sub-GHz band)** | Sets the sub-GHz band and the **TX-power cap applied on save** (e.g. US +30 / EU +27 dBm, further clamped to the SX1262's +22 dBm hardware max). **2.4 GHz radios are region-exempt**; `Custom`/`UNSET` leaves frequency entirely manual. This is a *device-wide* setting, **not** the LoRaWAN region (that is per-radio — see [§4.4](#44-lorawan)). | `BRIDGE_REGION` |

### Bridge behaviour

> *"Applies only to radios set to the Meshtastic protocol."*

| Field | What it is | Build flag |
|---|---|---|
| **Bridge Meshtastic POSITION_APP packets** | When on, decode + bridge Meshtastic position packets; off keeps them local to the MT mesh. | `BRIDGE_MT_POSITION` |
| **Bridge Meshtastic TELEMETRY_APP packets** | When on, decode + bridge Meshtastic telemetry packets. | `BRIDGE_MT_TELEMETRY` |

---

## 4. Per-radio configuration

A single Xiao has two radios: **Radio 1** (the B2B shield) and **Radio 2** (the edge
module). Adding a second Xiao as a **radio co-processor** over a UART crossover gives you
**Radio 3** and **Radio 4** as well (see [§4.8](#48-radio-3--radio-4-the-second-xiao)).
Each radio picks a **Protocol**, which shows/hides the fields below.

> **Classic 2-radio bridge:** leave **Radio 3** and **Radio 4** set to **`None`** (their
> default) and you have the original two-radio Meshtastic ↔ MeshCore bridge — no second
> Xiao, no UART link, no behaviour change. The Radio 3/4 fields and the routing matrix
> below simply do nothing, and existing saved configs upgrade unchanged.

> **The figures below show Radio 1 / Radio 2**, but the same fields and behaviour apply
> to **Radio 3 / Radio 4** — they are configured identically, just hosted on the second
> (co-processor) Xiao.

### 4.1 Fields common to every radio

These appear (in this order) for most protocols; each protocol section notes which
it shows and any special behaviour.

| Field | What it is | Build flag (per radio `N` = 1–4) |
|---|---|---|
| **Protocol** | What the radio speaks: `Meshtastic`, `MeshCore`, `Reticulum`, `LoRaWAN`, `Custom`, or `None`. Picking it sets the LoRa **sync word** automatically (except Custom). | `LORA_RADIO N _SYNC_WORD` (0x2B MT · 0x12 MC · 0x42 RNS · 0x34 LoRaWAN) |
| **Channel name** | A display/label for the channel. For Meshtastic it is also part of the channel hash, so it matters on air (see §4.2). Locked or `N/A` for some protocols. | `LORA_RADIO N _CHANNEL_NAME` (or the global `BRIDGE_MT_CHANNEL_NAME` / `BRIDGE_MC_CHANNEL_NAME`) |
| **Channel key** | The channel secret: a **base64 PSK** for Meshtastic, **32 hex chars** for MeshCore, decoder-specific for Custom. The on-air channel-hash byte is derived automatically. | `LORA_RADIO N _CHANNEL_KEY` (or global `BRIDGE_MT_PSK_B64` / `BRIDGE_MC_KEY_HEX`) |
| **Frequency (MHz)** | The center frequency. | `LORA_RADIO N _FREQUENCY` |
| **TX power (dBm)** | Transmit power; the region cap (and the SX1262's +22 dBm max) is applied on save. | `LORA_RADIO N _TX_POWER` |
| **Bandwidth (kHz)** | LoRa bandwidth (7.8–500). | `LORA_RADIO N _BANDWIDTH` |
| **Spreading factor (5–12)** | LoRa SF. | `LORA_RADIO N _SPREAD_FACTOR` |
| **Coding rate (5–8)** | LoRa CR (the "5"–"8" denominator of 4/N). | `LORA_RADIO N _CODING_RATE` |
| **Sync word (hex)** | *Custom only* — the raw LoRa sync word. | `LORA_RADIO N _SYNC_WORD` |

> **Bandwidth/SF/CR must match the network you are bridging**, or nothing decodes
> (MeshCore: your community's; LoRaWAN: your channel's; Reticulum: both ends must match).

### 4.2 Meshtastic

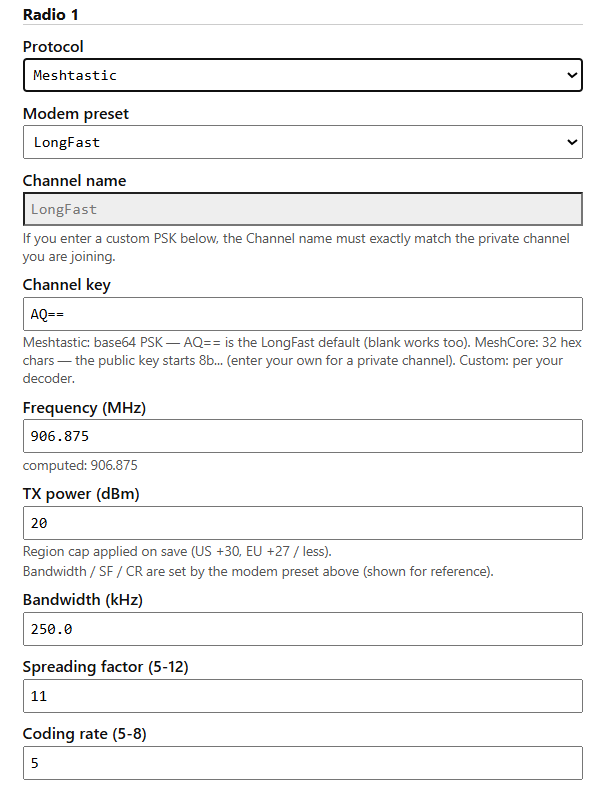
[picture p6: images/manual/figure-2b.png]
Figure 2b — Radio set to Meshtastic


- **Modem preset** *(Meshtastic only)* — picks a standard Meshtastic preset
  (LongFast, etc.). Choosing a preset **auto-fills Frequency and Bandwidth/SF/CR**
  to that preset's values. *No build flag of its own* — the preset is inferred from
  the radio's `LORA_RADIO N _BANDWIDTH/SPREAD_FACTOR/CODING_RATE`.
- **Channel name** is **locked to the preset name** (greyed) while the Channel key
  is the default. It auto-updates when you change the preset. The hint reminds you:
  *if you enter a custom PSK, the Channel name must exactly match the private channel
  you are joining.*
- **Channel key** defaults to **`AQ==`** (the LongFast public PSK; blank works too).
  **Entering a custom PSK unlocks the Channel name** so you can name your private channel.
- **Bandwidth / SF / CR** are shown **read-only** ("set by the modem preset above");
  to use a non-standard plan, use the **Custom** protocol instead.
- **Frequency** shows a `computed:` hint — the Meshtastic channel-slot frequency
  derived from region + preset; editable if you need to override it.

### 4.3 MeshCore

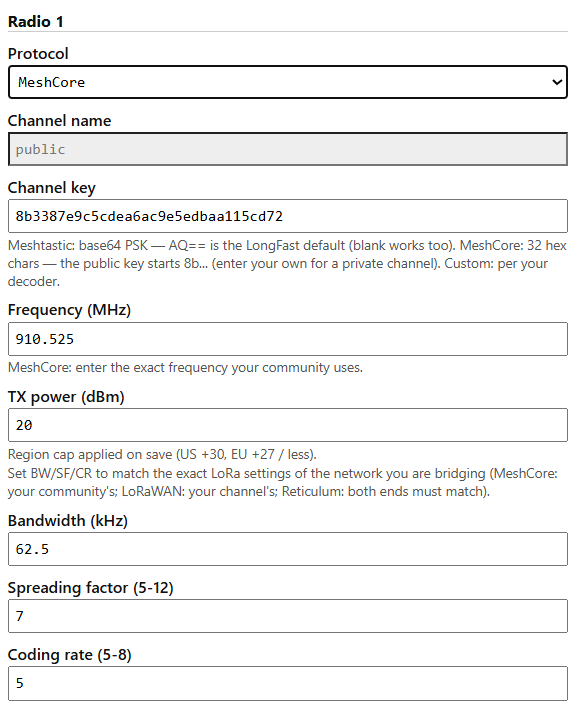
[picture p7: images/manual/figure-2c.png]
Figure 2c — Radio set to MeshCore


- **Channel name** is **locked to `public`** (greyed) while the Channel key is the
  default MeshCore public key. Entering a different key unlocks it for a private channel.
- **Channel key** is **32 hex characters**. The public key starts `8b…`; enter your
  own for a private channel.
- **Frequency** and **Bandwidth/SF/CR** are **fully editable** — MeshCore has no
  universal preset, so set them to exactly match your community's RF plan.

### 4.4 LoRaWAN

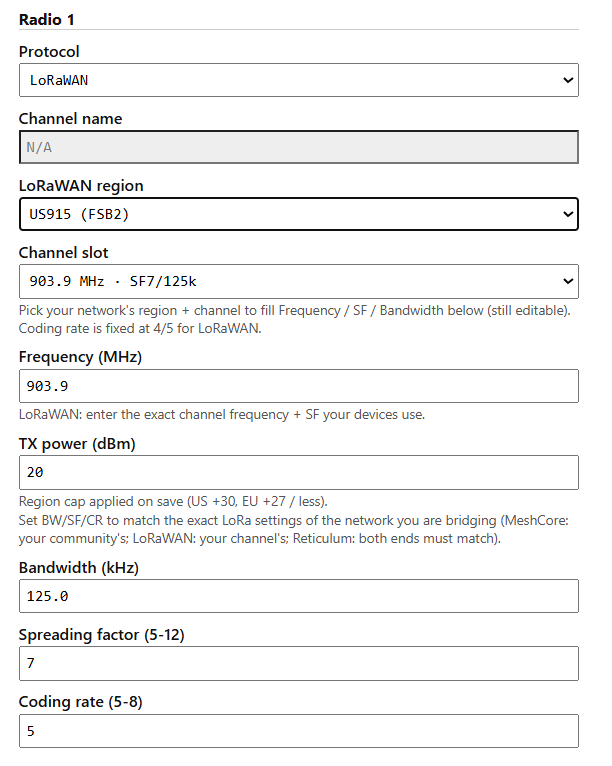
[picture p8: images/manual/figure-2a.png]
Figure 2a — Radio set to LoRaWAN


- **Channel name** is **`N/A`** (LoRaWAN has no named channel).
- **LoRaWAN region** *(LoRaWAN only)* — `US915 (FSB2)`, `AU915 (FSB2)`, `AS923`, or
  `EU868`. Aligns with ChirpStack regions. **Persisted** with the radio. *Portal-only*
  (no build flag).
- **Channel slot** *(LoRaWAN only)* — the default uplink channels for the chosen
  region. Picking a region + slot **auto-fills Frequency / SF / Bandwidth** below
  (all still editable). **Coding rate is fixed at 4/5** for LoRaWAN. *Portal-only.*
- **Frequency / Bandwidth / SF** are editable — set them to the exact channel + data
  rate your LoRaWAN network uses.

> This is the **keyless** LoRaWAN setting for the *radio*. To actually **transmit**
> LoRaWAN (encode mesh/Custom traffic as ABP uplinks) you also configure an identity
> in [§5, LoRaWAN ABP devices](#5-lorawan-abp-devices).

### 4.5 Reticulum

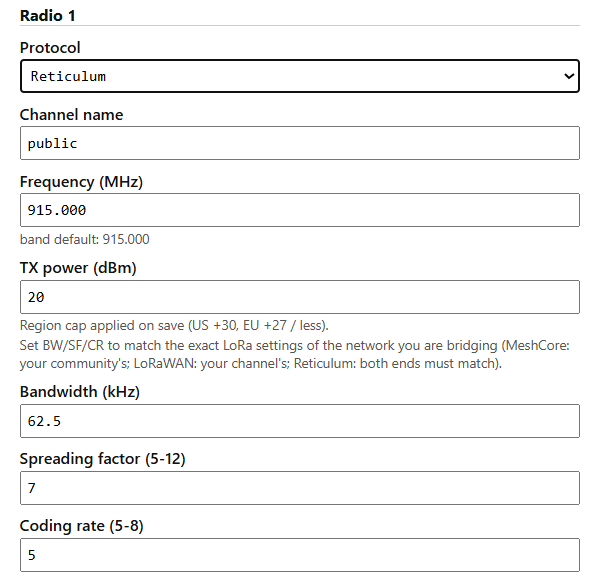
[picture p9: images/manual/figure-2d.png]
Figure 2d — Radio set to Reticulum


- **Channel name** is a free label (Reticulum has no channel key).
- Selecting Reticulum **auto-fills the RNode defaults** — **914.875 MHz / 125 kHz / SF8 /
  CR5**; **Frequency, Bandwidth, SF and CR** are all editable. **Both Reticulum endpoints
  must use the same plan** for the byte-for-byte repeat to work.

### 4.6 Custom

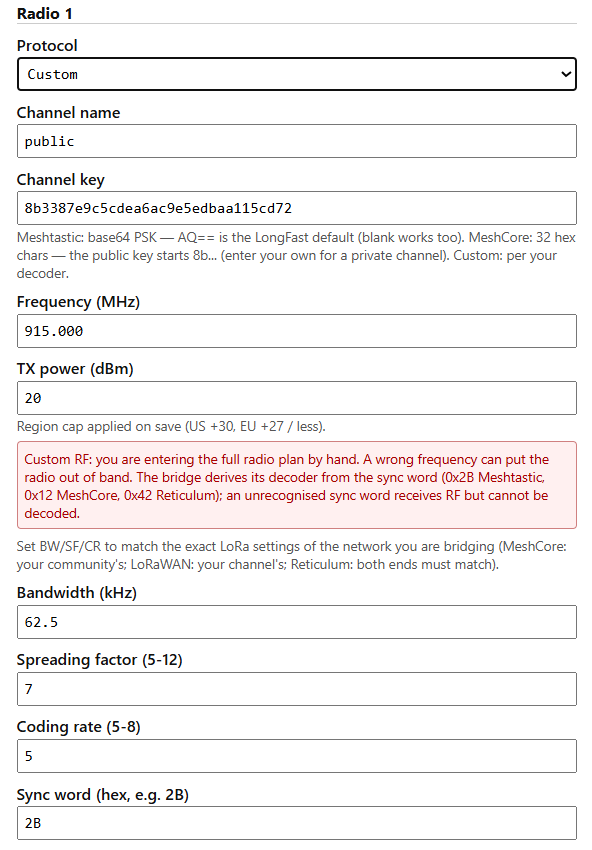
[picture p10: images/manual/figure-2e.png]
Figure 2e — Radio set to Custom


- You enter the **entire RF plan by hand**, including the **Sync word** — the bridge
  derives its decoder from the sync word (`0x2B` Meshtastic, `0x12` MeshCore, `0x42`
  Reticulum, `0x34` LoRaWAN). An unrecognised sync word still receives RF but cannot
  be decoded (a red warning explains this).
- All of Channel name, Channel key, Frequency, TX power, Bandwidth/SF/CR and Sync
  word are editable.

### 4.7 None

Figure 2f — Radio disabled

- **`None (disable radio)`** turns the radio off (single-radio / monitor mode). No
  other fields are shown. At least one radio must be active.

### 4.8 Radio 3 & Radio 4 (the second XIAO)

Radio 3 and Radio 4 are the two SX1262 radios on an **optional second Xiao** wired as a
**radio co-processor**. The main (host) Xiao runs the whole bridge — routing, dedup, this
portal, and the config for *all four* radios — and drives Radio 3 / Radio 4 over a **UART
crossover link** to the co-processor. The second Xiao has no portal of its own; you
configure R3/R4 here, on the host.

- **Same fields as Radio 1 / Radio 2.** Protocol, Channel name/key, Frequency, TX power,
  Bandwidth/SF/CR and Sync word behave exactly as in [§4.1](#41-fields-common-to-every-radio)
  and the per-protocol sections above — being remote changes nothing about how you fill them.
- **The "second XIAO" hint.** In the portal the Radio 3 / Radio 4 headings carry a reminder
  that they live on the second Xiao, reached over the UART crossover link.
- **Default = `None`.** Out of the box both R3/R4 are **`None (disable radio)`**, so a lone
  host Xiao never opens the UART link and behaves as the classic 2-radio bridge. Set a
  protocol on R3 and/or R4 only when the co-processor board is attached.
- **Wiring + flashing.** Both boards' UART1 — **D6 (TX) ↔ D7 (RX)**, wired **crossed**
  (host D6 → co-proc D7, host D7 → co-proc D6, GND ↔ GND) at **460800 baud**. Flash the
  co-processor firmware from [`coproc-xiao-sx1262/`](coproc-xiao-sx1262/) (env
  `xiao_coproc_sx1262` or `…_v1_1`). See the
  [README](README.md#four-radios--two-xiao-boards-optional) for the full wiring + flashing steps.

> **Reboot the host after resetting the co-processor.** The host pushes the R3/R4 config on
> link-up and re-sends it automatically when it sees the co-processor come back.

**Compile-time defaults** (per radio `N` = 3 or 4; mirror the R1/R2 flags in
[§8](#8-preloading-with-compile-time-build-flags)):

| Build flag | What it is |
|---|---|
| `LORA_RADIO N _ENABLE` | Promotes the slot off `None` at first boot (otherwise R3/R4 default to `None`). |
| `LORA_RADIO N _FREQUENCY` / `_BANDWIDTH` / `_SPREAD_FACTOR` / `_CODING_RATE` / `_TX_POWER` / `_SYNC_WORD` | Same RF fields as R1/R2 ([§4.1](#41-fields-common-to-every-radio)). |
| `LORA_RADIO N _CHANNEL_NAME` / `_CHANNEL_KEY` | Per-radio channel preload (same as R1/R2). |
| `LORA_RADIO N _ROUTE_MASK` | Pre-seed this radio's routing-matrix row (see [§4.9](#49-routing-matrix--bridge-received-traffic-to)). |
| `BRIDGE_LINK_TX_PIN` (43 = D6) / `BRIDGE_LINK_RX_PIN` (44 = D7) / `BRIDGE_LINK_BAUD` (460800) | The host↔co-processor UART crossover link; change only if you re-pin the cable. |

### 4.9 Routing matrix — "Bridge received traffic to"

Each radio has a **"Bridge received traffic to"** row: one checkbox per *other* radio.
Ticking a box means *traffic this radio receives is forwarded out that radio* (with
cross-protocol translation applied automatically per destination). This is the **per-radio
routing matrix** — you decide exactly which radios feed which.

- Each radio shows checkboxes for every radio **except itself** (a radio never bridges to
  itself). With four radios active you get up to three checkboxes per radio.
- **Cross-protocol translation is automatic** — if R1 is Meshtastic and you tick R2
  (MeshCore), MT → MC translation happens on that hop. Loops are dropped by the content-hash
  dedup, so it is safe to tick generously.
- **Default = the classic R1 ↔ R2 crossover.** On a fresh board R1 bridges to R2 and R2 to
  R1; R3/R4 bridge to nothing (they are `None`). So the default 2-radio bridge routes exactly
  as it always did.

| You want | Set the checkboxes |
|---|---|
| Classic 2-radio bridge (default) | R1 → R2, R2 → R1; R3/R4 = `None`. |
| Full 4-radio mesh | On each radio, tick all three other radios. |
| Two independent pairs | R1 ↔ R2 only, and R3 ↔ R4 only. |
| One-way feed (monitor R3 onto the R1 mesh) | Tick **R1** on Radio 3; don't tick R3 on Radio 1. |

> **Same-channel guard:** if a *routed* pair would put two Meshtastic (or two MeshCore)
> radios on the identical channel + frequency, Save rejects it — give them different
> frequencies or don't route between them.

---

## 5. LoRaWAN ABP devices

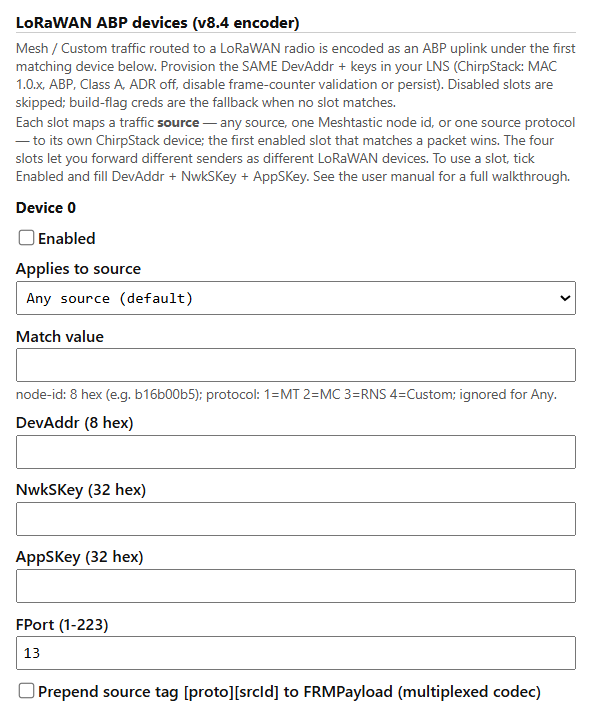
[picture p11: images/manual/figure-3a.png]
Figure 3a — LoRaWAN ABP device slot


This section only appears in encoder-enabled builds (the standard build, as of v8.4).
It defines **how mesh / Custom traffic routed to a LoRaWAN radio is turned into a
valid LoRaWAN uplink**. Each uplink is sent under a bridge-held **ABP identity**;
provision the *same* DevAddr + keys in your LNS (ChirpStack: **MAC 1.0.x, ABP, Class
A, ADR off, frame-counter validation disabled or persisted**).

There are **four device slots** so you can forward different senders as different
ChirpStack devices. **The first *enabled* slot that matches a packet wins**; if none
match, the build-flag fallback credentials are used (`BRIDGE_LW_ENC_*`, below).

### Per-slot fields

| Field | What it is |
|---|---|
| **Enabled** | Turns this slot on. The minimum to use a slot is: tick **Enabled** and fill **DevAddr + NwkSKey + AppSKey**. |
| **Applies to source** | *Which incoming traffic this identity encodes* — see below. |
| **Match value** | The value the selector matches against (a node id or a protocol number); **ignored for "Any source."** |
| **DevAddr (8 hex)** | The ABP device address. Must match the device you create in ChirpStack. |
| **NwkSKey (32 hex)** | Network session key — computes the MIC. |
| **AppSKey (32 hex)** | Application session key — encrypts the payload (FRMPayload). |
| **FPort (1–223)** | The LoRaWAN port the uplink is sent on (default **13**). Useful to route different payload types in your codec. |
| **Prepend source tag** | Multiplexing option — see below. |

### "Applies to source" (the slot's matching rule)

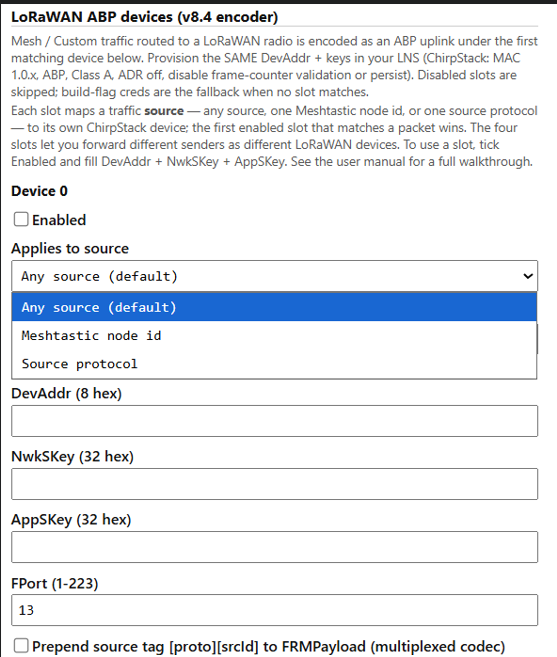
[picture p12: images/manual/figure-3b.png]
Figure 3b — the "Applies to source" options


This dropdown decides which packets a slot claims:

- **Any source (default)** — a catch-all. Any packet routed to the LoRaWAN radio that
  doesn't match a more specific slot is encoded with this identity. **Match value is
  ignored.** Use one "Any source" slot as your default device.
- **Meshtastic node id** — only packets from **one specific Meshtastic node**. Put that
  node's **8-hex node id** (e.g. `b16b00b5`) in **Match value**. Lets you give a single
  important MT node its own ChirpStack device/DevAddr.
- **Source protocol** — only packets from **one whole protocol**. Put the protocol
  number in **Match value**: **1 = Meshtastic, 2 = MeshCore, 3 = Reticulum, 4 = Custom.**
  Lets you, say, send all MeshCore traffic to one device and all Meshtastic to another.

**Resolution order:** an exact *Meshtastic node id* match is preferred, then a *Source
protocol* match, then the *Any source* default. So you can have a specific slot for one
node and a broad slot for everything else, and each packet lands on the most specific
enabled slot.

### "Prepend source tag [proto][srcId] to FRMPayload"

By default (off), **the source's identity is the DevAddr itself** — one bridge source =
one ChirpStack device. That is the simplest, cleanest setup.

Turn this **on** only when you want **one ChirpStack device (one DevAddr) to carry many
different bridge sources** (a "multiplexed" device). The bridge then prepends a **5-byte
tag** to every payload:

```
FRMPayload = [proto:1][srcId:4 bytes little-endian][ actual payload … ]
   proto  = 1 MT · 2 MC · 3 RNS · 4 Custom · 5 LoRaWAN
   srcId  = the source node id / hash
```

Your ChirpStack **JavaScript codec** ([`tools/chirpstack-codec.js`](tools/chirpstack-codec.js))
splits that tag back out into `data.source`. Enable the codec's tag handling by setting
the ChirpStack device **variable** `source_tag = true` for that device (so one pasted
codec serves both tagged and untagged devices). See
[`tools/chirpstack/README.md`](tools/chirpstack/README.md) and the importable
**device-profile templates** there.

### Build-flag fallback (single identity, no portal)

| Build flag | What it is |
|---|---|
| `BRIDGE_LW_ENCODE` | Compiles the ABP encoder in (**1** in the standard build). |
| `BRIDGE_LW_ENC_DEVADDR` | Fallback ABP DevAddr (default `0x01000001` — NwkID 0, matches ChirpStack's default NetID). |
| `BRIDGE_LW_ENC_NWKSKEY` / `BRIDGE_LW_ENC_APPSKEY` | Fallback 32-hex session keys (encoder stays idle until both parse). |
| `BRIDGE_LW_ENC_FPORT` | Fallback FPort (default 13). |
| `BRIDGE_LW_ENC_SELFTEST` | Run boot-time crypto known-answer self-tests → `[lw-selftest] … PASS`. |

These are used only when **no portal slot matches**, so a build with no portal devices
still emits under one identity.

### Enabling, provisioning & end-to-end flow

Emitting valid LoRaWAN is **keyed**. As of v8.4 the encoder **ships in the standard
`xiao_esp32s3` / `xiao_esp32s3_v1_1` build** — it stays **dormant** until you set a radio
to LoRaWAN *and* configure an ABP device above, so a stock MT/MC bridge is behaviourally
unchanged. No special env is needed (the `xiao_esp32s3_lwabp` env just adds the boot
self-test).

End to end:

1. Set a radio's protocol to **LoRaWAN** ([§4.4](#44-lorawan)) and configure an ABP device
   above (or the `BRIDGE_LW_ENC_*` build-flag fallback).
2. Provision the **same** DevAddr + NwkSKey + AppSKey in ChirpStack (**MAC 1.0.x, ABP,
   Class A, ADR off**), and paste [`tools/chirpstack-codec.js`](tools/chirpstack-codec.js)
   into the device profile's Codec tab — or import the ready-made templates in
   [`tools/chirpstack/`](tools/chirpstack/README.md).
3. The `0x34` radio then re-emits your decoded mesh (MT/MC) — or a **Custom** raw-LoRa
   station's raw bytes — as ABP uplinks for an in-range gateway to forward to ChirpStack.

**Status:** the encoder is **hardware-verified on air** (MT *and* MC → valid ABP uplinks,
decrypt + MIC checked — [`BENCH-RESULTS.md`](BENCH-RESULTS.md)); **live-ChirpStack ingestion
is the one remaining bench item** ([`BENCH-v8.4.md`](BENCH-v8.4.md)). Full design:
[`ABP-LORAWAN-SPEC.md`](ABP-LORAWAN-SPEC.md).

---

## 6. Saving

Figure 4 — Save & reboot

**Save & reboot** writes the config to NVS and restarts the bridge into normal
operation. Watch it come up over USB serial:

```bash
pio device monitor --port COMx
```

To change anything later, re-enter the portal ([§1](#1-reaching-the-config-portal)).

---

## 7. Example setups

Four common bridges. Set the radios as shown, then **Save & reboot**. Each can also be
**preloaded at compile time** — see [§8](#8-preloading-with-compile-time-build-flags).

### A. Meshtastic ↔ MeshCore  *(the shipped default)*

| | Radio 1 | Radio 2 |
|---|---|---|
| Protocol | Meshtastic | MeshCore |
| Modem preset / channel | LongFast | `public` |
| Channel key | `AQ==` | `8b3387…cd72` (public) |
| Frequency | 906.875 | 910.525 |
| BW / SF / CR | 250 / 11 / 5 (from preset) | 62.5 / 7 / 5 |

Bridges the Meshtastic LongFast mesh to the MeshCore public channel.

### B. Meshtastic → LoRaWAN (ABP uplink to ChirpStack)

| | Radio 1 | Radio 2 |
|---|---|---|
| Protocol | Meshtastic | LoRaWAN |
| LoRaWAN region / slot | — | US915 (FSB2) / 903.9 MHz · SF7/125k |
| Frequency | 906.875 | 903.9 |
| BW / SF / CR | 250 / 11 / 5 | 125 / 7 / 5 (CR fixed 4/5) |

Then add a **LoRaWAN ABP device** ([§5](#5-lorawan-abp-devices)) — Enabled, *Any
source*, your DevAddr + NwkSKey + AppSKey, FPort 13 — and provision the matching
device in ChirpStack. Meshtastic traffic is re-emitted as ABP uplinks a gateway
forwards to ChirpStack.

### C. Meshtastic public → Meshtastic private channel

| | Radio 1 | Radio 2 |
|---|---|---|
| Protocol | Meshtastic | Meshtastic |
| Channel name | `LongFast` (public) | *your private channel name* |
| Channel key | `AQ==` | *your private base64 PSK* |
| Frequency | 906.875 | **914.875** (must differ from R1) |
| BW / SF / CR | 250 / 11 / 5 | 250 / 11 / 5 |

Bridges a public Meshtastic channel to a private one. The two radios must be on
**different frequencies** (bridging the *same* channel + frequency to itself is
rejected). Enter the private channel's name + PSK on Radio 2 (entering a custom PSK
unlocks the Channel name field).

### D. Four-radio bridge (second XIAO)  *(v9.0)*

Attach a second Xiao as the radio co-processor ([§4.8](#48-radio-3--radio-4-the-second-xiao)),
then configure all four radios — for example R1 Meshtastic, R2 MeshCore, R3 Reticulum,
R4 LoRaWAN.

| | Radio 1 | Radio 2 | Radio 3 (2nd Xiao) | Radio 4 (2nd Xiao) |
|---|---|---|---|---|
| Protocol | Meshtastic | MeshCore | Reticulum | LoRaWAN |
| Bridge received traffic to | R2, R3, R4 | R1, R3, R4 | R1, R2 | R1, R2 |

Use the **routing matrix** ([§4.9](#49-routing-matrix--bridge-received-traffic-to)) to pick
which radios feed which — the table above is a full 4-way mesh; tick fewer boxes for
independent pairs or one-way feeds. **Leaving R3/R4 = `None` gives you example A again**
(the classic 2-radio bridge), no second Xiao required.

---

## 8. Preloading with compile-time build flags

If you build from source you can bake any of the above into the firmware so a fresh
board boots already configured (handy for flashing several identical bridges). Open
[`platformio.ini`](platformio.ini) and find the **"v8.4.1 — PER-RADIO CHANNEL
OVERRIDES + READY-MADE SCENARIO SETUPS"** block. It contains the three scenarios
above as commented `-D` blocks.

- **Scenario A** is the active default — nothing to do.
- For **Scenario B** or **C**: comment out the active *Radio 1/2 settings* block and
  uncomment the scenario block, then `pio run -e xiao_esp32s3` (or `…_v1_1`).
- For **Scenario D (4-radio)**: uncomment the **"v9.0 — READY-MADE 4-RADIO (DUAL-XIAO)
  SCENARIO"** block higher up in `platformio.ini` to enable + route R3/R4, then flash the
  second Xiao with the co-processor env (see [§4.8](#48-radio-3--radio-4-the-second-xiao)).
- **Per-radio channels:** `LORA_RADIO1_CHANNEL_NAME` / `LORA_RADIO1_CHANNEL_KEY` and
  the Radio 2 equivalents let each radio preload a *distinct* channel (needed for
  Scenario C, where both radios are Meshtastic on different channels).

> The build flags are **first-boot defaults only**. They apply when NVS is empty, so
> after changing them **erase the device** (`pio run -t erase -t upload`) to see the
> new defaults; otherwise the saved NVS config wins. You can always override any of
> them in the captive portal at runtime.

---

## 9. Other build flags (reference)

All optional, set in [`platformio.ini`](platformio.ini); the compiled-in default is
shown in parentheses. These are global tunables and behaviour toggles beyond the
per-field flags named in the sections above.

**Global radio**
- `LORA_PREAMBLE_LEN` (8) — LoRa preamble symbol count (all radios).
- `LORA_CRC` (1) — enable the LoRa hardware CRC.
- `LORA_TCXO_VOLTAGE` (1.8f) — TCXO control voltage.
- `LORA_MAX_PACKET` (256) — max LoRa packet buffer, bytes.

**Loop / duplicate guard**
- `BRIDGE_DEDUP_TTL_MS` (60000) — how long a seen *(body + sender id + packet_id)* hash blocks duplicates.
- `BRIDGE_DEDUP_TABLE_SIZE` (512) — recent-hash table entries.

**Outbound route queue (PSRAM-backed)**
- `BRIDGE_ROUTE_QUEUE_DEPTH` (64) — packets buffered per destination radio.
- `BRIDGE_ROUTE_MAX_AGE_MS` (30000) — drop a queued packet older than this.

**TX scheduler (CAD / CSMA / airtime throttle)**
- `BRIDGE_CAD_BACKOFF_MIN_MS` (20) / `BRIDGE_CAD_BACKOFF_MAX_MS` (120) — random CSMA backoff window after a busy CAD.
- `BRIDGE_TX_INFLIGHT_TIMEOUT_MS` (10000) — force-recover a non-blocking TX that never reports done.
- `BRIDGE_TX_DUTY_PERCENT` (50) — max self-TX duty cycle; `0` = no duty cap (min-gap only).
- `BRIDGE_TX_MIN_GAP_MS` (0) — absolute floor on the post-TX off-air gap.

**Source-identity preservation**
- `BRIDGE_IDENTITY_PRESERVE` (1) — `0` = clean-body / bridge-identity behaviour.
- `BRIDGE_TAG_ORIGIN_PROTO` (1) — `1` = `Alice@MT:` / `Alice @MC`; `0` = bare native-looking names.
- `BRIDGE_MC_NONAME_VIRTUAL` (0) — MeshCore body with no `name:` prefix: `0` = bridge id, `1` = per-channel virtual node.
- `BRIDGE_MC_NAME_MAX` (32) — longest MeshCore sender name parsed from a body prefix.
- `BRIDGE_VIRT_NODES_MAX` (32) — virtual-node LRU size.
- `BRIDGE_VIRT_NODEINFO_PERIOD_MS` (900000) — minimum interval between a virtual node's NodeInfo re-advertisements.

**Reticulum**
- `BRIDGE_RNS_MAX_FRAGS` (8) — max MT/MC fragments per tunneled RNS frame.
- `BRIDGE_RNS_INPROTO_REPEAT` (1) — transparent RNS↔RNS raw repeat when both radios are Reticulum; `0` = tunnel-only.

**LoRaWAN keyless tap** (separate from the keyed ABP encoder in [§5](#5-lorawan-abp-devices))
- `BRIDGE_LW_CAPTURE` (1) — log `evt=RX proto=LW` header metadata.
- `BRIDGE_LW_SUMMARY_TO_MESH` (1) — emit a one-line LoRaWAN metadata summary into the MT/MC mesh.
- `BRIDGE_LW_RELAY` (1) — transparent raw repeat between two LoRaWAN radios.

**Build-time validation** *(automatic — no flag to set)* — `src/LoraConfigCheck.h` rejects an
invalid `LORA_RADIO*` set at compile time (`#error` / `static_assert` on sync word, SF/CR/BW/region
sanity, and TX-power range).

**Bench only**
- `BRIDGE_BENCH_AUTOSAVE` — makes an erased board boot pre-configured and skip the captive portal.
  **Never enable this in a release build.**

---

## 10. LoRaCam — camera setup, pairing & the web portal

**LoRaCam** is the same bridge firmware built as a **LoRa-commanded camera**: a Seeed
XIAO ESP32-S3 **Sense** (OV2640 camera + mic + microSD on its rear B2B daughterboard)
plus **one** Wio-SX1262 "for XIAO" **edge** radio hand-wired to the XIAO's edge pins.
Because the Sense camera board occupies the underside B2B connector, **Radio 1 is
disabled** (its GPIO38–42 pins are the camera/mic bus) and the camera build uses only
the single **edge radio (Radio 2)**. Wiring is in the [README](README.md#loracam--lora-commanded-camera)
(the nine flying leads follow the same **R2 V1.0 pin map** as the bridge's edge radio,
just soldered instead of stacked); this section covers the camera's **web portal and
its LoRa command channel** only.

Everything the bridge portal does — the radio/identity form in [§3](#3-top-frame--identity-region--bridge-behaviour)–[§4](#4-per-radio-configuration) — is still here,
reached from the camera portal's **Config** tab. What is new is an **always-on secure
portal** with live video, on-SD photos/videos, operator messaging, and a
trusted-commander whitelist.

> All camera code is gated behind `-DBRIDGE_ROLE_CAMERA`, so the stock bridge builds
> ([`xiao_esp32s3`](platformio.ini)) stay byte-identical — the camera is a build of the
> same firmware, not a fork.

### 10.1 Two ways to run a LoRaCam

| Mode | What talks to the camera | When to use it |
|---|---|---|
| **Standalone** | The camera's **own WPA2 web portal** — view live video, snap/record, browse the SD card, change config. No second device. | You (or a phone/laptop) are within WiFi range of the camera. |
| **Paired** | A LoRa **commander** (any spare XIAO + Wio-SX1262 on the same `0x33` channel) sends **signed** commands over LoRa. | The camera is out of WiFi range; you command it over the mesh instead. |

The two modes coexist — a paired camera still runs its portal. **Multi-hop** ([§10.8](#108-multi-hop--commander--repeater--camera)) extends *paired* mode through a repeater when the commander can't hear the camera directly.

### 10.2 Reaching the LoRaCam portal

A camera build boots **straight into its always-on portal** (unlike the bridge's
one-shot captive portal in [§1](#1-reaching-the-config-portal) — the camera portal is
always up, and it is **WPA2-secured**, not open).

1. Join the WiFi network **`LoRaCam-XX`** (`XX` = the low byte of the node ID, unique
   per board) with the WPA2 passphrase **`loracam-portal`**.
2. Browse to **`http://192.168.4.1`**. Any request is redirected to the portal (captive).
3. Log in — default **`admin` / `loracam-admin`**.

> **⚠ Change both defaults on first login.** The WPA2 passphrase and the portal login
> are set on the **Security** tab ([§10.6](#106-security-tab--change-the-wpa2-passphrase--login)).
> The build-flag defaults are `BRIDGE_PORTAL_AP_PASS` (WiFi), `BRIDGE_PORTAL_USER` /
> `BRIDGE_PORTAL_PASS` (login) — see [§8](#8-preloading-with-compile-time-build-flags)
> for how build flags seed first-boot values. First-flash is secure by design: an
> unconfigured camera comes up on the **WPA2 + login** portal, never an open AP.

The portal has five tabs: **Home · Photos · Config · Pairing · Security**.

### 10.3 Home tab — live video, capture & messaging

| Control | What it does |
|---|---|
| **Live video** | A live **MJPEG** stream from the OV2640 (served on port `:81`; the page embeds it as an `<img>`). |
| **Snap** | Takes a single **800×600 JPEG**, saved to microSD as `/loracam/IMG_%05u.jpg`. |
| **Record** | Records **MJPEG-AVI** video (~5 fps) to `/loracam/VID_%05u.avi` (plays in VLC). |
| **Stop** | Ends an in-progress recording early. |
| **Status** | Shows camera/SD state (SD free %, ready state) — the same status the LoRa `get-status` command returns. |
| **Messaging** | Send/receive short operator text messages to a paired commander (see the `T_MSG` note in [§10.7](#107-pairing-tab--trust-a-commander)). |

Snap works **during** a live stream (the camera serializes stream frames and captures
through a mutex). File numbering is **reboot-safe** (it resumes from the highest
existing file) so power-cycling never overwrites a shot.

### 10.4 Photos tab — browse the SD card

Lists everything under **`/loracam/`** newest-first — photos (`IMG_*.jpg`) **and** videos (`VID_*.avi`):

- **View** a photo inline, or **download** either media type.
- **Delete** a file (with a confirm).

Downloads carry a one-time token so the browser's file-download handoff can't lose your
login session. If there is **no microSD card**, snap/record still return a live JPEG
over LoRa/stream but nothing is written and the Photos list is empty.

### 10.5 Config tab — the radio & identity form

The Config tab is the **same captive-portal form** documented in
[§3](#3-top-frame--identity-region--bridge-behaviour)–[§4](#4-per-radio-configuration),
served verbatim inside the portal (one source of truth — nothing to re-learn). Use it to
set the camera's identity, region, and the **edge radio (Radio 2)** RF plan.

- **Radio 1 is fixed to `None`** on a camera build (its pins are the camera bus) — leave
  it disabled; a save re-forces it off automatically. Configure only **Radio 2**.
- The camera's C2 command channel rides a **Custom** radio on sync word **`0x33`** (see
  [§4.6, Custom](#46-custom)); leave Radio 2 on that plan unless you know why you're changing it.
- **Saving reboots**, exactly as in [§6](#6-saving) — radios initialise once at boot.

### 10.6 Security tab — change the WPA2 passphrase & login

Two independent secrets, both changed here:

| Field | What it protects |
|---|---|
| **WiFi passphrase** | The WPA2 AP (`LoRaCam-XX`). |
| **Portal login** | The `admin` username/password gate on the portal itself. |

Both are stored **hashed** in the camera's own `camportal` NVS namespace (a salted
SHA-256 for the login) — this is separate from the radio config, so changing them does
**not** disturb your saved radio/identity settings. **Saving here reboots the portal.**

> There is **no open-AP password recovery** — a lost portal password is recovered by
> **re-flashing** (by design). Note `pio run -t erase` wipes the whole flash including
> the app; always follow it with `-t upload`.

### 10.7 Pairing tab — trust a commander

Pairing is how *standalone* becomes *paired*. It manages the **trusted-commander
whitelist** (the `c2auth` list) — the set of LoRa senders the camera will accept
commands from.

**To pair a commander:**

| Field | Value |
|---|---|
| **C2 id** | The commander's **8-hex** identity (e.g. `0000c0de`). |
| **PSK** | The shared **32-hex** pre-shared key. |
| **Primary** | Tick to mark this the primary commander. |

Then, on the **commander**, whitelist *this camera* with the **same** 8-hex id (the
camera's) and the **same** 32-hex PSK. The key must match on both ends — it is the
shared secret for the encrypted link.

**How the LoRa command channel is secured** (high level — full design in
[`LORACAM-SPEC.md`](LORACAM-SPEC.md)):

- **Encrypted, then authenticated.** Each C2 frame is AES-CTR encrypted and carries an
  8-byte **AES-CMAC** tag; keys are derived from the per-peer PSK. A frame that fails the
  MAC is dropped before it is acted on (encrypt-then-MAC, constant-time compare).
- **Sender-whitelisted.** Only ids on the `c2auth` list are accepted; an unknown sender
  is refused (`reason=not-whitelisted`).
- **Replay-protected.** A monotonic per-peer sequence counter, persisted across reboots,
  rejects replayed or stale frames.

Commands available over this channel: **snap photo, record video, stop, get status**,
plus operator **text messaging** (the `T_MSG` frame surfaced on the Home tab).

> **Bench builds** seed a pairing for you so you can test two boards without the portal:
> `bench_camc2` (camera, id `0xCA00`, peer `0xC0DE`) and `bench_camc2_cmdr` (commander,
> id `0xC0DE`, peer `0xCA00`). In the **commander's** serial monitor:
> `s`=snap · `r`=record 30 s · `x`=stop · `g`=get-status · `m`=send a message. The
> provisioning flags are `BRIDGE_C2_MY_ID` / `BRIDGE_C2_PEER_ID` / `BRIDGE_C2_PEER_KEY` /
> `BRIDGE_C2_PEER_PRIMARY` (see [§8](#8-preloading-with-compile-time-build-flags)).

### 10.8 Multi-hop — commander → repeater → camera

When the commander can't hear the camera directly, put a **repeater** between them: a
plain bridge that **raw-repeats** the Custom `0x33` C2 frames so
`commander → repeater → camera` works, ACKs included. This is a flag-gated feature —
build the repeater with **`-DBRIDGE_CUSTOM_REPEAT`** (off by default, so stock bridge
builds stay byte-identical).

- The repeater is a normal 2-radio bridge on channel `loracam`, both radios **Custom,
  sync `0x33`**, routed `R1 ↔ R2` ([§4.6](#46-custom), [§4.9](#49-routing-matrix--bridge-received-traffic-to)) — typically on **different frequencies** on each side so the hops don't collide.
- No key is configured on the repeater — it forwards the **encrypted** C2 bytes
  verbatim; only the camera and its paired commander hold the PSK.
- Ready-made bench envs: **`bench_repeater_custom`** (the repeater, R1 `0x33`@905 ↔ R2
  `0x33`@906.875) and **`bench_camc2_cmdr_905`** (the commander moved to 905 MHz for a
  frequency-split test proving the camera is reachable *only* via the repeater).

---

*This manual covers firmware v10.0 (LoRaCam camera + the v9.0 four-radio bridge). For protocol/routing internals see
[README.md](README.md#routing--protocol-support-current-functionality); for the
LoRaWAN ABP encoder design see [ABP-LORAWAN-SPEC.md](ABP-LORAWAN-SPEC.md); for
ChirpStack integration see [tools/chirpstack/README.md](tools/chirpstack/README.md).*

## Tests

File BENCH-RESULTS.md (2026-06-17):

# v8.4 ABP encoder — bench results & status

**Date:** 2026-06-16 · **Branch:** `dev-ABP-lorawan` · **Firmware under test:** `bench_lw_enc` /
`bench_lw_enc_dwell` / `bench_lw_sniffer` / `xiao_esp32s3_lwabp` (portal) / `xiao_esp32s3` (commits up
to `b31527a`; code unchanged since `bbdc7d6` — intervening commits are docs only).
**Rig:** DUT-A = COM13 (sender), SNIFFER = COM6 (keyless listener / "synthetic LNS"); stimulus =
owner's Meshtastic node `!0AC9F340`. Serial captured from the host over USB.

## Score: 12 PASS · 4 OPEN (0 FAIL)
- **Closed (PASS):** A1, A2, A3, A4, A5, B1, B2, B3, B4, B5, B6, B7 — the full bench-side chain: crypto, on-air emit, decrypt, reboot-safe FCnt, do-no-harm, portal persistence (A4), DevAddr-keyed FCnt across a row move (B3), per-source DevAddr resolution (B4), source-protocol tag MT+MC (B6), MeshCore→ABP (B7), over-cap payload drop (A3).
- **Owner-solo set (WiFi config page): COMPLETE** — A4 / B3 / B4 / B6 / B7 all PASS.
- **A3 (over-cap drop): PASS** — 250 B Custom frame from `tools/lw-frame-gen` (`oversize` env).
- **Open — colleague, ChirpStack LNS:** C1, C2, C3, C4.

## Status matrix

| ID | Test | Status | Result / blocker | Run by |
|----|---|---|---|---|
| **A1** | Crypto self-test (gate) | ✅ PASS | `[lw-selftest] overall : PASS` on COM13 | done |
| **A2** | US915 per-TX dwell cap | ✅ PASS | SF12 frame: `drop=dwell toa=1811 limit=400`, not transmitted | done |
| **A3** | Oversize payload dropped | ✅ PASS | 250 B Custom frame → `drop=lw-payload-overflow len=250 cap=237` (tag-aware cap), not transmitted | done |
| **A4** | Portal saves ABP device | ✅ PASS | reboot reload: `anyConfigured=1`, `dev0 … devaddr=0x01000001 fport=13` persisted; Radio 2 now LoRaWAN | done |
| **A5** | Stock build do-no-harm | ✅ PASS | stock boot: zero `[lw-selftest]`/`[lw-enc]`/`[LoRaWANConfig]` | done |
| **B1** | Message → packet on air | ✅ PASS | MT text → DUT `evt=QUEUE dstproto=LW` → SNIFFER `evt=RX proto=LW` | done |
| **B2** | FCnt monotonic across reboot | ✅ PASS | before reboot `fcnt=33` → after reboot `fcnt=99` (never 0) | done |
| **B3** | DevAddr keeps counter across rows | ✅ PASS | moved slot 0→1: `dev1 … devaddr=0x01000001 fcnt=165` (was 165 at dev0, not reset to 0) | done |
| **B4** | Per-source resolve (node→proto→Any) | ✅ PASS | `0AC9F340`→`devaddr=01000001` (node match), `3D3A87A3`→`01000002` (proto fallback), both `cred=nvs` | done |
| **B5** | MIC + decrypt off-box | ✅ PASS | `lw-verify.py` on captured frame: MIC PASS, decrypts to sent text | done |
| **B6** | Source tag decodes to proto | ✅ PASS | tagged frames decrypt to `proto=1(meshtastic)` and `proto=2(meshcore)`, all MIC-valid | done |
| **B7** | MeshCore source → ABP | ✅ PASS | MC text on R1 → ABP uplink `devaddr=01000001`, decrypts to MC body, MIC PASS | done |
| **C1** | Uplink ingested by ChirpStack | ⬜ OPEN | needs ChirpStack LNS + gateway | colleague |
| **C2** | Custom/weather → ChirpStack | ⬜ OPEN | needs ChirpStack LNS + Custom source | colleague |
| **C3** | Codec decodes source tag | ⬜ OPEN | needs ChirpStack LNS | colleague |
| **C4** | LNS accepts ↑FCnt, rejects replay | ⬜ OPEN | needs ChirpStack LNS | colleague |

## Evidence (verbatim serial / tool output)

**A1 — self-test (COM13, `bench_lw_enc`):**
```
[lw-selftest] RFC4493 CMAC len= 0 : PASS   (×4: len 0/16/40/64)
[lw-selftest] FRMPayload A_1 keystream : PASS
[lw-selftest] frame assembly + round-trip : PASS
[lw-selftest] overall : PASS
```

**A2 — dwell cap (COM13, `bench_lw_enc_dwell`, SF12):**
```
evt=QUEUE radio=R1 dst=R2 dstproto=LW len=34 devaddr=01000001 fcnt=33 fport=13 cred=flag
evt=DROP  radio=R2 drop=dwell toa=1811 limit=400 len=34      <- 1811 ms > 400 ms, NOT sent
```

**A3 — over-cap payload dropped, not truncated (#6) (COM13 DUT + COM14 generator):** R1 set to Custom
(905.0 / BW250 / SF7 / sync 0xAB) to match `tools/lw-frame-gen` `oversize` env, which transmitted a
250 B raw frame (`6` = FRAME-OVERSIZE). The bridge received it and refused to encode an over-cap
FRMPayload:
```
evt=RX   radio=R1 proto=? len=250 rssi=-62 snr=13.5
evt=DROP radio=R1 dst=R2 drop=lw-payload-overflow len=250 cap=237 msg="custom-raw"
```
250 B > the 237 B cap (242 − 5 for the source tag — confirms the tag-aware cap math); dropped cleanly,
no TX. Repeat frames logged `drop=loop-dup` (dedup works on the Custom path too).

**A4 — portal config persists (COM13, `xiao_esp32s3_lwabp`):** owner set Device 0 = DevAddr
`01000001` / Any source / FPort 13 via the WiFi portal and saved; the board rebooted and reloaded the
table from NVS:
```
[LoRaWANConfig] loaded 4 ABP device slots (anyConfigured=1)
[LoRaWANConfig] dev0 sel=0 match=0x00000000 devaddr=0x01000001 fport=13 fcnt=0
[BridgeConfig] v4 configured=1 region=1
  radio2 RF = proto=5 sync=0x34 903.900 MHz BW125.0 SF7
```
Config survived the reboot (NVS-persisted); Radio 2 switched to LoRaWAN.

**A5 — stock do-no-harm (COM13, `xiao_esp32s3`):** boot dump showed
`[BridgeConfig] v4 configured=0 region=0` and `radio2 RF = proto=2 sync=0x12` (MeshCore), with
**no** `[lw-selftest]`, **no** `[lw-enc]`, **no** `[LoRaWANConfig]` lines (encoder compiled out).

**B1 — end-to-end (COM13 sender + COM6 sniffer):** owner sent MT text "Test to claude from Meshtastic".
```
DUT  (COM13): evt=QUEUE radio=R1 dst=R2 dstproto=LW len=43 devaddr=01000001 fcnt=33 fport=13 cred=flag
SNIFF(COM6) : evt=RX proto=LW mtype=UnconfDataUp devaddr=0x01000001 fcnt=33 fport=13 len=43
SNIFF(COM6) : evt=LWRAW len=43 raw=40010000010021000d2350a53dfbbfeb298916c7a0d587055061ac99d1511cee268b2c4e7747fc98030fc7
```

**B2 — FCnt across reboot (COM13):** uplink "Now" → `fcnt=33`; board rebooted; uplink "Hehhehe" →
`fcnt=99`. Counter advanced (33 → 99), never reset to 0 → no replay.

**B3 — DevAddr-keyed FCnt across a portal row move (COM13, `xiao_esp32s3_lwabp`):** the counter for
`01000001` had already advanced to 165 (`dev0 … fcnt=165`). Owner disabled Device 0 and re-added the
**same** DevAddr in Device 1, then saved:
```
[LoRaWANConfig] device table saved (176 B)        <- save accepted
[CaptivePortal] config saved, rebooting...
  ... reboot ...
[LoRaWANConfig] dev1 sel=0 match=0x00000000 devaddr=0x01000001 fport=13 fcnt=165
```
Address moved **slot 0 → slot 1**; counter stayed **165, not reset to 0** — FCnt is keyed by DevAddr
(`fc_<addr>`), not slot index (fix #1). A later clean reboot advanced it 165 → 198 (monotonic, never
replays), re-confirming the move is durable + the reboot-safe counter. *Repro note:* the portal save
is all-or-nothing — a bad field in any enabled row (e.g. a mistyped 32-hex key) makes
`applyLoRaWANDevices()` return early before `saveTable()`, silently keeping the old config. Watch for
the red error banner, or copy-paste the keys to avoid a typo.

**B4 — per-source DevAddr resolution (COM13, `xiao_esp32s3_lwabp`):** two configured devices —
`dev0` = MT-node-id `0ac9f340` → `01000001` (specificity 2), `dev1` = MT-protocol → `01000002`
(specificity 1). Owner sent one MT text from each of two nodes; resolve() chose the DevAddr per sender:
```
src=0x0AC9F340 → evt=QUEUE dstproto=LW devaddr=01000001 fport=13 cred=nvs  msg="Testing Meshtastic"
src=0x3D3A87A3 → evt=QUEUE dstproto=LW devaddr=01000002 fport=13 cred=nvs  msg="testing MT msg meshpoint"
```
Node `0AC9F340` (specific node-id match) won → `01000001`; node `3D3A87A3` (no node match, fell to the
MT-protocol rule) → `01000002`. Both `cred=nvs` = matched the NVS table, not the build-flag fallback —
resolve() priority ladder confirmed (node-id beats protocol).

**B5 — offline MIC + decrypt (host, on the B1 frame):**
```
python tools/lw-verify.py 40010000010021000d2350a53dfbbfeb298916c7a0d587055061ac99d1511cee268b2c4e7747fc98030fc7 <NwkSKey> <AppSKey>
MIC: got 98030fc7  expect 98030fc7  -> PASS
Decrypted as ASCII: 'Test to claude from Meshtastic'
VERDICT: MIC valid — ChirpStack would ACCEPT this frame
```

**B6 — source-protocol tag in FRMPayload (COM6 sniffer + offline `lw-verify.py --tagged`):** Device 0 =
Any source with "Prepend source tag" on. A Meshtastic text and three MeshCore texts were each encoded,
captured, and decrypted with the keys:
```
MT (node 0AC9F340): src tag : proto=1(meshtastic) srcId=0x0AC9F340  payload 'Twstesww'
MC (#330):          src tag : proto=2(meshcore)   srcId=0x00000000  payload '9506C57C: Final test'
MC (#331):          src tag : proto=2(meshcore)                     payload 'Meshpoint - Meshcore: send mc'
```
Every frame MIC-valid. The tag decodes to the correct source protocol both ways (1=MT, 2=MC). MeshCore
carries no on-air numeric node id, so `srcId=0` is expected — its identity rides in the body prefix
(`9506C57C:`).

**B7 — MeshCore source → ABP uplink (COM6 sniffer + decrypt):** R1 set to MeshCore (910.525 / BW62.5 /
SF7, public channel hash 0x11 — matched to the build-flag R2 config). A MeshCore text received on R1 was
encoded to a LoRaWAN ABP uplink on R2, captured, and decrypted to its original body:
```
DUT  (COM13): evt=RX radio=R1 proto=MC → MeshCore GRP_TXT ch=0x11 body "9506C57C: Vgcvv"
              → evt=QUEUE dstproto=LW devaddr=01000001 fcnt=332 fport=13 cred=nvs tag=1
              → evt=TX_START radio=R2 cad=clear → evt=TX_DONE done
SNIFF(COM6): evt=RX proto=LW devaddr=0x01000001 fcnt=330 fport=13
lw-verify  : MIC PASS → '9506C57C: Final test'   (ChirpStack would ACCEPT)
```
The MeshCore body survived the MeshCore→ABP transcode end-to-end. ⚠️ Root cause of a long bench detour:
R1's frequency was hand-entered as `910.575` vs the correct `910.525` (a 50 kHz slip → `rx-error rc=-7`
CRC failures). Triggered by the portal not auto-filling defaults on protocol switch — see the TODO at
`CaptivePortal.cpp` `appendScript()`.

## What "closed" means here
The 12 passes cover the whole signal chain end-to-end **without a LNS**: a real mesh message —
**Meshtastic *and* MeshCore** — is encoded into a valid LoRaWAN 1.0.x uplink, transmitted on air,
captured, and decrypted back to the original text with a valid MIC — plus the dwell cap, reboot-safe
counter, stock do-no-harm, portal persistence (A4), DevAddr-keyed FCnt across a config row move (B3),
per-source DevAddr resolution (B4), source-protocol tagging (B6), the MeshCore→ABP transcode (B7), and
the over-cap payload drop (A3). **The entire owner-solo set (A4 / B3 / B4 / B6 / B7) is PASS, and A3 is
done via the `lw-frame-gen` oversize frame — so the only tests left are Tier C (ChirpStack).** The 4
open items (C1–C4) need the colleague's ChirpStack LNS.

---

## References — test protocols & methods (to repeat or audit this bench)

**Test definitions & pass criteria (what each test does):**
- `BENCH-v8.4.md` — core procedure for A1, A2, A5, B1, B2, B5 (plain steps).
- `BENCH-SOLO.md` — the WiFi-config-page tests A4, B3, B4, B6, B7 (step by step).
- The pass/fail criterion for every test is also the **"Result / blocker" column** in the matrix above.
- `ABP-LORAWAN-SPEC.md` — design of record (frame layout, crypto, FCnt scheme).
- Pre-bench review fixes #1–#6 are summarised in `BENCH-v8.4.md` (commits `d98da4b`, `1496717`, `9aaf423`).

**Firmware under test:** branch `dev-ABP-lorawan`, tip `bbdc7d6`. Build environments are defined in
`platformio.ini`:
- `bench_lw_enc` — sender: R1 Meshtastic 906.875/BW250/SF11, R2 LoRaWAN 903.9/BW125/SF7, REGION=US,
  build-flag ABP creds, autosave (no portal).
- `bench_lw_enc_dwell` — as above but R2 **SF12** (used for A2 dwell).
- `bench_lw_sniffer` — listener: keyless LoRaWAN capture on 903.9/BW125/SF7 with full-frame hex
  (`BRIDGE_LW_CAPTURE_HEX`), relay/summary off.
- `xiao_esp32s3` — stock control, encoder compiled out (used for A5).

**Bench credentials (throwaway, baked into the `bench_lw_enc*` envs):** DevAddr `01000001` ·
NwkSKey `2B7E151628AED2A6ABF7158809CF4F3C` · AppSKey `D41420B7F5A3C96E1D8204F7B3A65C90` · FPort `13`.

**Flash a board:**
```
pio run -e <env> -t erase  --upload-port COMx     # wipe NVS (clean config + FCnt)
pio run -e <env> -t upload --upload-port COMx
```
Erase is required when changing env/config — autosave/portal only act on an unconfigured board.

**Capture serial (how the evidence above was obtained) — two equivalent ways:**
- Manual: `pio device monitor --port COMx --baud 115200`, then press the board's **RST** button to
  catch the one-time boot dump.
- Automated (used for this report): `python tools/bench-serial-capture.py COMx <seconds>` — opens the
  port, hardware-resets the board (DTR/RTS), and prints serial for N seconds. The boot dumps and
  `evt=…` lines quoted above are verbatim from this tool.

**Verify a captured packet off-box (method behind B5):**
`python tools/lw-verify.py <PHYPayload-hex> <NwkSKey> <AppSKey> [--tagged]` — validates the MIC and
decrypts the FRMPayload; mirrors `src/LoRaWANCrypto.h` byte-for-byte.

**Rig & stimulus:** two boards — **DUT-A on COM13** (sender) and **SNIFFER on COM6** (listener); a
Meshtastic node (`!0AC9F340`, US LongFast) transmitted the text messages. Serial was read on the
host PC over USB. ChirpStack was **not** used for any result above (Tier C is the colleague's rig).

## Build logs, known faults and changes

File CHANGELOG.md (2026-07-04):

# Changelog

## Unreleased — LoRaCam (branch `lora_cam_xiao`, NOT merged to main)

**Status: Phase 1 + Phase 2a proven on silicon 2026-06-28; Phase 3 (always-on web portal) BENCH-PROVEN
2026-07-03 — all gating tests pass (`BENCH-PHASE3.md`); Phase 2b (photos + video record + Photos tab)
PROVEN 2026-07-04 (branch `lora_cam_xiao`, NOT merged — owner-gated).** A LoRa-commanded camera built on the v9.0 bridge: a XIAO ESP32-S3 **Sense** (OV2640
+ microSD on the rear B2B 40-pin) + a perimeter-pin **Wio-SX1262** edge radio. Commands ride an encrypted,
sender-whitelisted, replay-protected binary frame on a `PROTO_CUSTOM` radio (sync `0x33`); design of record
[`LORACAM-SPEC.md`](LORACAM-SPEC.md), bench guide [`BENCH-CAMC2.md`](BENCH-CAMC2.md). **Stock repeater builds
stay byte-identical** (`xiao_esp32s3` = 865781 B) — all new code is `#if defined(BRIDGE_ROLE_CAMERA) ||
defined(BRIDGE_CAM_COMMANDER)`.

- **Phase 1 — C2 security core.** New `src/CamC2.{h,cpp}` (frame
  `[ver0xC2][type][senderId:4][recipientId:4][seq:4][ciphertext][cmac:8]`, AES-CTR **encrypt-then-MAC** with an
  8-byte truncated AES-CMAC reusing `LoRaWANCrypto`, keys domain-separated from the per-peer PSK, constant-time
  tag compare, fail-closed boot self-test) + `src/CamC2Config.{h,cpp}` (a `c2auth` NVS per-peer whitelist +
  persist-on-accept fail-closed anti-replay + a reboot-safe block-reserved TX sequence). One guarded hook in
  `ingestAndFanout()` (PROTO_CUSTOM) + `CamC2::begin()` in setup. Offline tool `tools/cam-c2.py`
  (gen/verify/selftest). **Adversarially reviewed sound** (6-lens crypto review). **End-to-end proven:** a signed
  command crosses real LoRa, the cam authenticates + executes it, and ACKs back.
- **Phase 2a — camera capture.** New `src/CameraNode.{h,cpp}` (OV2640 init for the XIAO S3 Sense via
  `esp_camera`) wired into `executeCommand`: a `snap` command captures a real JPEG (proven: 800×600, ~14 KB) and
  the ACK reports it. The example's LED-flash pin (GPIO21 = microSD CS) is deliberately not driven.
- **Phase 3 — always-on web portal (BENCH-PROVEN on silicon 2026-07-03, `BENCH-PHASE3.md`).** New `src/CamPortal.{h,cpp}`
  (a WPA2 SoftAP + a login-gated synchronous `WebServer` on :80) and `src/CamStream.{h,cpp}` (an
  `esp_http_server` on :81 dedicated to the MJPEG stream — its own translation unit because `esp_http_server.h`
  and `WebServer.h` both define `HTTP_GET`). The portal serves: **live video** (MJPEG `<img>` + `/jpg` snapshot),
  **camera control** (snap / record / stop / status via direct `executeCommand`, local-trust — gated by the
  portal login, not the LoRa crypto latch), **config** (reuses the existing captive form verbatim via new
  camera-gated `CaptivePortal::serveConfigForm()/serveConfigSave()` entry points — one source of truth; a save
  reboots), **messaging** (a new signed/encrypted `T_MSG` C2 frame type + an inbound ring; chat with whitelisted
  masters), and **pairing** (manage the `c2auth` peer whitelist) + a **Security** page (change the WPA2 passphrase
  + portal login). New `src/CamPortalConfig.{h,cpp}` stores the AP passphrase + a salted-SHA-256 login in its own
  `camportal` NVS namespace (no `BridgeConfig` schema bump). Cookie-based sessions; the :81 stream is gated by a
  `?sid=` token. `CameraNode` gained a camera mutex so a stream frame and a C2 `snap` can't race on `esp_camera`.
  Pumped from a dedicated FreeRTOS task. Cam env 978 KB (27.9%→29.3%); **stock still 865781 B (do-no-harm)**.
- **Build envs.** `xiao_loracam` (product), `bench_camc2` (cam) + `bench_camc2_cmdr` (commander) for the
  two-board bench; bench provisioning via `BRIDGE_C2_MY_ID` / `BRIDGE_C2_PEER_ID/_KEY/_PRIMARY` and the portal
  defaults `BRIDGE_PORTAL_USER/_PASS/_AP_PASS`. A do-no-harm `LORA_RADIO{1,2}_DISABLE` build-flag seam disables a
  radio slot (the camera build disables R1, whose B2B pins the camera occupies).
- **Phase-3 hardening (2026-07-03, from the bench-plan red-team + the bench itself).** ① `BridgeConfig` now
  re-applies `LORA_RADIO{1,2}_DISABLE` after every NVS blob load/migration and before every save
  (`applyBuildDisables()`) — a saved config can no longer re-enable R1 onto the camera's B2B pins (proven on
  silicon: saved R1=Meshtastic persisted as `proto=0`). ② The commander gained a `T_MSG` hook (`m` serial key +
  inbound-message print) — messaging proven both directions on air. ③ The :81 stream retries transient null
  frames instead of ending (a frozen `<img>` needed a manual refresh). ④ The portal reloads the stream on
  `visibilitychange` (Android kills the MJPEG connection on screen sleep with no error event). Stock build
  verified byte-identical (865781 B) after all four.
- **Phase 2b — microSD photo persistence + a portal Photos tab (PROVEN on silicon 2026-07-04).** The microSD
  (CS=GPIO21) mounts on the SHARED radio SPI bus (`CameraNode::beginStorage(spiMutex)`, SD CS parked HIGH during
  radio detection like the radios' own NSS); every SD operation holds `spiMutex`, lock order camera→bus. A snap
  now writes `/loracam/IMG_%05u.jpg` and the LoRa ACK carries the REAL path (the PSRAM descriptor remains the
  no-card fallback; a short write is deleted, not left as a stub file); numbering resumes across reboots by
  directory scan; the status beacon's SD-free byte is real (`0xFF` = no card). New portal **Photos** tab: newest-
  first listing (cap 48), view/download, delete-with-confirm — photos are addressed by index, never by a caller
  path. Proven: 16 GB card, two LoRa captures → `IMG_00001/00002.jpg` (~16.7 KB), reboot resumed at 00003, both
  JPEGs viewed from the portal. Stock build still byte-identical (865781 B; SD/FS are camera-gated).
- **Phase 2b — video record (PROVEN on silicon 2026-07-04).** The `record` command is no longer a stub: an async
  `recTask` captures JPEG frames at ~5 fps into a standard MJPEG-AVI (`/loracam/VID_%05u.avi`, hand-built RIFF
  with an `idx1` index); the LoRa ACK returns the filename immediately, `stop` finalizes early, and the Photos
  tab lists/serves videos alongside photos. A `r`→`x` clip (61 frames / 12 s) validated with a strict RIFF parser
  (all 61 frames decode as 800×600 JPEGs) and plays in VLC. Two bench-found fixes shipped: (1) the finalize used
  `f.size()` mid-write (lags the stdio buffer) → the total is now counted arithmetically; (2) **portal media
  downloads lost their session cookie** — a browser `.avi` download handoff (Android) dropped the cookie, so
  `/photo` redirected to `/login` and saved the login HTML as the file; media links now carry a `?sid=` token
  (like the :81 stream), `/photo` accepts a cookie OR the token and returns 401 (not a 302) on failure, with
  `Content-Disposition: attachment`. The card write itself was never wrong (proven by a hexdump of the on-card
  bytes — a lesson that ground truth beats code analysis).
- **First-flash provisioning security (PROVEN on silicon 2026-07-04).** A camera build no longer exposes the
  legacy OPEN captive portal (passwordless AP + unauthenticated `/save`); an unconfigured camera persists its
  build-flag defaults and boots straight to the WPA2 + login portal. The non-camera stock path is the untouched
  `#else` (byte-identical, 865781 B). Proven: a wiped `xiao_loracam` first-boots to `SoftAP … WPA2 up` with no
  captive/open-AP line.
- **Multi-hop C2 relay (commander → repeater → cam; PROVEN on silicon 2026-07-04).** The bridge did not
  raw-repeat Custom frames (it ABP-wraps or drops them), so a repeater dropped C2 commands. Added a flag-gated
  Custom same-channel raw-repeat (`BRIDGE_CUSTOM_REPEAT`) in `ingestAndFanout`, reusing the MT/MC raw-repeat
  machinery; off for every stock/cam/commander env (stock stays byte-identical). New bench envs
  `bench_repeater_custom` + `bench_camc2_cmdr_905`. Proven on a 3-board frequency-split rig (cam 906.875 can't
  hear the commander on 905): command and ACK both relayed through the repeater, and a negative control (repeater
  reset mid-test) confirmed the cam is reachable ONLY via the repeater.
- **Not yet done:** the skipped/deferred bench items (AP-passphrase change, Wave-5 soaks/specials); promoting
  `BRIDGE_CUSTOM_REPEAT` from a bench flag to a portal-configurable repeater option; the merge-to-main decision.

## v9.0 — four-radio bridge (2xiao_4sx1262)

**Status: SHIPPED 2026-06-20 (tag `v9.0`).** Two Xiao boards can now be linked over a UART
crossover into one **four-radio** sub-GHz bridge — a *master* (R1/R2 local) plus a *radio
co-processor* (R3/R4) — driven by a per-radio routing matrix. **Fully backwards compatible:**
a single Xiao still runs as the original two-radio Meshtastic ↔ MeshCore bridge with no
changes (Radio 3 / Radio 4 default to disabled, no co-processor, no UART link opened), and
existing 2-radio configs migrate unchanged (`BridgeConfig` schema **v4 → v5**). Builds green:
`xiao_esp32s3` / `xiao_esp32s3_v1_1` (master) + `xiao_coproc_sx1262` / `xiao_coproc_sx1262_v1_1`
(co-processor). Bench: the gating set (0.1–0.3 / A1 / A2 / B1) PASSED on the 2-board rig —
see [`BENCH-v9.0.md`](BENCH-v9.0.md).

- **Four radios over a UART crossover.** A second Xiao runs a lightweight **radio
  co-processor** firmware ([`coproc-xiao-sx1262/`](coproc-xiao-sx1262/)) driving its two SX1262
  as Radio 3 / Radio 4; the master Xiao owns routing, dedup, the captive portal, and the config
  for all four radios and drives R3/R4 over the link. Crossover wiring: master `D6` (GPIO43, TX)
  ↔ co-proc `D7` (GPIO44, RX), master `D7` ↔ co-proc `D6`, GND ↔ GND, 460800 baud — the cable
  does the crossover.
- **Per-radio routing matrix.** A portal "bridge received traffic to" grid picks, per radio,
  which of the others it relays to (`R1→R2/R3/R4`, etc.) — a full four-way mesh, independent
  pairs, or one-way feeds rather than a fixed all-to-all. `BridgeConfig` schema **v4 → v5**
  (4-radio table + per-radio `routeMask`); a clean v2/v3/v4 → v5 migration preserves R1/R2 + the
  R1↔R2 crossover and defaults R3/R4 off.
- **The master self-heals the link.** It pushes R3/R4 config when it sees the co-processor come
  up and re-pushes automatically on a co-processor reboot; if R3/R4 are *enabled* but no
  co-processor is attached, remote transmits fail fast instead of stalling — a single-board
  build is never slowed.
- **Console logging serialized.** All task-context serial output now goes through one shared
  lock, so the two radio tasks + the link task no longer interleave (garble) mid-line on the USB
  console; the USB TX buffer was enlarged to absorb bursts.
- **Co-processor V1.0 / V1.1 variants.** The co-processor ships in both Radio-2 edge-module
  revisions (`xiao_coproc_sx1262` / `_v1_1`), matching the master's V1.0/V1.1 split.
- **Docs.** README gains the four-radio wiring / parts / build / routing content woven into the
  existing sections; [`CONFIG-USER-MANUAL.md`](CONFIG-USER-MANUAL.md) gains §4.8 (Radio 3/4) +
  §4.9 (routing matrix) + a four-radio example; `platformio.ini` gains a commented "Scenario D"
  four-radio compile-time preset plus bench-config flags (`LORA_RADIO{3,4}_ENABLE`,
  `LORA_RADIO{1..4}_ROUTE_MASK`).

## v8.4.1 — captive-portal UI cleanup + user manual + ChirpStack tooling (UI_UM_config)

**Status: SHIPPED 2026-06-18 (tag `v8.4.1-UI_UM_config`).** A UI / docs / tooling
release — **no protocol, routing, or on-air behaviour changes**. `BridgeConfig` schema
**v4 unchanged** (the new per-radio LoRaWAN region reuses a spare `RadioRf` byte — no NVS
migration); V1.0 and V1.1 builds behave as on v8.4. Builds green: `xiao_esp32s3` /
`xiao_esp32s3_v1_1` / `xiao_esp32s3_lwabp`.

- **Captive-portal look-and-feel cleanup.** Bridge-behaviour toggles moved into the top
  identity frame (with a "Meshtastic only" note); the Meshtastic Channel key shows the
  `AQ==` LongFast default; Meshtastic BW/SF/CR are shown read-only and auto-filled from the
  Modem preset; the MeshCore helper notes the public key starts `8b…`; the Channel name is
  locked to `N/A` for LoRaWAN and defaults to `N/A` (editable) for Custom; a hint warns that
  a custom Meshtastic PSK needs a matching private channel name.
- **LoRaWAN region / channel-slot picker.** A per-radio LoRaWAN **region** selector (US915 /
  AU915 / AS923 / EU868) + a **channel slot** dropdown auto-fills Frequency / SF / Bandwidth
  (CR fixed at 4/5) from RP002-1.0.3 channel plans. The region is **persisted** (reuses a
  spare `RadioRf` byte — no schema bump).
- **Per-device identity from the MAC.** A fresh board now derives its long name
  (`<NodeID> LoRa Bridge`) and short name (`BR<low-byte>`) from the MAC-derived node ID
  instead of a shared build-flag default. The now-residual `BRIDGE_MT_NODE_ID` / `_STR` /
  `_LONG_NAME` / `_SHORT_NAME` flags were removed (they were always overridden by the MAC
  derivation).
- **Smarter protocol-switch autofill.** Choosing a Modem preset updates the Meshtastic
  Channel name (until you enter a custom key, which unlocks the name — same idea on
  MeshCore); selecting **Reticulum** auto-fills the RNode defaults (914.875 MHz / 125 kHz /
  SF8 / CR5); Reticulum BW/SF/CR are now user-editable.
- **New user manual — [`CONFIG-USER-MANUAL.md`](CONFIG-USER-MANUAL.md)** (linked from the
  README): a field-by-field walkthrough of every portal screen with its build flag, a
  detailed LoRaWAN ABP section (Applies-to-source ladder + source tag), three example setups
  (MT↔MC, MT→LoRaWAN, MT public→private), and the full build-flag reference.
- **ChirpStack tooling.** Importable device-profile templates under
  [`tools/chirpstack/`](tools/chirpstack/) (US915 / AU915 / AS923 / EU868 ABP profiles +
  vendor/device manifests + codec test vectors) and a hardened
  [`tools/chirpstack-codec.js`](tools/chirpstack-codec.js) decoder (real UTF-8, `warnings`/
  `errors`, device-variable-driven source-tag handling).
- **Compile-time preloading.** New per-radio channel build flags
  (`LORA_RADIO{1,2}_CHANNEL_NAME` / `_KEY`) + three commented "scenario" blocks in
  `platformio.ini` you can uncomment to preload the wifi config (MT↔MC, MT→LoRaWAN, MT
  public→private).
- **README dedup.** Restructured + trimmed (8→5 install steps); the per-protocol table
  merged into "Routing & behavior"; the full build-flag catalog migrated to the manual; the
  header + silkscreen images resized.

## v8.4 — LoRaWAN ABP uplink encoder (keyed)

**Status: SHIPPED 2026-06-16 (tag `v8.4-ABP-lorawan`) — build-green, crypto-verified,
and hardware-verified on air.** Meshtastic *and* MeshCore frames encode to valid ABP
uplinks that decrypt back with a valid MIC; **12/16 bench tests pass**, and the only
remaining item is live-ChirpStack (Tier C) ingestion (`BENCH-RESULTS.md`). Design:
`ABP-LORAWAN-SPEC.md`.

- **Keyed LoRaWAN ABP *uplink* encoder.** The v8.3 keyless tap couldn't inject
  content into LoRaWAN (`MT/MC → LoRaWAN` was a `no-lw-encoder` drop). v8.4 adds
  an opt-in **keyed** encoder: when a `0x34` destination radio has ABP
  credentials, the bridge transcodes a decoded MT/MC body into a valid LoRaWAN
  1.0.x **ABP uplink** (DevAddr + `NwkSKey` + `AppSKey`; AES-CTR FRMPayload,
  AES-CMAC MIC, monotonic FCnt, ADR off, Unconfirmed) and re-emits it over RF
  (delivery model **B1**) for an existing gateway to forward to a ChirpStack LNS.
- **New `src/LoRaWANCrypto.h`** — a self-contained **RFC 4493 AES-CMAC** over
  mbedTLS AES (the prebuilt esp32s3 mbedTLS ships `CONFIG_MBEDTLS_CMAC_C` off, so
  `mbedtls_cipher_cmac` won't link) + `encodeUplink()` + a boot self-test
  (`BRIDGE_LW_ENC_SELFTEST`) of the RFC 4493 vectors, the FRMPayload keystream,
  and a frame round-trip. Crypto cross-checked against an independent CMAC.
- **Ships in the standard build (config-gated do-no-harm).** As of v8.4 the encoder
  is compiled into `xiao_esp32s3` (V1.0) **and** `xiao_esp32s3_v1_1` (V1.1) — no
  separate env — but stays **dormant** until you set a radio to LoRaWAN and add an
  ABP device (`BRIDGE_LW_ENCODE` default 1; set 0 to compile it out). A stock MT/MC
  bridge is behaviourally unchanged; the only delta is a boot `[LoRaWANConfig]` /
  `[lw-enc]` line and ~12 KB flash. Build-flag keys (`BRIDGE_LW_ENC_NWKSKEY` /
  `_APPSKEY` / `_DEVADDR` / `_FPORT`) remain the single-device fallback. Bench env:
  `bench_lw_enc`; `xiao_esp32s3_lwabp` now just adds the boot self-test.
- **Per-source ABP devices + portal + persisted FCnt (P2).** A dedicated
  `src/LoRaWANConfig.{h,cpp}` module holds a bounded 4-slot per-source ABP
  identity table in its OWN NVS namespace (`lwabp`) — not a BridgeConfig schema
  bump — with a captive-portal "LoRaWAN ABP devices" section and a reboot-safe
  FCnt (block reservation, one write per 32 uplinks). The encode seam resolves a
  per-source device (else the build-flag fallback). New `xiao_esp32s3_lwabp` env.
- **Universal mapping + Custom weather-station path + codec (P3).** Any decoded
  source maps to an ABP uplink; a raw-LoRa **Custom** source wraps its raw RX
  bytes as the FRMPayload (the canonical weather-station scenario). Optional
  per-device source tag (`[proto][srcId]`) for a multiplexed device.
  `tools/chirpstack-codec.js` is a sample ChirpStack v4 codec.
- **Regional timing (P4).** US915 per-TX **dwell cap** (400 ms ToA) in the TX
  scheduler; EU868 duty via `BRIDGE_TX_DUTY_PERCENT`.
- **Portal UX: auto-fill RF defaults on protocol switch.** Changing a radio's
  Protocol dropdown now fills the new protocol's defaults (MeshCore: public key +
  `910.525`/BW62.5/SF7/CR5; Meshtastic: blank LongFast PSK), fired only on an actual
  change so a value the user typed isn't clobbered. Closes the stale-field trap
  behind a 50 kHz freq slip (`910.575` vs `910.525`) that cost a bench session.
- **Bench:** hardware-verified on the COM13-DUT / COM6-sniffer rig — **12 PASS /
  4 OPEN** (`BENCH-RESULTS.md`): crypto self-test, dwell cap, stock do-no-harm, MT
  *and* MC → ABP (decrypt + MIC), reboot-safe + DevAddr-keyed FCnt, per-source
  resolve, source-protocol tag, over-cap drop. The only open items are the
  colleague's live **ChirpStack (Tier C, C1–C4)** ingestion. Plan: `BENCH-v8.4.md`.
- **Deferred (not in v8.4):** ABP/OTAA *decode* (own fleet → MT/MC), the dual-LNS
  crosslink, and the MT/MC→RNS encoder.

## v8.3.1 — Radio 2 module-revision (V1.0 / V1.1) support + bring-up hardening

**Status: implemented on `v8.3.1-r2-pin-variants`, build-green (both variants,
Flash 24.6%). V1.1 pin map (`NSS=4 DIO1=1 RST=3 BUSY=2 RF_SW=5`) bench-confirmed on
a physical V1.1 module.**

Fixes a Radio-2 detection failure — `[Radio1-B2B] begin() failed: -2`
(`CHIP_NOT_FOUND`) and a FATAL halt — that appeared on some boards but not others
with seemingly identical hardware. Root cause: Seeed shipped the **"Wio-SX1262 for
XIAO" edge module (Radio 2) with two different pinouts**. The chip-select (NSS) is
on **D4 / GPIO5** on **V1.0** but **D3 / GPIO4** on **V1.1**. The v8.x firmware only
ever shipped the V1.0 map, so on a V1.1 module the real chip-select is left
floating during Radio 1's `begin()`; the un-deselected V1.1 chip then drives the
shared MISO bus and corrupts Radio 1 detection — fatally, since Radio 1 is
mandatory.

- **Per-revision build variants.** Radio-2 pins are selected by `WIO_SX1262_REV`
  (10 = V1.0, default; 11 = V1.1):
  - `xiao_esp32s3` — V1.0 (unchanged; the default release binary).
  - `xiao_esp32s3_v1_1` — V1.1 (`NSS=4 DIO1=1 RST=3 BUSY=2 RF_SW=5`).

  Each `R2_*` pin is `#ifndef`-guarded, so a single `-DR2_NSS=..` (etc.) can also
  override one pin from `platformio.ini`. (Radio 1 is fixed B2B silicon — it stays
  a plain define and is never remapped.)
- **Bring-up hardening — a Radio-2 fault can no longer take down Radio 1.** Radio 2
  is held in hardware reset (`RST` is `GPIO3` on *both* revisions) for the whole of
  Radio 1's probe + `begin()`, then released and brought up afterward. A wrong
  variant (or any R2 fault) now leaves Radio 1 running single-radio with a message
  naming the silkscreen check and the env to flash — it no longer halts.
- **Self-identifying boot log.** Boot prints
  `[diag] R2 edge module = V1.0  (NSS=5 DIO1=2 RST=3 BUSY=4 RF_SW=6)`, so any
  serial log shows which revision the firmware was built for.
- **Docs.** `README.md` "Wiring" gains a "Radio 2 module revision" section with
  silkscreen photos and an identification table.
- **Do-no-harm note.** On a correctly-matched board the only behavioral change is
  serial-log *ordering*: the Radio-2 reset diagnostic now prints as
  `[diag] R2 release  BUSY after reset = …` **after** `[Radio1-B2B] ready` (R2 is
  reset after R1 is up). Radio operation is unchanged.

## v8.3 — LoRaWAN keyless bridge + Reticulum repeat + POSITION clock

**Status: implemented on `v8.3-dev`, build-green; awaiting owner bench — not yet
tagged or released.**

- **POSITION clock-learn.** The bridge now also learns wall-clock from a
  Meshtastic `POSITION_APP` time field (`Position.time` field 4, `.timestamp`
  field 7 as fallback), closing the cold-boot window where `MT→MC` bridged
  messages stamped 1969 until the first timestamped MeshCore packet arrived.
- **Transparent in-protocol Reticulum repeat (`RNS → RNS`).** When both radios
  run Reticulum, an inbound RNS frame is now re-transmitted byte-for-byte on the
  other radio (a transparent range-extension repeater) instead of being dropped;
  RNS Transport handles hop limits and dedup at the network layer. Gated by
  `BRIDGE_RNS_INPROTO_REPEAT` (default 1). `RNS → MT/MC` tunnelling and the
  `MT/MC → RNS` drop are unchanged.
- **LoRaWAN (sync `0x34`) — keyless.** A new `LoRaWAN` per-radio protocol in the
  captive portal:
  - **Metadata capture tap** — decodes the cleartext LoRaWAN MAC header (MType,
    DevAddr, FCtrl, FCnt, FPort, FRMPayload length; JoinEUI/DevEUI for
    join-requests) and logs `evt=RX proto=LW`. No `FRMPayload` decrypt (no keys).
  - **Metadata summary to mesh** — emits a one-line summary onto the MT/MC meshes
    (`BRIDGE_LW_SUMMARY_TO_MESH`, default on).
  - **Transparent LW↔LW relay / dedup-bounded flood "mesh"** — re-transmits the
    raw `0x34` frame to other LoRaWAN radios (`BRIDGE_LW_RELAY`), loop-bounded by
    the shared content-hash dedup. There is no in-band hop counter (mutating the
    frame would break its MIC); flood is bounded by dedup + the airtime throttle.
    Single-channel per radio (no LoRaWAN channel hopping) — a localized bridge,
    like the Tasmota model.
  - `MT/MC → LoRaWAN` is a deliberate log-and-drop (`no-lw-encoder`): keyless
    firmware cannot inject content into LoRaWAN.
  - **Deferred to v8.3+:** ABP/OTAA key-based decode of one's own devices
    (→ MT/MC) and `MT/MC → LoRaWAN` encode.

## v8.2.1 — MeshCore timestamp fix

**Patch — bench-verified 2026-06-13.** `MT→MC` (and `RNS→MC`) bridged messages
hardcoded the MeshCore `GRP_TXT` Unix timestamp to 0, so MeshCore clients showed
them as 1969-12-31. (`MC→MT` was unaffected — Meshtastic clients timestamp on
receipt.)

The bridge has no RTC/NTP, so it now **learns wall-clock time from inbound
MeshCore packets** (which carry a Unix `ts`) and stamps that estimate (+ elapsed
uptime) onto outbound MeshCore packets. Verified on air: an inbound MC packet
(`ts=1781399207`) calibrated the clock and the next `MT→MC` bridge stamped the
real current time (`mcts=1781399220`) instead of 0.

- `extractMeshCoreBody()` gains an optional `tsOut`; `learnClockFromMc()` +
  `bridgeNowUnix()` added in `main.cpp`; the stamped value is surfaced as
  `mcts=` on the `QUEUE` log line, with a one-time `evt=CLOCK` when first
  calibrated.
- **Known:** until the bridge hears its first timestamped MC packet after boot
  it still stamps 0 (then self-calibrates within seconds on a live mesh) —
  inherent without an RTC. A future option is to also learn time from Meshtastic
  `POSITION_APP` (which carries a Unix `time` field).

## v8.2 — RX-priority routing + source-identity preservation

**Status: bench-verified on hardware 2026-06-13 (branch `v8.2-router-backport`);
ready to tag.** Backports the RX-priority routing redesign from
the unreleased `T_LORA_QUAD_ROUTE` line onto the shipping 2-radio dual-SX1262
bridge, and adds a source-identity-preservation layer. No LR1121/co-processor
code; `BridgeConfig` stays schema v4 (no NVS migration — an upgraded v8.1 device
keeps its config). Full design + bench plan in `V8.2-SPEC.md`.

- **RX-priority pipeline (no more TX-blocks-RX).** Each radio defaults to
  receive; a received packet is decoded once, de-duplicated, re-encoded for the
  destination and pushed onto a per-destination, age-bounded, PSRAM-backed
  `RouteQueue`. The destination radio's task pops it, does **CAD**
  (listen-before-talk), and sends it with a **non-blocking** transmit, CSMA
  backoff and a duty-cycle **airtime throttle**. A long SF11 transmit no longer
  makes the bridge deaf. New: `LoraRadio` interface, `WioSX1262`
  `scanChannel`/`startTransmit`/`txDone`/`finishTransmit`, `DedupCache`,
  `RouteQueue`.
- **Content-hash loop prevention (clean far-side bodies).** The `[MT]/[MC]/[rns]`
  text markers are removed. Loops/duplicates are dropped by a TTL-windowed
  FNV-1a hash of the decoded body + sender id **+ Meshtastic packet_id**,
  recorded on receive and on every emission — which also drops a packet heard on
  both radios and never false-drops a user message starting with `[MT`. Folding
  the packet_id means a node's genuinely-distinct messages with identical text
  bridge each time (new id → new hash) while echoes/replays (same id) still drop.
- **Source-identity preservation.** A bridged repeat carries/reconstructs the
  original sender instead of the bridge:
  - **MC→MT**: the MeshCore sender name (`"<name>: …"`) becomes a deterministic
    virtual Meshtastic node (`FNV-1a("MC|"+name)`) with a synthetic NodeInfo, so
    a phone shows the message from `Alice @MC`.
  - **MT→MC**: the body is prefixed with the Meshtastic sender's name
    (`Alice@MT: …`, NodeDB short-name or `!hexid`).
  - **Same protocol, same channel, different frequency**: a transparent **raw
    repeat** — original bytes unchanged (Meshtastic: hop_limit decremented,
    `relay_node` set), so the far side sees the original sender natively.
  - Flags: `BRIDGE_IDENTITY_PRESERVE` (1), `BRIDGE_TAG_ORIGIN_PROTO` (1,
    `@MT`/`@MC` tags), `BRIDGE_MC_NONAME_VIRTUAL` (0).
  - Deferred: MT→MT re-encrypt across *different* channels (trans-crypt);
    NodeInfo is consumed for NodeDB, not raw-repeated; LoRaWAN (sync `0x34`) is a
    separate future version (capture-only — see `V8.2-SPEC.md` §14).
- **`NodeDB`** is now mutex-guarded with a copy-based `lookupShortName`, since
  more than one task reads it.
- **Structured serial logging.** One greppable `ts=… evt=… radio=… key=val` line
  per pipeline event, emitted atomically across both cores via a dedicated log
  mutex.
- **`RadioLib` pinned `7.7.0`** (the version the TX/CAD path was developed and
  bench-validated against; the LR11x0 RX deficit on 7.7.0 does not affect the
  SX126x path).
- **Captive portal**: the same-protocol self-bridge guard is now freq-aware — it
  rejects a routed pair only when protocol, channel name+key **and** frequency
  all match, so a same-channel cross-frequency relay is configurable.

## v8.1 — 2026-05-21 — Compile-time build-flag validation

A small follow-up to v8.0 — build-time safety for source builds, plus docs.

- **`LoraConfigCheck.h`** — `static_assert` guards that reject an invalid
  `LORA_RADIO*` build-flag default at compile time, so a bad flag fails
  `pio run` with a clear message instead of shipping misbehaving firmware.
  Checks: frequency 150–960 MHz, bandwidth a valid SX1262 value, SF 5–12,
  CR 5–8, TX power −9…22 dBm. Sync word is byte-range only (`0x00–0xFF`),
  not a whitelist, since the v8 Custom protocol path allows any sync word.
  Each guard is `#ifdef`-wrapped, so an unset flag (the vanilla-`.bin` case)
  is skipped. This complements v8.0's portal-side runtime validation —
  build-time checks the compile-time defaults, the portal checks
  portal-entered values.
- **README** — new Wiring section (signal/GPIO table for the stacked-shield
  Xiao ↔ dual SX1262 connections).

No firmware behaviour change for a valid configuration.

## v8.0 — 2026-05-21 — Vanilla firmware: full portal config

The bridge is now configurable **entirely through the WiFi captive portal** —
region, per-radio protocol, RF plan, channels and identity. A single `.bin`
built with no `LORA_RADIO*` build flags first-boots straight into the portal,
so a non-developer can flash and configure without PlatformIO. Build flags, if
present, become first-boot defaults only.

- **`BridgeConfig` schema v3 → v4.** New global `region` and a per-radio
  `RadioRf` struct (`protocol`, `frequency`, `bandwidth`, `sf`, `cr`,
  `syncWord`, `txPower`). `begin()` migrates a v2 or v3 blob forward — region
  and RF fall back to build-flag defaults so an upgraded device keeps running.
- **Runtime RF.** `setup()` builds each radio's `LoraConfig` from
  `BridgeConfig` at boot (`makeLoraConfig()`); the compile-time
  `LORA_RADIO*_*` RF macros and the `WioSX1262.h` `915.0f / SF9 / 0x12`
  fallback chain are gone. Preamble length (8) and TCXO voltage (1.8 V) stay
  compile-time board facts.
- **Per-radio protocol picker** in the portal: Meshtastic / MeshCore /
  Reticulum / Custom / **None**. A None radio is disabled (single-radio
  monitor mode — a debug aid, or a parked slot for a future 2.4 GHz radio).
- **Region support** — global selector for US, EU_868, EU_433, ANZ, CN, JP,
  IN, KR, RU (+ Custom/Other). New `RegionPreset.h` carries the region table,
  the Meshtastic modem-preset BW/SF/CR bundles, and the **Tier 2 channel-slot
  frequency computation** (`djb2` hash + slot formula, transcribed verbatim
  from `meshtastic/firmware` and verified: US + LongFast → 906.875 MHz). The
  computed frequency pre-fills an **editable** field; a manual override is
  flagged inline (`computed: … — overridden`).
- **MAC-derived identity.** The default Meshtastic node ID and portal SSID are
  derived from the ESP32 MAC, so every vanilla device is unique out of the box.
- **Custom RF** path exposes the full plan (frequency, BW, SF, CR, sync word,
  TX power) behind an explicit warning banner. `handleSave()` clamps frequency
  to the SX1262 range and sanity-checks SF/CR/BW/sync; TX power is capped to
  the region's regulatory limit.

This reverses the previous "protocol/RF is config-time only" decision for the
vanilla-bin use case — the MT/MC/RNS presets are vetted; only the Custom path
is dangerous, and it is behind a warning. New file: `RegionPreset.h`.

## v7.0 — 2026-05-20 — Per-radio channels, same-protocol relay

The bridge is no longer limited to cross-protocol MT↔MC. Each radio slot now
carries its own channel, so it can also relay **same-protocol between two
channels** — MC↔MC or MT↔MT (private↔public, private↔private).

- New `RadioChannel` struct (`protocol`, `key`, `keyLen`, `channelHash`,
  `name`) — two of them, one per radio slot, resolved at boot. Replaces the
  `MeshCoreConfig` / `MeshtasticConfig` singletons; those modules are now
  stateless `resolve()` helpers.
- Every decoder and encoder takes a `const RadioChannel&`; `bridgePacket()`
  decodes with the RX radio's channel and encodes with the TX radio's.
- `BridgeConfig` schema v2→v3: the protocol-specific channel fields become
  per-radio (`radio1/2ChannelName` + `radio1/2ChannelKey`). A v2 NVS blob is
  migrated forward — its MT/MC channels map onto whichever radio runs that
  protocol.
- Captive portal: the two protocol-specific channel sections become a
  *Radio 1 channel* / *Radio 2 channel* pair, each labelled by that radio's
  build-flag protocol. The form rejects a config where both radios run the
  same protocol with identical channels (a channel relayed to itself is a
  feedback loop). No RNS controls in the portal.

Radio protocol/RF stays a build-flag (`LORA_RADIO*`) decision — config-time
only, never portal-editable.

## v6.2.1 — 2026-05-20 — Build reproducibility + GPIO init fix

- **Pinned the PlatformIO platform.** `platformio.ini` now requires `espressif32 @ 6.13.0` (arduino-esp32 2.0.17) — the core the bridge is verified against. An unpinned `platform = espressif32` let a fresh checkout pull a newer core whose GPIO/SPI behaviour differs, producing spurious diagnostics on other people's builds.
- **Fixed a GPIO init bug.** The `busyWait` pre-flight diagnostic in `setup()` read the SX1262 BUSY pins via `digitalRead()` without first calling `pinMode(..., INPUT)`. Newer arduino-esp32 cores logged `[E] __digitalRead(): IO N is not set as GPIO` for each read. Harmless to radio detection, but now correct.

Neither change alters bridge behaviour — this is a build-reproducibility and diagnostic-cleanliness patch.

## v6.2 — 2026-05-20 — Remove deprecated raw RX hex dump

The raw incoming-packet hex dump (`[R1 RX] data: FF FF FF FF …`) is removed from both radio tasks. It was an early-development debugging aid — pure `Serial.printf` with no functional role — and is now deprecated. The bridge's decode → re-encode → transmit path is unaffected; the `extract*()` decoders are untouched.

Per-packet serial output keeps the RX summary line (size / RSSI / SNR), the `[R1 decoded]` protocol summary, and the bridge re-encode / TX lines.

## v6.1 — 2026-05-19 — F5: Meshtastic private-channel support

The Meshtastic side is no longer pinned to the LongFast public channel. New `MeshtasticConfig.{h,cpp}` mirrors `MeshCoreConfig`: it reads a base64 PSK + channel name from `BridgeConfig`, runs Meshtastic's key expansion, and derives the on-air channel-hash byte.

- **PSK expansion.** The base64 PSK decodes to 0 bytes (LongFast default), 1 byte (short-key index — expanded against `defaultpsk` with the last byte bumped by `index-1`), 16 bytes (AES-128) or 32 bytes (AES-256).
- **AES-256.** The five MT decoders and two MT encoders now take the key length from `MeshtasticConfig::keyLen` (128/256) instead of a hard-coded 128, so 32-byte PSK channels decrypt correctly.
- **Channel hash.** Computed as `XOR-fold(name) ^ XOR-fold(expanded key)` and used as the decoder gate, replacing the literal `0x08`.

`BridgeConfig` schema bumped v1 → v2 with two new fields (`mtChannelName`, `mtPskBase64`); a v1 NVS blob from a v6.0 build is migrated forward automatically (existing settings preserved, MT channel defaults to LongFast). The captive portal gains a "Meshtastic channel" section with name + PSK inputs, and new `BRIDGE_MT_CHANNEL_NAME` / `BRIDGE_MT_PSK_B64` build-flag defaults.

Also: the captive-portal recovery trigger now accepts **any serial-monitor character** during the post-boot window, not just the BOOT button — the button is unreachable when the radio shield is mounted over it. The window was widened 3 s → 5 s.

## v6.0 — 2026-05-19 — Captive-portal config, POSITION/TELEMETRY bridging, configurable MC channel

This release makes the bridge field-configurable without a rebuild and widens the Meshtastic traffic it understands. It bundles features F2, F3 and F4.

**WiFi captive portal (F4).** On a fresh flash — or any time the **BOOT** button is pressed within ~3 s of reset — the bridge comes up as an open WiFi AP named `LoRa-Bridge-<XX>` (last byte of the MT node ID in hex) and DNS-redirects all HTTP traffic to a single-page config form. The form exposes the eight settings users actually re-tune: Meshtastic identity (node ID numeric + `!hex` string, long name, short name), MeshCore channel (32-char hex key + display name), and the POSITION/TELEMETRY bridge toggles. Saving writes a schema-v1 blob to NVS and reboots into bridge mode. New `BridgeConfig.{h,cpp}` is the single source of truth; the `BRIDGE_MT_*` / `BRIDGE_MC_*` build flags become the defaults a fresh device starts from, so existing `platformio.ini` configs behave identically until the portal saves something new.

**POSITION + TELEMETRY bridging (F2).** `POSITION_APP` and `TELEMETRY_APP` are decoded from incoming MT packets and re-emitted to MeshCore as compact text under the existing `[MT !<hexid> <SHORT>]` marker — `pos 40.7234,-74.0123 alt 12m`, `bat 87% 4.05V`, `env 22.5C RH 45% 1013hPa`. Each portnum is individually toggleable from the portal or via build flag.

**Configurable MeshCore channel (F3).** The hard-coded public-channel key moved into a new `MeshCoreConfig` module; the bridge can now point at any MC channel via config, with the on-air channel hash auto-derived from `SHA-256(key)[0]`.

Per-radio LoRa parameters (frequency, BW, SF, CR, TX power, sync word) remain build-flag-only — out-of-band misconfiguration is too easy to expose in a v1 form.

### Changes since v5.0

`v5.0..v6.0` — commit `04c0c5a`. 12 files changed, +1122 / -62.

```
 CHANGELOG.md           |  14 ++         changelog
 README.md              |  35 ++         instructions + roadmap (F5, portal v2, 2.4 GHz)
 platformio.ini         |  13 ++         BRIDGE_MC_* / BRIDGE_MT_* flag examples
 src/BridgeConfig.h     |  64 ++         new — NVS-backed config interface
 src/BridgeConfig.cpp   | 178 ++         new — schema-v1 blob load/save/defaults
 src/CaptivePortal.h    |  29 ++         new — portal interface
 src/CaptivePortal.cpp  | 276 ++         new — WiFi AP + DNS + HTTP config form
 src/MeshCoreConfig.h   |  33 ++         new — MC channel module interface
 src/MeshCoreConfig.cpp |  68 ++         new — key/hash from BridgeConfig
 src/MeshDecoderDebug.h | 312 ++         POSITION/TELEMETRY decoders, MC config refs
 src/MeshEncoderDebug.h |  37 ++         encoders take srcNodeId param
 src/main.cpp           | 125 ++         portal trigger, runtime portnum gates, wiring
```

New files: `BridgeConfig.{h,cpp}`, `CaptivePortal.{h,cpp}`, `MeshCoreConfig.{h,cpp}`.

## v5.0 — 2026-05-19 — Persistent NodeDB & MT sender attribution

This release adds end-to-end sender attribution for MT→MC bridged text, plus reliability fixes shaken out during integration testing.

**Bridge attribution.** MT→MC text now carries the sender's canonical Meshtastic `!<8 lowercase hex>` ID in the bridge marker — `[MT !3d3a87a3] body` from any new MT node, upgrading to `[MT !3d3a87a3 KN5J] body` once the bridge has heard a `NODEINFO_APP` packet from that node.

**NodeDB.** New `NodeDB.{h,cpp}` module: 64-entry, NVS-persistent `(nodeId → short_name, long_name)` table populated by a new `extractMeshtasticNodeInfo()` decoder in `MeshDecoderDebug.h`. LRU eviction when full. Attribution survives reboot.

**Reliability fixes:**

- Radio-task stacks raised 4 KB → 8 KB; `saveToNvs()` scratch buffer (~3.3 KB) moved off-stack into BSS. Fixes hard-reset on every received NodeInfo.
- Bridge drops upserts of its own NodeInfo bouncing back via relays.
- NodeDB opens NVS namespace in RW mode on first boot to silence the cold-boot `nvs_open failed: NOT_FOUND` log.

Received MT NodeInfo packets feed the DB and are not bridged as text (would just be noise on the destination mesh).

## 2026-05-18 — RNS fragmentation

RNS bridging now uses base64 + auto-fragmentation across MT/MC packets with `[rns <seq> <x>/<y>]` markers, CRC-16 sequence IDs, per-protocol fragment pacing, and 8-fragment cap.

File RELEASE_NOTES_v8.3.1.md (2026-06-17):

# v8.3.1 — Radio 2 module-revision (V1.0 / V1.1) variants + bring-up hardening

A reliability / compatibility patch on [v8.3](https://github.com/GrayHatGuy/Xiao-esp32s3-lora-repeater/releases/tag/v8.3). No protocol or routing changes — V1.0 boards behave exactly as on v8.3.

## What this fixes
Seeed ships the **"Wio-SX1262 for XIAO" edge module (Radio 2) in two pinouts**: the chip-select (NSS) is on **D4 / GPIO5** on **V1.0** but **D3 / GPIO4** on **V1.1**. Every v8.x build assumed the V1.0 map — so on a **V1.1** module, Radio 2's real chip-select is left floating during Radio 1's `begin()`, drives the shared SPI MISO bus, and Radio 1 fails to detect (`[Radio1-B2B] begin() failed: -2`, `CHIP_NOT_FOUND`) → the bridge **FATAL-halts**. It reproduced on one board but not another with otherwise identical hardware. (V1.1 map bench-confirmed on a physical V1.1 module.)

## Pick the variant that matches your Radio 2 module
Read the silkscreen on the **Radio 2** edge module and flash the matching build:

| Radio 2 silkscreen | NSS lands on | Build env · release bin |
|---|---|---|
| **`V1.0`** | D4 / GPIO5 | `xiao_esp32s3` · `…-v1.0-vanilla-factory.bin` |
| **`V1.1`** | D3 / GPIO4 | `xiao_esp32s3_v1_1` · `…-v1.1-vanilla-factory.bin` |

The boot log echoes the active map so you can confirm: `[diag] R2 edge module = V1.0  (NSS=5 DIO1=2 RST=3 BUSY=4 RF_SW=6)`. See [README "Wiring"](README.md#radio-2-module-revision-v10-vs-v11) for photos of each silkscreen.

## Bring-up hardening (both variants)
Radio 2 is now held in hardware reset (RST is GPIO3 on **both** revisions) through Radio 1's bring-up, then released afterward. **A wrong-variant flash — or any Radio-2 fault — can no longer halt the bridge:** Radio 1 always comes up, Radio 2 is disabled gracefully, and the log names the env to flash. No more silent FATAL on a mismatched edge module.

## Compatibility / do-no-harm
- **V1.0 (default) behavior is unchanged** from v8.3 — the only serial-log difference is that the Radio-2 reset diagnostic now prints (`R2 release  BUSY after reset …`) **after** `Radio1-B2B ready`.
- `BridgeConfig` schema **v4 unchanged** — no NVS migration; v8.3 configs load as-is.
- No protocol / routing / LoRaWAN changes.

## Downloads (pick the one matching your Radio 2 silkscreen)
- **`xiao-dual-sx1262-v8.3.1-v1.0-vanilla-factory.bin`** — V1.0 module · full image, flash `@ 0x0` (fresh/erased → captive portal).
- **`xiao-dual-sx1262-v8.3.1-v1.0-app.bin`** — V1.0 module · app image, flash `@ 0x10000`.
- **`xiao-dual-sx1262-v8.3.1-v1.1-vanilla-factory.bin`** — V1.1 module · full image `@ 0x0`.
- **`xiao-dual-sx1262-v8.3.1-v1.1-app.bin`** — V1.1 module · app image `@ 0x10000`.

Full notes: [CHANGELOG.md](CHANGELOG.md) · Change / porting record: [V8.3.1-R2-VARIANTS.md](V8.3.1-R2-VARIANTS.md). Flashing instructions: see the [v8.2 release](https://github.com/GrayHatGuy/Xiao-esp32s3-lora-repeater/releases/tag/v8.2).

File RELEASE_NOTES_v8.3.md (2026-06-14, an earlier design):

# v8.3 — LoRaWAN keyless bridge/relay/mesh + carry-overs

Builds on [v8.2.1 (MeshCore timestamp fix)](https://github.com/GrayHatGuy/Xiao-esp32s3-lora-repeater/releases/tag/v8.2.1). Adds a keyless **LoRaWAN (LoRa sync `0x34`)** protocol plus two carry-over fixes. **Bench-validated on hardware 2026-06-14:** the full LoRaWAN feature set, both clock-learn paths, and the complete Reticulum block — RNS↔RNS raw repeat (byte-identical), RNS→MeshCore tunnel, and MC/MT→RNS log-and-drop — all verified on air, plus the v8.2 routing regression set (do-no-harm confirmed: MT/MC traffic never enters the LoRaWAN path).

## New — LoRaWAN (sync `0x34`), keyless
Select **LoRaWAN** for either radio in the captive portal. The bridge operates only on the **cleartext PHY frame** — no keys, no payload decryption:
- **Metadata capture tap** — decodes the cleartext MAC header (MType, DevAddr, FCtrl, FCnt, FPort, FRMPayload length; JoinEUI/DevEUI on join-requests) to the serial log (`evt=RX proto=LW …`).
- **Metadata summary to mesh** — emits a one-line summary onto your Meshtastic/MeshCore mesh (`BRIDGE_LW_SUMMARY_TO_MESH`, default on).
- **Transparent LW↔LW relay / dedup-bounded flood** — re-transmits raw `0x34` frames between radios and bridges (`BRIDGE_LW_RELAY`); a localized transparent bridge modeled after the [Tasmota LoRa & LoRaWAN Bridge](https://tasmota.github.io/docs/LoRa-and-LoRaWan-Bridge/).
- `MT/MC → LoRaWAN` is a deliberate log-and-drop (`no-lw-encoder`): keyless firmware cannot inject content into LoRaWAN.

## Also new
- **POSITION clock-learn** — the bridge now also learns wall-clock from a Meshtastic `POSITION_APP` time field, closing the cold-boot 1969-timestamp window left by v8.2.1 (which learned only from MeshCore).
- **Transparent in-protocol Reticulum repeat (RNS↔RNS)** — with both radios on Reticulum, an inbound RNS frame is re-transmitted byte-for-byte (range-extension repeater) instead of being dropped (`BRIDGE_RNS_INPROTO_REPEAT`, default on).

## Known limitations
- LoRaWAN is **single-channel per radio** (no LoRaWAN channel hopping) and does not honour Class-A RX windows — a localized capture/relay bridge, not a gateway.
- The flood "mesh" is **dedup/TTL-bounded** (each bridge repeats a unique frame once); there is no in-band hop counter (mutating the frame would break its MIC).
- LoRaWAN **content** decode/encode needs per-device session keys — see Deferred.

## Deferred → v8.3+ (8.3.1 patch)
- ABP/OTAA key-based **decode** of the operator's own devices → MT/MC/custom, and **encode** (MT/MC → LoRaWAN).
- Reticulum **MT/MC → RNS** encoder + fragment reassembly (today MT/MC→RNS is a clean log-and-drop).

## Build flags (all default `1`; override in `platformio.ini`)
`BRIDGE_LW_CAPTURE` · `BRIDGE_LW_SUMMARY_TO_MESH` · `BRIDGE_LW_RELAY` · `BRIDGE_RNS_INPROTO_REPEAT`
(Bench-only: `BRIDGE_BENCH_AUTOSAVE` on the `bench_*` envs skips the captive portal — never in a release build.)

## Compatibility
`BridgeConfig` schema **v4 unchanged** — no NVS migration; v8.2.x configs load as-is. LR1121 / co-processor code remains out of scope.

## Downloads (build at tag time)
- **`xiao-dual-sx1262-v8.3-vanilla-factory.bin`** — full image, flash `@ 0x0` (fresh/erased device → captive portal).
- **`xiao-dual-sx1262-v8.3-app.bin`** — app image, flash `@ 0x10000`.

Full notes: [CHANGELOG.md](CHANGELOG.md) · Design: [V8.3-SPEC.md](V8.3-SPEC.md) · Bench protocol: [BENCH-v8.3.md](BENCH-v8.3.md). Flashing instructions: see the [v8.2 release](https://github.com/GrayHatGuy/Xiao-esp32s3-lora-repeater/releases/tag/v8.2).

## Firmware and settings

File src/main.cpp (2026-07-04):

/**
 * main.cpp
 * ========
 * Dual Wio SX1262 cross-protocol LoRa bridge for the XIAO ESP32S3.
 *
 *   R1/R2 = SX1262 on the shared XIAO SPI bus (WioSX1262).
 *
 * Bridge logic (RX-priority pipeline, V8.2-SPEC.md): each radio's RX is
 * repeated to the OTHER radio with the existing cross-protocol translation —
 * the historical R1<->R2 crossover. A received packet is decoded ONCE into a
 * clean body, run through the content-hash loop/dup guard, re-encoded for the
 * destination protocol and PUSHED onto that destination's RouteQueue; the
 * destination radio's task is the only thing that pops, CAD-gates, and
 * transmits — so a slow TX never blocks any radio's RX.
 *
 * Loop prevention no longer uses a prepended "[MT]/[MC]/[rns]" marker: the far
 * side receives the CLEAN body. DedupCache remembers the content hash of every
 * packet received AND every packet emitted, so an echo of our own emission (or
 * a mesh-flood replay, or the same packet heard twice) is dropped by hash.
 *
 * All LoRa RF settings (frequency, BW, SF, CR, power, sync word) are resolved
 * at runtime from BridgeConfig (NVS / captive portal). The platformio.ini
 * LORA_RADIO*_* build flags only seed first-boot defaults.
 */

#include <Arduino.h>
#include <SPI.h>
#include <stdint.h>
#include <stdarg.h>
#include "WioSX1262.h"
#include "MeshDecoderDebug.h"
#include "MeshEncoderDebug.h"
#include "LoRaWANCrypto.h"     // ABP: AES-CMAC + LoRaWAN ABP uplink encoder
#include "LoRaWANConfig.h"     // ABP P2: per-source ABP device table + NVS FCnt
#include "MeshCoreConfig.h"
#include "MeshtasticConfig.h"
#include "BridgeConfig.h"
#include "CaptivePortal.h"
#include "NodeDB.h"
#include "DedupCache.h"        // content-hash loop/dup guard (replaces marker)
#include "RouteQueue.h"        // per-destination outbound queue
#include "VirtualNodeMap.h"    // MC->MT source-identity (virtual MT nodes)
#include "RegionPreset.h"
#include "LoraConfigCheck.h"   // compile-time validation of LORA_RADIO* flags
#include "UartLink.h"          // inter-XIAO UART crossover transport (v8.5)
#include "RemoteRadio.h"       // R3/R4 = SX1262 on the second XIAO over the link
#include "SerialLog.h"         // one serialized console path (anti-garble)
#include "CamC2.h"             // LoRaCam C2 codec (role-gated; empty in stock builds)
#include "CameraNode.h"        // LoRaCam Phase 2: OV2640 capture (gated BRIDGE_ROLE_CAMERA)
#include "CamPortal.h"         // LoRaCam Phase 3: always-on web portal (gated BRIDGE_ROLE_CAMERA)
#include <esp_mac.h>

// Build a LoraConfig for one radio (index 0..NUM_RADIOS-1) from the live
// BridgeConfig. For a remote radio (R3/R4) it is carried to the co-processor in
// the CFG_RADIO frame; tcxoVoltage is then a no-op (the co-proc owns its TCXO).
static LoraConfig makeLoraConfig(int radio)
{
    LoraConfig c;
    c.frequency    = BridgeConfig::radioFrequency(radio);
    c.bandwidth    = BridgeConfig::radioBandwidth(radio);
    c.spreadFactor = BridgeConfig::radioSf(radio);
    c.codingRate   = BridgeConfig::radioCr(radio);
    c.syncWord     = BridgeConfig::radioSyncWord(radio);
    c.txPower      = BridgeConfig::radioTxPower(radio);
    c.preambleLen  = LORA_PREAMBLE_LEN;
    c.tcxoVoltage  = LORA_TCXO_VOLTAGE;     // Wio SX1262 module property
    return c;
}

// Derive a unique default Meshtastic node ID from the ESP32 MAC so every
// vanilla device is distinct out of the box (v8 spec §5). Called on first
// boot only; the captive-portal SSID follows automatically since it keys off
// mtNodeId(). The user can still override identity in the portal.
static void deriveMacIdentity()
{
    uint8_t mac[6] = {0};
    esp_read_mac(mac, ESP_MAC_WIFI_STA);
    uint32_t id = ((uint32_t)mac[2] << 24) | ((uint32_t)mac[3] << 16) |
                  ((uint32_t)mac[4] << 8)  |  (uint32_t)mac[5];
    char idStr[12];
    snprintf(idStr, sizeof(idStr), "!%08lx", (unsigned long)id);
    BridgeConfig::setMtNodeId(id);
    BridgeConfig::setMtNodeIdStr(idStr);

    // Derive the display names from the per-device node ID too (owner request,
    // v8.4.1): long name "<ID-hex> LoRa Bridge", short name "BR" + the ID's low
    // byte — so a fresh board shows e.g. "1DE9DC80 LoRa Bridge" / "BR80" instead
    // of the shared build-flag default. The user can still override both.
    char longName[BridgeConfig::MT_LONG_NAME_MAX + 1];
    snprintf(longName, sizeof(longName), "%08lX LoRa Bridge", (unsigned long)id);
    char shortName[BridgeConfig::MT_SHORT_NAME_MAX + 1];
    snprintf(shortName, sizeof(shortName), "BR%02lX", (unsigned long)(id & 0xFFu));
    BridgeConfig::setMtLongName(longName);
    BridgeConfig::setMtShortName(shortName);

    Serial.printf("[setup] MAC-derived identity: 0x%08lX (%s) \"%s\" / \"%s\"\n",
                  (unsigned long)id, idStr, longName, shortName);
}

// ============================================================
//  Shared SPI bus
//  XIAO ESP32S3 default SPI: SCK=GPIO7(D8), MOSI=GPIO9(D10),
//                             MISO=GPIO8(D9)
// ============================================================
#define SPI_SCK   7   // D8
#define SPI_MOSI  9   // D10
#define SPI_MISO  8   // D9

// Use the board-level SPI object so XIAO's variant pin mapping is
// already in effect.  A separate SPIClass(HSPI) instance re-enters
// spi_bus_initialize with default ESP32-S3 pins until begin() is
// called, introducing a window where both MOSI/MISO are wrong.
#define spi SPI

// ============================================================
//  Radio 1 — Wio SX1262 via 40-pin B2B header
//  GPIOs 38–42 are only accessible via the B2B connector.
// ============================================================
// Radio 1 is always the B2B-connector SX1262 — fixed silicon, never remapped.
#define R1_NSS      41  // SPI chip-select  (B2B / A11)
#define R1_DIO1     39  // IRQ              (B2B)
#define R1_RESET    42  // Reset            (B2B / A12)
#define R1_BUSY     40  // Busy             (B2B)
#define R1_ANT_SW   38  // Antenna switch   (B2B)

// ============================================================
//  Radio 2 — Wio SX1262 for XIAO via perimeter (edge) header pins
//  ----------------------------------------------------------------
//  WARNING: the Seeed "Wio-SX1262 for XIAO" edge module CHANGED its
//  pinout between silkscreen revisions. Read the silkscreen on YOUR
//  Radio-2 module and build the matching variant:
//     V1.0 -> env xiao_esp32s3       (default; NSS on D4 / GPIO5)
//     V1.1 -> env xiao_esp32s3_v1_1  (-DWIO_SX1262_REV=11; NSS on D3 / GPIO4)
//  The module's RIGHT-column silkscreen order (top -> bottom) sockets
//  onto the XIAO digital pins D0..D6, so each signal lands on the XIAO
//  pin at the same position:
//     V1.0: D0,   DIO1, RST,  BUSY, NSS,  RF_SW, D6
//     V1.1: DIO1, BUSY, RST,  NSS,  RF_SW, D5,    D6
//  XIAO ESP32S3 D-pin map: D0=GPIO1 D1=GPIO2 D2=GPIO3 D3=GPIO4 D4=GPIO5 D5=GPIO6
//  Each R2_* is #ifndef-guarded, so a single -DR2_NSS=.. (etc.) can also
//  override one pin from platformio.ini without editing this file.
// ============================================================
#ifndef WIO_SX1262_REV
  #define WIO_SX1262_REV 10          // 10 = V1.0 (default), 11 = V1.1
#endif

#if WIO_SX1262_REV == 11
  // ---- Wio-SX1262 for XIAO  V1.1 ----
  #ifndef R2_NSS
    #define R2_NSS    4   // NSS   chip-select  (D3 / GPIO4)
  #endif
  #ifndef R2_DIO1
    #define R2_DIO1   1   // DIO1  IRQ          (D0 / GPIO1)
  #endif
  #ifndef R2_RESET
    #define R2_RESET  3   // RST   reset        (D2 / GPIO3)
  #endif
  #ifndef R2_BUSY
    #define R2_BUSY   2   // BUSY  busy         (D1 / GPIO2)
  #endif
  #ifndef R2_ANT_SW
    #define R2_ANT_SW 5   // RF_SW antenna sw   (D4 / GPIO5)
  #endif
  #define WIO_SX1262_REV_STR "V1.1"
#else
  // ---- Wio-SX1262 for XIAO  V1.0 (canonical — the original v8.x map) ----
  #ifndef R2_NSS
    #define R2_NSS    5   // NSS   chip-select  (D4 / GPIO5)
  #endif
  #ifndef R2_DIO1
    #define R2_DIO1   2   // DIO1  IRQ          (D1 / GPIO2)
  #endif
  #ifndef R2_RESET
    #define R2_RESET  3   // RST   reset        (D2 / GPIO3)
  #endif
  #ifndef R2_BUSY
    #define R2_BUSY   4   // BUSY  busy         (D3 / GPIO4)
  #endif
  #ifndef R2_ANT_SW
    #define R2_ANT_SW 6   // RF_SW antenna sw   (D5 / GPIO6)
  #endif
  #define WIO_SX1262_REV_STR "V1.0"
#endif

// ============================================================
//  FreeRTOS configuration
// ============================================================
// Radio task stack. 8192 since the NodeDB landed: ingestAndFanout() can nest
// extractMeshtasticNodeInfo (240 B pt + AES ctx ~280 B) under body[256] plus
// enqueueTextForDest's outPkt[256], and the fragmented-RNS path needs similar
// headroom. 8 KB leaves a comfortable margin; the ESP32-S3 has 512 KB SRAM.
#define BRIDGE_TASK_STACK  8192
#define BRIDGE_TASK_PRIO   2       // above idle, below system
#define BRIDGE_POLL_MS     1       // ms between RX polls

// ============================================================
//  Shared SPI mutex — created in setup(), passed to both radios
// ============================================================
SemaphoreHandle_t spiMutex = NULL;

// ============================================================
//  Radio table. R1/R2 are LOCAL (XIAO SPI, WioSX1262); R3/R4 are SX1262 on a
//  SECOND XIAO reached over the UART crossover (RemoteRadio over g_link).
//  Constructed in setup() once the mutex / SPI bus / link are ready. (v8.5)
// ============================================================
static constexpr int NR = 4;

LoraRadio   *g_radio[NR]        = { nullptr, nullptr, nullptr, nullptr };
RadioChannel g_chan[NR];
bool         g_radioEnabled[NR] = { false, false, false, false };
static const char *kTag[NR]     = { "R1", "R2", "R3", "R4" };

// Per-radio routing matrix (v8.5): g_routeMask[src] bit j set => a packet RX'd
// on radio src is bridged to radio j. Loaded from BridgeConfig in setup(); the
// default (R1<->R2) preserves the historical 2-radio crossover behaviour.
static uint8_t g_routeMask[NR]  = { 0, 0, 0, 0 };

// Inter-XIAO UART crossover link to the second board's SX1262 (R3/R4). Opened in
// setup() only when R3 or R4 is enabled, so a single-board build never touches
// Serial1. Pins/baud are build-flag overridable (wire D6/D7 CROSSED to the peer).
#ifndef BRIDGE_LINK_TX_PIN
  #define BRIDGE_LINK_TX_PIN 43        // D6 — to the peer's RX (its D7)
#endif
#ifndef BRIDGE_LINK_RX_PIN
  #define BRIDGE_LINK_RX_PIN 44        // D7 — from the peer's TX (its D6)
#endif
#ifndef BRIDGE_LINK_BAUD
  #define BRIDGE_LINK_BAUD   460800UL
#endif
static UartLink g_link(Serial1);

// ============================================================
//  RX-priority routing state (V8.2-SPEC.md)
//  ----------------------------------------------------------------
//  One outbound queue per destination radio. A source radio's task decodes,
//  de-duplicates and re-encodes a packet, then PUSHES the finished bytes onto
//  the destination's queue and returns to RX. The destination radio's task is
//  the only one that pops + CAD-gates + transmits, one packet at a time, with a
//  non-blocking send. So a slow TX never blocks any radio's RX.
// ============================================================
RouteQueue g_routeQ[NR];

// Per-radio TX-scheduler state (owned by that radio's task).
static bool                g_txBusy[NR]         = { false, false, false, false };
static uint32_t            g_txStartMs[NR]      = { 0, 0, 0, 0 };
static uint32_t            g_txBackoffUntil[NR] = { 0, 0, 0, 0 };
static uint32_t            g_nextTxAllowedMs[NR]= { 0, 0, 0, 0 };  // airtime throttle
static bool                g_txPendingValid[NR] = { false, false, false, false };
static RouteQueue::Entry   g_txPending[NR];

// Route-queue depth (PSRAM-backed) and the max age past which a queued packet
// is dropped instead of delivered (stale mesh text isn't worth airtime).
#ifndef BRIDGE_ROUTE_QUEUE_DEPTH
  #define BRIDGE_ROUTE_QUEUE_DEPTH  64
#endif
#ifndef BRIDGE_ROUTE_MAX_AGE_MS
  #define BRIDGE_ROUTE_MAX_AGE_MS   30000UL
#endif

// CSMA random backoff after a busy CAD, and the upper bound on waiting for a
// non-blocking TX to report done before the scheduler force-recovers.
#ifndef BRIDGE_CAD_BACKOFF_MIN_MS
  #define BRIDGE_CAD_BACKOFF_MIN_MS 20
#endif
#ifndef BRIDGE_CAD_BACKOFF_MAX_MS
  #define BRIDGE_CAD_BACKOFF_MAX_MS 120
#endif
#ifndef BRIDGE_TX_INFLIGHT_TIMEOUT_MS
  #define BRIDGE_TX_INFLIGHT_TIMEOUT_MS 10000UL
#endif

// --- Full-mesh airtime throttle (V8.2-SPEC task #2) ------------------------
// Without a brake a busy mesh would let the bridge hog the channel. After each
// transmit we hold that radio off the air until its own emissions stay under a
// duty-cycle ceiling: a packet of on-air time A makes the next TX wait until
// A*100/DUTY after it started (so the radio is busy A and idle A*(100-DUTY)/
// DUTY). BRIDGE_TX_MIN_GAP_MS is an absolute floor on the post-TX gap.
// DUTY=100 + MIN_GAP=0 disables the throttle.
#ifndef BRIDGE_TX_DUTY_PERCENT
  #define BRIDGE_TX_DUTY_PERCENT  50
#endif
#ifndef BRIDGE_TX_MIN_GAP_MS
  #define BRIDGE_TX_MIN_GAP_MS    0
#endif

// --- Source-identity preservation (V8.2-SPEC.md §5) ------------------------
// Master switch: 1 = a bridged repeat preserves/reconstructs the original
// sender's identity (MC->MT virtual node, MT->MC name prefix); 0 = the clean-
// body / bridge-identity behaviour (the redesign default). The flags below are
// 0/1 literals used in plain `if`s so both code paths always compile and the
// behaviour is a build-flag flip, never a #ifdef'd-out function.
#ifndef BRIDGE_IDENTITY_PRESERVE
  #define BRIDGE_IDENTITY_PRESERVE 1
#endif
// 1 = tag the origin protocol so it is explicit after the repeat: "Alice@MT:"
// on MC, "Alice @MC" in the synthetic MT NodeInfo. 0 = bare name (looks native).
#ifndef BRIDGE_TAG_ORIGIN_PROTO
  #define BRIDGE_TAG_ORIGIN_PROTO 1
#endif
// MeshCore sender with no parseable "<name>: " prefix (Q3): 0 = fall back to
// the bridge's own identity (today's behaviour); 1 = a per-channel catch-all
// virtual node ("MC-<chan>").
#ifndef BRIDGE_MC_NONAME_VIRTUAL
  #define BRIDGE_MC_NONAME_VIRTUAL 0
#endif
// Longest MeshCore sender name we will parse out of a body prefix.
#ifndef BRIDGE_MC_NAME_MAX
  #define BRIDGE_MC_NAME_MAX 32
#endif

// ============================================================
//  Structured serial logging (V8.2-SPEC.md §13)
//  ----------------------------------------------------------------
//  A single greppable "ts=<ms> evt=<TAG> radio=<R1|R2> ..." key=val line per
//  pipeline event, emitted ATOMICALLY under a dedicated mutex so the two
//  core-pinned radio tasks can't interleave mid-line on the USB console (which
//  would shred the machine-parseable format). Kept separate from spiMutex so
//  logging never couples to the SPI critical sections. The heavy hex/protobuf
//  decoder dump (MeshDecoderDebug::print) stays its own multi-line block,
//  anchored by the preceding evt=RX line.
// ============================================================
static void blogf(const char *fmt, ...)
{
    char line[300];
    va_list ap;
    va_start(ap, fmt);
    vsnprintf(line, sizeof(line), fmt, ap);
    va_end(ap);
    // Share the one recursive console lock (SerialLog) so an evt= line never
    // interleaves with the multi-line decoder dump or a status print from the
    // other core-pinned task.
    SerialLog::lock();
    Serial.print(line);
    SerialLog::unlock();
}

// Short protocol tag for the proto= field.
static const char *protoTag(uint8_t sync)
{
    switch (sync) {
        case MeshDecoderDebug::SYNC_WORD_MESHTASTIC: return "MT";
        case MeshDecoderDebug::SYNC_WORD_MESHCORE:   return "MC";
        case MeshDecoderDebug::SYNC_WORD_RETICULUM:  return "RNS";
        case MeshDecoderDebug::SYNC_WORD_LORAWAN:    return "LW";
        default:                                     return "?";
    }
}

// Format a node id for a nodeid=/virtualid= field: "!<8hex>" when set, "-" when
// 0 (MeshCore / RNS have no per-sender id, so a bare 0 would mislead). `buf`
// must hold >= 10 bytes; returns buf for use as a %s argument.
static const char *fmtNodeId(uint32_t id, char *buf)
{
    if (id) snprintf(buf, 10, "!%08lx", (unsigned long)id);
    else    { buf[0] = '-'; buf[1] = 0; }
    return buf;
}

// ---- Bridge wall-clock estimate (for outbound MeshCore timestamps) ---------
// The bridge has no RTC/NTP (WiFi only comes up for the portal), so it learns
// the current Unix time opportunistically from any inbound protocol that carries
// a plausible timestamp — MeshCore GRP_TXT ts and Meshtastic POSITION_APP
// (Position.time field 4 / .timestamp field 7) — and stamps that (+ elapsed
// millis) onto outbound MC packets. Otherwise MC clients render the bridged
// message as 1969 (ts=0). volatile: written by either radio task, read by the
// other; display-only, so a rare torn read merely mis-stamps one message's time.
static volatile uint32_t g_clockUnix   = 0;   // last plausible Unix ts learned
static volatile uint32_t g_clockMillis = 0;   // millis() when it was captured

// Learn the wall-clock from a decoded packet timestamp. Ignores implausible
// values (0 / pre-2017) so a clockless sender can't poison the estimate. Logs
// once, when the clock is first calibrated (the useful event); silent after.
// `src` is the protocol tag for the one-time CLOCK log (MC / MT).
static inline void learnClock(uint32_t ts, const char *src) {
    if (ts <= 1500000000u) return;
    bool first = (g_clockUnix == 0);
    g_clockUnix   = ts;
    g_clockMillis = millis();
    if (first)
        blogf("ts=%lu evt=CLOCK src=%s unix=%lu (calibrated — MC TX now timestamped)\n",
              (unsigned long)millis(), src, (unsigned long)ts);
}
static inline void learnClockFromMc(uint32_t mcTs) { learnClock(mcTs, "MC"); }
static inline void learnClockFromMt(uint32_t mtTs) { learnClock(mtTs, "MT"); }

// Best estimate of the current Unix time, or 0 if none learned yet (a freshly
// booted bridge that hasn't yet heard a timestamped MC packet or an MT position
// still stamps 0 until the first calibration).
static uint32_t bridgeNowUnix() {
    uint32_t base = g_clockUnix;
    if (!base) return 0;
    return base + (millis() - g_clockMillis) / 1000u;
}

// Resolve one radio's channel into `out` from its protocol (sync word) and
// its BridgeConfig channel name/key strings.
static void resolveRadioChannel(uint8_t syncWord, const char *chName,
                                const char *chKey, RadioChannel &out)
{
    if (syncWord == MeshDecoderDebug::SYNC_WORD_MESHTASTIC) {
        MeshtasticConfig::resolve(chKey, chName, out);
    } else if (syncWord == MeshDecoderDebug::SYNC_WORD_MESHCORE) {
        MeshCoreConfig::resolve(chKey, chName, out);
    } else {
        // Reticulum or unknown — no channel key material.
        out.protocol    = syncWord;
        out.keyLen      = 0;
        out.channelHash = 0;
        memset(out.key, 0, sizeof(out.key));
        if (!chName) chName = "";
        strncpy(out.name, chName, sizeof(out.name) - 1);
        out.name[sizeof(out.name) - 1] = 0;
        Serial.printf("[radio] protocol 0x%02X — no channel key\n", syncWord);
    }
}
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
void loop()
{
#if defined(BRIDGE_CAM_COMMANDER) && defined(BRIDGE_C2_PEER_ID)
    // Bench commander: type a key in the serial monitor to send a signed C2 command
    // to the paired cam (BRIDGE_C2_PEER_ID), transmitted on R2 (the Custom 0x33 radio).
    //   s = snap photo    r = record 30 s    x = stop    g = get status
    //   m = send a T_MSG operator message (Phase 3 — fills the cam portal's ring)
    while (Serial.available()) {
        int c = Serial.read();
        if (c == 'm') {
            CamC2::sendMessage(1 /*R2*/, (uint32_t)(BRIDGE_C2_PEER_ID),
                               "bench msg from commander");
            continue;
        }
        uint8_t cmd = CamC2::CMD_NONE; uint8_t args[2]; size_t argLen = 0;
        switch (c) {
            case 's': cmd = CamC2::CMD_START_CAPTURE; break;
            case 'r': cmd = CamC2::CMD_RECORD; args[0] = 30; args[1] = 0; argLen = 2; break;
            case 'x': cmd = CamC2::CMD_STOP; break;
            case 'g': cmd = CamC2::CMD_GET_STATUS; break;
            default:  continue;   // ignore newlines / unmapped keys
        }
        CamC2::sendCommand(1 /*R2*/, (uint32_t)(BRIDGE_C2_PEER_ID), cmd,
                           argLen ? args : nullptr, argLen);
    }
#endif

    // Self-heal the co-processor link. The co-proc sends MSG_READY at every boot
    // and then sits idle until it receives CFG_RADIO. If it resets (brown-out,
    // re-flash, reseated cable) after we already configured it at startup, it
    // would otherwise stay silent until the HOST is rebooted. So whenever we see
    // a NEW READY (the generation count moved since we last configured it),
    // re-push each remote radio's CFG_RADIO + START_RX. The very first READY
    // after our own boot also lands here, which harmlessly re-sends config and
    // closes the boot-time race where setup() may have sent CFG before the
    // co-proc was listening. On a single-board build the link is never opened, so
    // readyGen() stays 0 and this is a no-op (do-no-harm). (v8.5)
    static uint32_t s_lastReadyGen = 0;
    uint32_t gen = g_link.readyGen();
    if (gen != s_lastReadyGen) {
        s_lastReadyGen = gen;
        int n = 0;
        for (int i = 2; i < NR; i++) {
            if (g_radioEnabled[i] && g_radio[i] && g_radio[i]->begin()) n++;
        }
        SerialLog::logf("[link] co-proc READY gen=%lu -> re-pushed config to %d "
                        "remote radio(s)\n", (unsigned long)gen, n);
    }

    vTaskDelay(pdMS_TO_TICKS(1000));
}

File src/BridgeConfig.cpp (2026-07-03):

// BridgeConfig.cpp — see BridgeConfig.h for design notes.

#include "BridgeConfig.h"

#include <Preferences.h>
#include <string.h>

// --- Build-flag defaults ---------------------------------------------------
// Values used on a fresh device (or after resetToDefaults). Mirror the
// BRIDGE_* / LORA_RADIO* macros in platformio.ini. As of v8 these are
// first-boot defaults only — the portal owns the live config.

#ifndef BRIDGE_MT_NODE_ID
  #define BRIDGE_MT_NODE_ID      0xB16B00B5u
#endif
#ifndef BRIDGE_MT_NODE_ID_STR
  #define BRIDGE_MT_NODE_ID_STR  "!b16b00b5"
#endif
#ifndef BRIDGE_MT_LONG_NAME
  #define BRIDGE_MT_LONG_NAME    "LoRa Bridge"
#endif
#ifndef BRIDGE_MT_SHORT_NAME
  #define BRIDGE_MT_SHORT_NAME   "BR"
#endif
#ifndef BRIDGE_MC_KEY_HEX
  #define BRIDGE_MC_KEY_HEX      "8b3387e9c5cdea6ac9e5edbaa115cd72"
#endif
#ifndef BRIDGE_MC_CHANNEL_NAME
  #define BRIDGE_MC_CHANNEL_NAME "public"
#endif
#ifndef BRIDGE_MT_CHANNEL_NAME
  #define BRIDGE_MT_CHANNEL_NAME "LongFast"
#endif
#ifndef BRIDGE_MT_PSK_B64
  #define BRIDGE_MT_PSK_B64      ""
#endif
#ifndef BRIDGE_MT_POSITION
  #define BRIDGE_MT_POSITION     1
#endif
#ifndef BRIDGE_MT_TELEMETRY
  #define BRIDGE_MT_TELEMETRY    1
#endif
// Per-radio protocol — needed to pick each radio's default channel + to
// migrate a v2 blob's protocol-specific channels into per-radio slots.
#ifndef LORA_RADIO1_SYNC_WORD
  #define LORA_RADIO1_SYNC_WORD  0x2B
#endif
#ifndef LORA_RADIO2_SYNC_WORD
  #define LORA_RADIO2_SYNC_WORD  0x12
#endif
// Per-radio RF — first-boot defaults for the v8 schema RF fields.
#ifndef LORA_RADIO1_FREQUENCY
  #define LORA_RADIO1_FREQUENCY      906.875f
#endif
#ifndef LORA_RADIO1_BANDWIDTH
  #define LORA_RADIO1_BANDWIDTH      250.0f
#endif
#ifndef LORA_RADIO1_SPREAD_FACTOR
  #define LORA_RADIO1_SPREAD_FACTOR  11
#endif
#ifndef LORA_RADIO1_CODING_RATE
  #define LORA_RADIO1_CODING_RATE    5
#endif
#ifndef LORA_RADIO1_TX_POWER
  #define LORA_RADIO1_TX_POWER       20
#endif
#ifndef LORA_RADIO2_FREQUENCY
  #define LORA_RADIO2_FREQUENCY      910.525f
#endif
#ifndef LORA_RADIO2_BANDWIDTH
  #define LORA_RADIO2_BANDWIDTH      250.0f
#endif
#ifndef LORA_RADIO2_SPREAD_FACTOR
  #define LORA_RADIO2_SPREAD_FACTOR  11
#endif
#ifndef LORA_RADIO2_CODING_RATE
  #define LORA_RADIO2_CODING_RATE    5
#endif
#ifndef LORA_RADIO2_TX_POWER
  #define LORA_RADIO2_TX_POWER       20
#endif
// Per-radio RF — first-boot defaults for the v8.5 R3/R4 slots (SX1262 on the
// second XIAO, reached over the UART crossover). R3/R4 default to PROTO_NONE
// (disabled) in loadDefaults(); these values only seed sane RF so a
// portal-enabled slot starts from a usable sub-GHz plan.
#ifndef LORA_RADIO3_SYNC_WORD
  #define LORA_RADIO3_SYNC_WORD      0x2B
#endif
#ifndef LORA_RADIO3_FREQUENCY
  #define LORA_RADIO3_FREQUENCY      906.875f
#endif
#ifndef LORA_RADIO3_BANDWIDTH
  #define LORA_RADIO3_BANDWIDTH      250.0f
#endif
#ifndef LORA_RADIO3_SPREAD_FACTOR
  #define LORA_RADIO3_SPREAD_FACTOR  11
#endif
#ifndef LORA_RADIO3_CODING_RATE
  #define LORA_RADIO3_CODING_RATE    5
#endif
#ifndef LORA_RADIO3_TX_POWER
  #define LORA_RADIO3_TX_POWER       20
#endif
#ifndef LORA_RADIO4_SYNC_WORD
  #define LORA_RADIO4_SYNC_WORD      0x12
#endif
#ifndef LORA_RADIO4_FREQUENCY
  #define LORA_RADIO4_FREQUENCY      910.525f
#endif
#ifndef LORA_RADIO4_BANDWIDTH
  #define LORA_RADIO4_BANDWIDTH      250.0f
#endif
#ifndef LORA_RADIO4_SPREAD_FACTOR
  #define LORA_RADIO4_SPREAD_FACTOR  11
#endif
#ifndef LORA_RADIO4_CODING_RATE
  #define LORA_RADIO4_CODING_RATE    5
#endif
#ifndef LORA_RADIO4_TX_POWER
  #define LORA_RADIO4_TX_POWER       20
#endif
// Global region — first-boot default. REGION_UNSET (0) until set in portal.
#ifndef BRIDGE_REGION
  #define BRIDGE_REGION              0
#endif

namespace BridgeConfig {

// v5 (v8.5): the radio table grows from 2 to NUM_RADIOS (4). R1/R2 are the
// local SX1262 on this XIAO; R3/R4 are the SX1262 on the second XIAO, reached
// over the UART crossover. Each slot gains a `routeMask` (which other radios it
// bridges its RX to — the configurable routing matrix) and the per-radio
// channel name/key now live IN the slot rather than in top-level r1/r2 fields.
// begin() migrates a v2/v3/v4 blob forward.
static constexpr uint8_t SCHEMA_VERSION = 5;

// Schema v2 — kept verbatim so a v2 blob (v6.1 build) can be migrated.
struct PersistedV2 {
    uint8_t  version;
    uint8_t  configured;
    uint8_t  positionEnabled;
    uint8_t  telemetryEnabled;
    uint32_t mtNodeId;
    char     mtNodeIdStr  [15 + 1];
    char     mtLongName   [39 + 1];
    char     mtShortName  [8  + 1];
    char     mcKeyHex     [32 + 1];
    char     mcChannelName[23 + 1];
    char     mtChannelName[23 + 1];
    char     mtPskBase64  [47 + 1];
};
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

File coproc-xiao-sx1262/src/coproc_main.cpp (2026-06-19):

/**
 * Xiao dual-SX1262 radio CO-PROCESSOR (v8.5 stage E)
 * ==================================================
 * Runs on the SECOND Xiao of a "2xiao_4sx1262" bridge. Drives its two local
 * SX1262 radios as the host's R3/R4, speaking the framed UART wire protocol in
 * ../src/LinkProtocol.h (shared verbatim with the host so the two ends never
 * drift) over the UART crossover.
 *
 * Protocol (host <-> co-proc):
 *   host  -> coproc : CFG_RADIO, TX, START_RX, PING, RESET
 *   coproc -> host  : RX (rssi/snr + bytes), TX_DONE, READY, LOG, PONG
 *
 * The radios are the SAME hardware as the host's R1/R2 (Wio SX1262 on the B2B
 * header + the "Wio-SX1262 for XIAO" edge module), so this reuses the proven
 * WioSX1262 driver (../src/WioSX1262.cpp) — including its DIO2/ANT_SW RF-switch
 * handling and the non-blocking TX trio. A CFG_RADIO re-tunes a radio at runtime
 * via WioSX1262::setConfig() + begin() (no reconstruction, so the static ISR
 * registration is preserved).
 *
 * TX is NON-BLOCKING: each MSG_TX is queued and dispatched one-at-a-time with
 * startTransmit() + the TxDone IRQ, so loop() keeps draining the UART during the
 * on-air time. CAD (scanChannel, listen-before-talk) gates every dispatch. The
 * host gates each MSG_TX on the MSG_TX_DONE we send back, so the queue normally
 * holds at most one job. Single-threaded — no locking needed.
 *
 * Console: native USB-CDC `Serial` is the debug console; the inter-board link is
 * `Serial1` on D6/D7. Define COPROC_PLAINTEXT_DEBUG to also echo LOG text to USB.
 *
 * Build/flash:  pio run -d coproc-xiao-sx1262 -e xiao_coproc_sx1262 -t upload --upload-port COMx
 */

#include <Arduino.h>
#include <SPI.h>
#include "WioSX1262.h"     // reused host driver (LoraRadio.h, RadioLib via -I ../src)
#include "LinkProtocol.h"  // shared wire protocol (single source of truth, -I ../src)

using namespace LinkProtocol;

static const size_t LORA_MAX = LORA_MAX_PACKET;   // 256

// --- Shared SPI bus — XIAO ESP32S3 default (same as the host) ----------------
#define SPI_SCK   7   // D8
#define SPI_MOSI  9   // D10
#define SPI_MISO  8   // D9

// --- Radio pin maps — identical hardware to the host R1/R2 -------------------
// Co-proc radio[0] = host R3 = the B2B-header SX1262 (fixed silicon).
#define CR3_NSS    41
#define CR3_DIO1   39
#define CR3_RESET  42
#define CR3_BUSY   40
#define CR3_ANT_SW 38

// Co-proc radio[1] = host R4 = the "Wio-SX1262 for XIAO" edge module. Its pinout
// changed between silkscreen revisions; pick the matching build env
// (xiao_coproc_sx1262 = V1.0 default, xiao_coproc_sx1262_v1_1 = V1.1).
#ifndef WIO_SX1262_REV
  #define WIO_SX1262_REV 10
#endif
#if WIO_SX1262_REV == 11
  #define CR4_NSS    4   // D3 / GPIO4
  #define CR4_DIO1   1   // D0 / GPIO1
  #define CR4_RESET  3   // D2 / GPIO3
  #define CR4_BUSY   2   // D1 / GPIO2
  #define CR4_ANT_SW 5   // D4 / GPIO5
  #define WIO_SX1262_REV_STR "V1.1"
#else
  #define CR4_NSS    5   // D4 / GPIO5
  #define CR4_DIO1   2   // D1 / GPIO2
  #define CR4_RESET  3   // D2 / GPIO3
  #define CR4_BUSY   4   // D3 / GPIO4
  #define CR4_ANT_SW 6   // D5 / GPIO6
  #define WIO_SX1262_REV_STR "V1.0"
#endif

// --- UART link to the host — Serial1 on D6/D7, wired CROSSED ------------------
#ifndef LINK_TX_PIN
  #define LINK_TX_PIN 43      // D6 — to the host's RX (its D7)
#endif
#ifndef LINK_RX_PIN
  #define LINK_RX_PIN 44      // D7 — from the host's TX (its D6)
#endif
#ifndef LINK_BAUD
  #define LINK_BAUD   460800UL
#endif
HardwareSerial &LinkSerial = Serial1;

// --- Two SX1262 radios: index 0 = R3, 1 = R4 --------------------------------
static SemaphoreHandle_t s_spiMutex = nullptr;
static WioSX1262        *g_radio[2]   = { nullptr, nullptr };
static bool              g_enabled[2] = { false, false };

// --- Non-blocking TX state ---------------------------------------------------
static bool     g_txActive[2]  = { false, false };   // a startTransmit() is outstanding
static uint32_t g_txStartMs[2] = { 0, 0 };
static const uint32_t TX_DONE_TIMEOUT_MS = 8000;     // belt-and-suspenders

struct TxJob { uint8_t data[LORA_MAX]; uint16_t len; };
static const int TX_Q_DEPTH = 4;   // host gates 1-in-flight, so this is slack
static TxJob   g_txq[2][TX_Q_DEPTH];
static uint8_t g_txqHead[2]  = { 0, 0 };
static uint8_t g_txqTail[2]  = { 0, 0 };
static uint8_t g_txqCount[2] = { 0, 0 };

static bool txqPush(int i, const uint8_t *d, size_t len) {
    if (len > LORA_MAX) len = LORA_MAX;
    if (g_txqCount[i] >= TX_Q_DEPTH) return false;
    TxJob &j = g_txq[i][g_txqTail[i]];
    memcpy(j.data, d, len);
    j.len = (uint16_t)len;
    g_txqTail[i] = (uint8_t)((g_txqTail[i] + 1) % TX_Q_DEPTH);
    g_txqCount[i]++;
    return true;
}
static TxJob *txqPeek(int i) { return g_txqCount[i] ? &g_txq[i][g_txqHead[i]] : nullptr; }
static void   txqPop(int i)  {
    if (!g_txqCount[i]) return;
    g_txqHead[i] = (uint8_t)((g_txqHead[i] + 1) % TX_Q_DEPTH);
    g_txqCount[i]--;
}

// --- Link TX helpers ---------------------------------------------------------
static void linkSend(uint8_t type, uint8_t radio, const uint8_t *payload, size_t len) {
    uint8_t frame[MAX_FRAME];
    size_t n = buildFrame(frame, sizeof(frame), type, radio, payload, len);
    if (n) LinkSerial.write(frame, n);
}
static void linkLog(const char *s) {
    linkSend(MSG_LOG, RADIO_NONE, (const uint8_t *)s, strlen(s));
#ifdef COPROC_PLAINTEXT_DEBUG
    Serial.println(s);
#endif
}
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

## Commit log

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2026-05-20 Persistent NodeDB & MT sender attribution
    MT->MC bridge marker now carries the sender's Meshtastic !<hex> ID and
    short_name learned from NODEINFO_APP packets:
    [MT !3d3a87a3 KN5J] body
    New NodeDB.{h,cpp}: 64-entry, NVS-persistent (nodeId -> short, long) table,
    LRU eviction, populated by a new extractMeshtasticNodeInfo() decoder in
    MeshDecoderDebug.h.
    Reliability fixes shaken out during integration:
    - Radio task stacks 4 KB -> 8 KB; saveToNvs scratch (~3.3 KB) moved off
    the stack into BSS. Fixes stack overflow on every received NodeInfo.
    - Bridge drops upserts of its own NodeInfo echoing back via relays.
    - NodeDB opens NVS namespace in RW mode on first boot to silence the
    cold-boot nv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
    [MeshDecoderDebug.h, NodeDB.cpp, main.cpp]
2026-05-20 v6.0 - captive-portal config, POSITION/TELEMETRY bridging, configurable MC channel
    Bundles features F2, F3 and F4.
    F4 - WiFi captive portal. On a fresh flash, or when BOOT is held within
    ~3s of reset, the bridge starts an open AP LoRa-Bridge-<XX> and
    DNS-redirects all HTTP to a config form: MT identity, MC key + channel
    name, POSITION/TELEMETRY toggles. New BridgeConfig.{h,cpp} is the NVS-
    backed single source of truth (namespace bridgecfg, schema v1). New
    CaptivePortal.{h,cpp} serves the form on WebServer + DNSServer. Build
    flags become first-boot defaults.
    F2 - POSITION_APP + TELEMETRY_APP decoded from MT and re-emitted to MC
    as compact text under the [MT !<hexid> <SHORT>] marker. New
    ex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
    [BridgeConfig.cpp, CaptivePortal.cpp, MeshCoreConfig.cpp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]
2026-05-20 F5 - Meshtastic private-channel support
    New MeshtasticConfig.{h,cpp} mirrors MeshCoreConfig: reads a base64 PSK +
    channel name from BridgeConfig, runs Meshtastic key expansion (empty ->
    LongFast, 1-byte short key, 16-byte AES-128, 32-byte AES-256) and derives
    the on-air channel hash as XOR-fold(name) ^ XOR-fold(key).
    The five MT decoders and two MT encoders now read MeshtasticConfig::key /
    keyLen / channelHash instead of the hard-coded MESHTASTIC_DEFAULT_KEY /
    MESHTASTIC_LONGFAST_CHANNEL_HASH constants; setkey_enc takes keyLen*8 so
    AES-256 channels decrypt.
    BridgeConfig schema bumped v1 -> v2 (mtChannelName, mtPskBase64); a v1
    NVS blob is migrated forward automatically. Captive portal gain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
    [BridgeConfig.cpp, CaptivePortal.cpp, MeshDecoderDebug.h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]
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2026-05-20 v6.2.1 - build reproducibility + GPIO init fix
    Pin platform to espressif32 @ 6.13.0 (arduino-esp32 2.0.17), the core the bridge is verified against. An unpinned platform let fresh checkouts pull a newer core with divergent GPIO/SPI behaviour.
    busyWait pre-flight diagnostic now calls pinMode INPUT on the BUSY pin before digitalRead, silencing the IO-not-set-as-GPIO error that newer arduino-esp32 cores logged on each read.
    Neither change alters bridge behaviour.
    [main.cpp]
2026-05-20 v7.0 - per-radio channels, same-protocol relay
    Each radio slot now carries its own protocol AND channel. The bridge relays cross-protocol MT<->MC and same-protocol MC<->MC / MT<->MT (private<->public, private<->private).
    New RadioChannel struct (protocol, key, keyLen, channelHash, name) - two instances, one per radio, resolved at boot. MeshCoreConfig / MeshtasticConfig are now stateless resolve() helpers instead of singletons. Every decoder and encoder takes a const RadioChannel&; bridgePacket decodes with the RX radios channel and encodes with the TX radios channel.
    BridgeConfig schema v2->v3: protocol-specific channel fields become per-radio (radio1/2ChannelName + radio1/2ChannelKey); a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
    [BridgeConfig.cpp, CaptivePortal.cpp, MeshCoreConfig.cpp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]
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2026-05-21 Add compile-time validation of LORA_RADIO* build flags
    New LoraConfigCheck.h: static_assert guards that reject an invalid
    LORA_RADIO* build-flag default at compile time, so a bad flag fails
    `pio run` with a clear message instead of shipping misbehaving
    firmware. Each guard is #ifdef-wrapped, so unset flags (the vanilla
    .bin case) are skipped.
    Checks: frequency 150-960 MHz, bandwidth a valid SX1262 value, SF
    5-12, CR 5-8, TX power -9..22 dBm. Sync word is byte-range only
    (0x00-0xFF), not a whitelist, since the v8 Custom protocol path
    allows any sync word.
    Complements v8's portal-side runtime validation in handleSave():
    this checks compile-time defaults, the portal checks portal-entered
    valu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
    [main.cpp]
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2026-06-13 feat(radio): LoraRadio interface + WioSX1262 non-blocking TX/CAD; pin RadioLib 7.7.0
    Backport of the RX-priority radio layer from T_LORA_QUAD_ROUTE (V8.2-SPEC §3,
    §4). The keystone of the redesign: a TX that no longer blocks RX.
    - New src/LoraRadio.h: abstract radio interface + the shared LoraConfig struct
    and compile-time board constants (moved out of WioSX1262.h). Default CSMA
    methods fall back to the blocking path so any non-overriding wrapper still
    works. (Carries the inert LR1121_TCXO_VOLTAGE constant for parity with the
    quad line; unused in this SX1262-only build.)
    - WioSX1262 now implements LoraRadio and adds the non-blocking TX/CAD trio:
    scanChannel() (listen-before-talk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
    [WioSX1262.cpp]
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2026-06-13 fix(nodedb): internal mutex + copy-based lookupShortName
    Backport from T_LORA_QUAD_ROUTE (V8.2-SPEC §2 A3). v8.1 assumed only the
    Meshtastic-side task touches NodeDB; the RX-priority pipeline and the identity
    layer both read it from more than one task, so:
    - All public functions take an internal mutex created in begin().
    - lookupShortName() is now copy-based — lookupShortName(id, out, outCap)
    returning bool — instead of returning a pointer into the table, so the
    result stays valid if another task mutates the table concurrently.
    The lone v8.1 call site (buildTextSrcMarker) is updated to the new signature so
    this commit builds green; that function is removed entirely when the pipeli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
    [NodeDB.cpp, main.cpp]
2026-06-13 feat(bridge): RX-priority pipeline rewrite (NR=2, clean bodies)
    Replaces the v8.1 blocking bridgePacket() crossover with the T_LORA_QUAD_ROUTE
    RX-priority pipeline, adapted to the 2-radio dual-SX1262 main line (V8.2-SPEC
    §3, §8 step 4). Functional parity with the branch at 2 radios; identity layer
    lands next.
    - ingestAndFanout(): decode ONCE into a clean body (+ MT srcId), run the
    content-hash loop/dup guard (DedupCache), then re-encode for the OTHER radio
    and PUSH onto its RouteQueue. No transmit on the RX path -> the source radio
    returns to RX immediately.
    - Generic radioTask(i): (A) service in-flight non-blocking TX with a 10 s
    safety-timeout recovery, (B) RX drain (read, re-ar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
    [main.cpp]
2026-06-13 feat(identity): cross-protocol source-identity (MC->MT virtual node, MT->MC prefix)
    The core of the v8.2 identity-preservation layer (V8.2-SPEC §5.3/§5.4) — the
    answer to "make a bridged repeat carry the original sender's id/protocol."
    Cross-protocol is the hard case the owner called out; same-protocol raw-repeat
    follows in the next commit.
    - New VirtualNodeMap: deterministic virtual MT node id = FNV-1a32("MC|" + name),
    nudged out of MT reserved ranges and off the bridge's own id. 32-entry LRU,
    RAM-only, used purely to rate-limit synthetic NodeInfo. Same MC sender -> same
    MT node across reboots and across bridges.
    - MC -> MT: parse the MeshCore "<name>: <text>" body convention, mi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
    [main.cpp]
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2026-06-13 feat(log): structured tagged serial schema + log mutex
    Implements the V8.2-SPEC §13 logging schema (owner Q1). Replaces the ad-hoc
    "[ms][tag] ..." prose lines on the runtime pipeline with a single greppable,
    machine-parseable line per event, emitted atomically across the two cores.
    - blogf(): vsnprintf into a line buffer, then one mutex-guarded Serial.print so
    a whole line lands without interleaving. logMutex is created first thing in
    setup() and is separate from spiMutex (logging never couples to SPI).
    - Format: "ts=<ms> evt=<TAG> radio=<R1|R2> ..." with only the keys valid at the
    stage. evt = RX / DEDUP_PASS / DROP / QUEUE / CAD / TX_START / TX_DONE /
    THROTTLE / NODEDB / NODEINFO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
    [main.cpp]
2026-06-13 fix(bridge): expire a latched TX packet that ages past max-age under CAD-busy
    Adversarial review (PARTIAL-confirmed, low) finding: RouteQueue::pop() only
    prunes stale entries at pop time. A packet popped into the g_txPending[] latch
    just under BRIDGE_ROUTE_MAX_AGE_MS could then age past it while a sustained
    CAD-busy channel kept the latch waiting, and would eventually transmit STALE —
    violating the "stale mesh text is not worth airtime" policy. (Not an indefinite
    stall: RX, NodeInfo and CAD re-attempts keep running and the system self-heals
    on the next pop; only the single latched packet was at risk.)
    Re-check the latched packet's age right after the pop, using the SAME unsigned
    age compa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
    [main.cpp]
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2026-06-14 fix(meshcore): stamp a learned wall-clock on outbound MC packets (was 1969)
    MeshCore GRP_TXT carries a 4-byte Unix ts that MC clients display. MT->MC (and
    RNS->MC) hardcoded ts=0, so bridged messages showed as 1969-12-31 on the MC
    side. MC->MT was fine because Meshtastic clients timestamp on receipt.
    The bridge has no RTC/NTP, so it LEARNS wall-clock from inbound MeshCore packets
    (which carry a valid ts) and stamps that estimate (+ elapsed millis) onto
    outbound MC packets:
    - extractMeshCoreBody() gains an optional tsOut (the GRP_TXT plaintext ts).
    - ingestAndFanout learns it via learnClockFromMc() on each decoded MC packet
    (ignores implausible <2017 values; logs a one-time evt=CLOCK when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
    [MeshDecoderDebug.h, main.cpp]
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2026-06-14 feat(clock): learn wall-clock from Meshtastic POSITION_APP time
    Carries over the v8.2.1 follow-up. The bridge has no RTC/NTP and so far
    only learned wall-clock from inbound MeshCore timestamps, leaving a
    cold-boot window where MT->MC packets stamp 1969 until the first
    timestamped MeshCore packet arrives. A decoded Meshtastic POSITION_APP
    now also calibrates the clock.
    - MeshDecoderDebug.h: MeshtasticPositionInfo gains hasTime/timeUnix;
    extractMeshtasticPosition parses Position.time (field 4, fixed32 -
    authoritative) and falls back to .timestamp (field 7, fixed32, the GPS
    solution time). hasTime is deliberately not part of the return gate, so
    a coord-less position is still not bridge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
    [MeshDecoderDebug.h, main.cpp]
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2026-06-14 feat(lorawan): captive-portal LoRaWAN protocol option
    Adds "LoRaWAN" to the per-radio protocol picker. The form shows channel
    name, frequency, TX power, and BW/SF/CR (LoRaWAN needs RF tuning to the
    target channel); it hides the channel key (keyless) and the sync-word
    field (fixed at 0x34, like MeshCore's 0x12). updAll() gains the '5'->'lw'
    visibility token + a frequency hint. syncForProtocol(PROTO_LORAWAN)=0x34.
    applyRadio reads BW/SF/CR for LoRaWAN and pins sync 0x34 with no channel
    key - via an explicit branch so PROTO_LORAWAN no longer falls into the
    Reticulum default (which would have clobbered BW/SF/CR and set sync 0x42).
    V8.3-SPEC section 8 (LW-Q1/Q4).
    Build green (pio run -e xiao_esp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
    [CaptivePortal.cpp]
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2026-06-14 fix(lorawan): review nits - FCtrl printf cast + protocol-neutral RF hint
    Adversarial multi-agent review (5 dimensions, 26 agents) of the
    main..v8.3-dev diff: 21 findings raised -> 2 confirmed (both cosmetic
    nits), 19 refuted. Parser bounds-math, loop-safety/dedup, the
    g_mcClock*->g_clock* rename, and the portal validator all verified clean;
    no functional bugs.
    - printLoRaWAN: cast m.fctrl to (unsigned) for the %02X specifier
    (strict-conformance signedness; output was already correct for 0..255).
    - CaptivePortal: the BW/SF/CR hint hard-coded "MeshCore:" but that block
    is now also shown under LoRaWAN - made the hint protocol-neutral.
    - CLAUDE.md: record the review result.
    Build green (pi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
    [CaptivePortal.cpp, MeshDecoderDebug.h]
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2026-06-14 fix(lw-frame-gen): park Radio 2 CS so Radio 1 is detected (rc=-2)
    The dual-SX1262 board shares one SPI bus; the generator set up only Radio 1, leaving Radio 2's chip-select (GPIO5) floating -> Radio 2 drove MISO and Radio 1's begin() returned RADIOLIB_ERR_CHIP_NOT_FOUND (-2). Park GPIO5 HIGH before probing Radio 1, mirroring the bridge's WioSX1262 constructor.
    [main.cpp]
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2026-06-14 feat(bench): BRIDGE_BENCH_AUTOSAVE — bench envs skip the captive portal
    An erased board is unconfigured, and the firmware forces the captive portal (won't bridge until Saved once) — so every bench-env flash required a WiFi portal Save. Gated by BRIDGE_BENCH_AUTOSAVE (added to all 8 bench envs; never in release): on first boot main.cpp persists the build-flag defaults via BridgeConfig::save(), so the board comes straight up configured and skips the portal. The 5s BOOT/serial window still reaches the portal on demand. Release env (xiao_esp32s3) excludes the #ifdef and is unaffected; both build green.
    [main.cpp]
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2026-06-15 feat(lorawan): v8.3.1 P1 — AES-CMAC + ABP uplink encoder + seam (B1/M1)
    Mint valid LoRaWAN 1.0.x ABP Data-Up frames so a raw-LoRa/MT/MC source can be
    ingested by a ChirpStack LNS (V8.3.1-SPEC P1). Owner decisions locked: raw-LoRa
    Fork B, delivery B1 (RF re-emit, no WiFi), device model M1 (per-source).
    src/LoRaWANCrypto.h (new):
    - Self-contained RFC 4493 AES-CMAC over mbedtls_aes_* — mbedtls_cipher_cmac is
    compiled OUT of the prebuilt esp32s3 lib (CONFIG_MBEDTLS_CMAC_C off, A4), so
    it won't link; this is the only new crypto primitive v8.3.1 needs.
    - encodeUplink(): AES-CTR FRMPayload (A_i keystream) + CMAC MIC over B0|msg,
    ADR=0, Unconfirmed, FCnt low-16 in FHDR / full-32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
    [LoRaWANCrypto.h, main.cpp]
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2026-06-15 fix(host): Radio-2 V1.0/V1.1 module-revision variants + bring-up hardening
    The Seeed "Wio-SX1262 for XIAO" edge module (Radio 2) ships in two pinouts:
    NSS is on D4/GPIO5 on V1.0 but D3/GPIO4 on V1.1. v8.x only shipped the V1.0
    map, so on a V1.1 module Radio 2's real chip-select floats during Radio 1's
    begin(), drives the shared MISO, and Radio 1 fails to detect (CHIP_NOT_FOUND,
    -2) -> FATAL halt. Reproduced on one board, not another, with the same wiring.
    - Per-revision build variants via WIO_SX1262_REV (10=V1.0 default, 11=V1.1):
    env xiao_esp32s3 (V1.0, NSS=5, unchanged) and xiao_esp32s3_v1_1 (V1.1,
    NSS=4 DIO1=1 RST=3 BUSY=2 RF_SW=5 -- silkscreen-correct, bench-confirmed on a
    physica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
    [main.cpp]
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2026-06-16 feat(lorawan): v8.4 P2 — per-source ABP creds (portal + NVS) + reboot-safe FCnt
    New src/LoRaWANConfig.{h,cpp}: a bounded per-source ABP identity table (M1, 4
    slots) persisted in its OWN NVS namespace ("lwabp"), independent of the
    BridgeConfig blob (no schema migration). Each device = {srcSel, srcMatch,
    DevAddr, NwkSKey, AppSKey, FPort}; resolve(srcProto, srcId) picks the best match
    (MT-node > protocol > ANY default). FCnt is per-device and reboot-safe via block
    reservation (one NVS write per 32 uplinks, not per packet).
    main.cpp: the ABP seam resolves a per-source NVS device first (persisted FCnt),
    falling back to the P1 build-flag identity (in-RAM FCnt); QUEUE log gains
    cred=nvs|flag. Lo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
    [CaptivePortal.cpp, LoRaWANConfig.cpp, main.cpp]
2026-06-16 feat(lorawan): v8.4 P3 — Custom raw-LoRa->ABP (weather station) + tag + codec
    - Shared enqueueAbpUplink() encodes any payload (decoded MT/MC text OR raw Custom
    bytes) as an ABP uplink; enqueueTextForDest now calls it.
    - Custom raw-LoRa source path (ingestAndFanout): a Custom-protocol RX whose dest
    is a LoRaWAN ABP encoder wraps the RAW received bytes as FRMPayload — the
    canonical raw-LoRa weather-station path. Dedup-guarded; logs no-lw-abp-dest.
    - Optional per-device source tag (Device.flags FLAG_TAG_SRC + portal checkbox):
    prepend [proto:1][srcId:4 LE] so a multiplexed ChirpStack device can demux.
    - Fix: LoRaWANConfig::resolve() received a sync word but matched PROTO_* enums,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
    [CaptivePortal.cpp, LoRaWANConfig.cpp, main.cpp]
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2026-06-16 fix(abp): reboot-safe DevAddr-keyed FCnt, fail-closed persist, build-flag counter
    Pre-bench review fixes for the v8.4 ABP encoder (silent-replay class):
    #1 FCnt persisted by DevAddr (fc_<addr>) instead of slot index, so an identity
    keeps its high-water across portal row moves / clear+re-add. setDevice() now
    re-seeds a slot's counter from the new DevAddr's persisted high-water.
    #3 Fail-closed reserve-before-issue: advanceFcnt() persists the next reservation
    BEFORE issuing the first value of a block and verifies the NVS write; on a
    begin()/putUInt failure it returns FCNT_INVALID (caller drops) rather than
    emitting a counter that is not durably reserved (a reboot could replay it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
    [LoRaWANConfig.cpp]
2026-06-16 fix(abp): self-test gate, clean drops for FCnt/overflow, proto-tag enum
    Encode-seam half of the pre-bench review fixes:
    #2 Latch LoRaWANCrypto::selfTest() into g_lwCryptoOk; enqueueAbpUplink refuses to
    emit (drop=lw-selftest-fail) if the on-device crypto KATs failed, instead of
    minting wrong-MIC frames the LNS silently drops. Default true when the
    self-test is compiled out (behaviour unchanged).
    #3 Drop on FCNT_INVALID (drop=lw-fcnt-fail) from the new fail-closed counter.
    #4 Build-flag fallback now calls nextFcntForDevAddr(); boot warns if the build-flag
    DevAddr collides with a provisioned device.
    #5 Stamp LoRaWANConfig::protoOf(sync) (1/2/3/4/5) into the [proto][srcId] tag, not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
    [main.cpp]
2026-06-16 docs(abp): tier the bench by HW (DUT/synthetic-LNS/ChirpStack) + sniffer env + offline verifier
    Restructure BENCH-v8.4.md so the encoder can be validated without a real LNS, and
    split tests across the two rigs (3 bridges + no ChirpStack vs colleague's ChirpStack).
    - Three tiers: A (DUT serial only), B (a 2nd bridge as a keyless "synthetic LNS"
    sniffer + offline verify), C (real ChirpStack). Per-test HW / flash / CLI / pass-fail.
    - New [env:bench_lw_sniffer]: keyless LoRaWAN capture on 903.9 + full-frame hex.
    - New BRIDGE_LW_CAPTURE_HEX flag (default 0, do-no-harm): logs evt=LWRAW raw=<hex>
    so a captured frame can be verified off-box.
    - New tools/lw-verify.py: validates MIC + decrypts FR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
    [lw-verify.py, main.cpp]
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2026-06-16 feat(abp): boot pre-flight echo of the ABP identity + BENCH config-check section
    So a board's setup can be confirmed on serial before testing (avoids a wasted run):
    - main.cpp: under BRIDGE_LW_ENCODE, print one line at boot —
    [lw-enc] ABP encoder ON - build-flag creds ready=N DevAddr=0x.. FPort=..; NVS devices configured=N
    Keys are never printed. Do-no-harm: compiled out of stock/sniffer builds.
    - BENCH-v8.4.md: new "Pre-flight config check" section with the exact expected boot
    lines per env (selftest, [lw-enc], [BridgeConfig] region + radioN RF sync/freq/BW/SF),
    a per-env expected-value table, and the open-monitor-then-RST tip.
    Build-green: xiao_esp32s3 (do-no-harm), bench_lw_enc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
    [main.cpp]
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2026-06-17 chore(portal): TODO - auto-fill RF defaults on protocol switch
    When a radio's Protocol dropdown changes (e.g. MT<->MC), the form keeps the prior
    protocol's freq/BW/SF/CR and channel key stale, forcing a hand re-entry of every
    field. This caused a real bench error: switching R1 to MeshCore left the freq stale,
    it got retyped as 910.575 vs the correct 910.525 (50 kHz off) -> demods just enough
    to fail CRC (rx-error rc=-7) -> a long debug detour. Documents the fix (auto-fill the
    new proto's defaults, guarded against clobbering a user-entered custom value) in
    appendScript()/upd(n). Comment-only, no behavior change.
    [CaptivePortal.cpp]
2026-06-17 feat(portal): auto-fill RF defaults on protocol switch
    Switching a radio's Protocol dropdown kept the prior protocol's freq/BW/SF/CR
    and channel key stale, forcing hand re-entry of every field -- which caused a
    real bench slip (R1->MeshCore left the freq, retyped 910.575 vs 910.525, 50 kHz
    off -> rx-error rc=-7). upd(n) now fills the new protocol's defaults on an actual
    dropdown change (tracked via LASTP, parameterized per radio), guarded so a value
    the user typed for the current protocol is never clobbered:
    - MeshCore: public key 8b3387..., 910.525 / BW62.5 / SF7 / CR5
    - Meshtastic: blank PSK (LongFast); freq stays preset-computed
    - Custom / LoRaWAN: left manual (community/channel-specific)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
    [CaptivePortal.cpp]
2026-06-17 test(gen): add 250 B oversize frame + oversize env for A3
    lw-frame-gen only emitted <=23 B canonical frames; A3 (over-cap drop, fix #6)
    needs a payload >242 B. Adds FRAME-OVERSIZE (250 B, command '6') and an
    `oversize` env (Custom sync 0xAB, 905.0/BW250/SF7) so the DUT (R1=Custom) routes
    the raw bytes into the ABP encoder, where 250 B > the 242 B FRMPayload cap ->
    drop=lw-payload-overflow. Build-green.
    [main.cpp]
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2026-06-18 feat(portal): LoRaWAN region/slot picker (CO-9/10/11) + ABP helper text (CO-15)
    CO-9/10/11: per-radio LoRaWAN Region + Channel-slot dropdowns (shown for LoRaWAN).
    - Regions US915/AU915 (FSB2), AS923, EU868 with real RP002-1.0.3 channel plans;
    picking region+slot auto-fills Frequency/SF/Bandwidth (still editable), CR fixed 5.
    - Region persisted per-radio in RadioRf.lwRegion (repurposed _pad[0]; struct size
    unchanged -> no schema bump, existing v4 NVS blobs load as region=unset).
    - New BridgeConfig::LwRegion enum + radioLwRegion()/setRadioLwRegion(); save path
    reads+clamps r{n}lwreg for LoRaWAN radios.
    CO-15: consolidated ABP-section hint (source list meaning, 4-slot purpose, minimum
    D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
    [BridgeConfig.cpp, CaptivePortal.cpp]
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2026-06-18 feat(portal): v8.4.1 UI refinements - node-ID-derived names + preset-driven channel name
    Owner pickups after eyeballing the portal:
    - Identity defaults now derive from the per-device node ID (deriveMacIdentity):
    long name '<ID-hex> LoRa Bridge', short name 'BR'+low byte
    (e.g. '1DE9DC80 LoRa Bridge' / 'BR80'), not the static B16B00B5/BR.
    - Meshtastic: Channel name follows the modem-preset name while the key is the
    default (AQ==/blank); preset change also refreshes freq/BW/SF/CR.
    - Channel name unlocks for editing once the key is changed from default -- MT
    (custom PSK) and MeshCore (custom key vs the public 8b... key). Channel-key
    field is now reactive (oninput) so the lock/unlock up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
    [CaptivePortal.cpp, main.cpp]
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2026-06-18 feat(portal): Reticulum autofills RNode defaults; prune redundant platformio.ini examples
    Portal: selecting Reticulum now auto-fills the RNode defaults (914.875 MHz / 125 kHz / SF8 / CR5) on the protocol-switch, mirroring the MeshCore autofill; replaced the region-mid 'band default' freq compute (which would have clobbered the autofill) with a guidance hint. All four stay editable.
    platformio.ini: removed the redundant commented example blocks (the MT/MC RF dups of the active defaults, the RNode block now in the portal, and the Global-LoRa / MeshCore-channel / per-portnum / Meshtastic-channel blocks - all documented in the user manual). Active R1/R2 defaults + the v8.4.1 scenario section sta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
    [CaptivePortal.cpp]
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
